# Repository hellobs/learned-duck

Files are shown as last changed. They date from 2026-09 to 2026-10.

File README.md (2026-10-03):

<div align="center">

# Learned Duck

**一台「被训练出来」的桌面蓝牙音箱**
*a desktop speaker that is **learned, not designed***

一条会发光的顶盖 · 一只黑色的眼 · 四条站得住的腿





</div>

<p align="center">
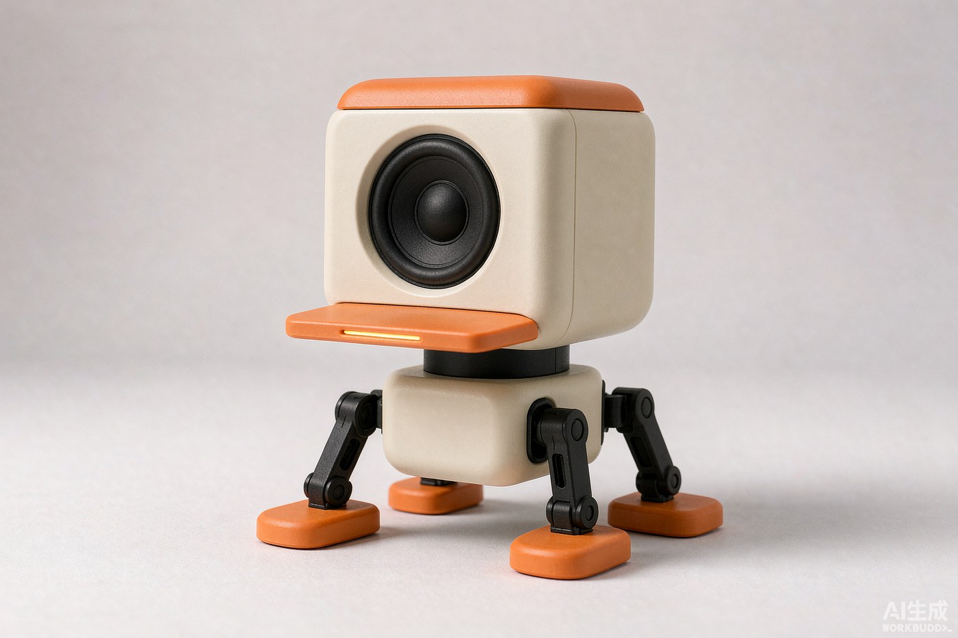
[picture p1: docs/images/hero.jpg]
Learned Duck
  
</p>

<p align="center"><sub>外观定稿 · 单喇叭版 · 暖奶油壳 ＋ 橙色顶盖与喙 ＋ 黑色四足</sub></p>

---

## 这是什么

Learned Duck 是一台可以放在桌面上的蓝牙音箱。它同时也是一个**完整的、可复现的 3D 打印产品设计项目**——从零件测绘、内部堆叠、外观建模，到打印参数、装配顺序、电路与固件，全部公开。

它的形态是一只抽象的小机器鸭：正面一只裸露的 52mm 全频喇叭充当唯一的「眼」，头顶一块橙色顶盖做成的浅托盘里，一条光带随音乐起伏（那是一条训练曲线，不是一张笑脸），四条带可见转轴关节的黑色机械腿把它从桌面上抬起来。

**它不是一个套壳的现成方案。** 所有零件都是从零开始测绘、从零开始排布、从零开始建模的。

---

## 为什么叫 Learned Duck

这个项目的形象取自 [**MicroDuck**](https://github.com/pollen-robotics/microduck)——Hugging Face 与 Pollen Robotics 合作的一只 25cm 四足机器鸭。

它最有意思的地方不在于外形，而在于：**它的动作不是被设计出来的，是被训练出来的。** 7 个步态策略全部由 MuJoCo 物理仿真 + PPO 强化学习习得，软件栈以 Apache-2.0 开源。

> *"It doesn't follow a script — every duck learns its own gait."*

这个项目把同一句话翻译成了产品语言：

> **形态是设计的，行为是被训练出来的。**
> *The shell is designed. The behavior is learned.*

所以它叫 Learned Duck —— 一只「学出来的」鸭。

### 致敬落点

| # | 落点 | 在实物上的体现 |
|---|---|---|
| 1 | **单眼即镜头** | MicroDuck 是一颗大圆镜头承担全部表情。本项目转译为**一只居中裸露的 52mm 喇叭**，黑色振膜就是眼珠，不做网罩遮蔽 |
| 2 | **喙的语言** | 一片扁平的哑光色件，根部与壳面齐平、向外渐增 2mm。它由「形」与「色」致敬，不靠加特效 |
| 3 | **彩色顶盖** | 头顶一块橙色顶盖，带一条干净的分型线与壳体分开——直接取自它的头部做法 |
| 4 | **一主一强一中** | 大面积中性壳体 + 小面积高饱和强调色 + 黑色结构件，比例约 6 : 3 : 1 |
| 5 | **四组配色** | 奶油 / 石墨 / 薰衣草 / 天蓝，色号照抄，不自行发明 |
| 6 | **骨架不遮不掩** | 颈、腿、髋支架、振膜全部外露，分型线不做无缝打磨 |
| 7 | **行为感** | 最见功夫的一处：**开机的第一段光纹由随机种子生成，每台机器都不一样** |

第 7 条来自它的一句设定——*每只鸭子第一次醒来都会获得自己的声音*。这里换成了光：**每一台 Learned Duck 第一次通电，都会生成一段只属于它的启动光纹，此后每次开机都重放同一段。**

### 出处标记

底壳激光刻有一行字：

```
trained, not designed
```

旁边留有一个 24 × 24 的平面区，用于激光补刻本仓库的二维码。

---

## 硬件清单 (BOM)

<details open>
<summary><b>点击展开 / 收起</b></summary>

| 类别 | 零件 | 规格 | 数量 |
|---|---|---|---|
| 主控 | ESP32-C3-Zero | 微雪 ESP32-C3FH4 | 1 |
| 音频 | 蓝牙功放板 | 立体声，12V 输入（自带蓝牙接收） | 1 |
| 音频 | 全频喇叭 | 2 寸，Ø52 方框法兰，4Ω 10W | 1 |
| 灯光 | WS2812B 灯板 | 5 × 5 = 25 颗，5050 封装 | 2（拼成 10 × 5） |
| 电源 | DC-DC 降压模块 | 迷你，固定 5V（峰值 3A / 持续 1.6A） | 1 |
| 电源 | DC022 电源插座 | DC5.5-2.1，带螺纹，开孔 Ø12 | 1 |
| 电源 | 12V 适配器 | **≥ 3A（建议 4A）** | 1 |
| 操作 | 拨动开关 | SS12F15V，2 档 3 脚 | 1 |
| 操作 | 金属按钮 | Ø10 自锁式 | 1 |
| 结构 | 热熔铜螺母 | M3×5×4.5 / M2×3×3 | 若干 |
| 结构 | 沉头螺丝 | M3×10（合壳、髋、腿）／ M2×10（前脸与外罩） | 若干 |
| 结构 | 丝杆 | M4 × 长（颈内脊柱） | 2 |
| 结构 | 冷轧钢板 | 60 × 40 × 3，约 56 g（配重＋功放散热） | 1 + 螺丝配重 |
| 辅料 | 闭孔泡棉胶条 | 宽 8，厚 2（喇叭法兰气封） | 1 卷 |
| 辅料 | 3M VHB 双面胶 | 4910 一类（粘灯板、粘橙灯框） | 若干 |
| 辅料 | 硅胶防滑脚垫 | Ø10 自粘 | 4 |
| 辅料 | 中性硅胶密封胶 | 封过线孔（声学腔唯一开口） | 1 支 |
| 辅料 | DIN 串联电阻 | 330 Ω（焊在灯板焊盘外 5–10 mm） | 1 |
| 辅料 | 导线 | 20AWG 硅胶线红/黑 各 1 m（12V 主线）；24AWG 镀锡跳线（其余） | 若干 |

</details>

> **注意**：原采购清单中没有 12V 电源适配器，需要单独准备。功放 12V 侧峰值约 2.0A、降压模块输入约 0.3A，合计接近 2.3A，**2A 的会掉压重启**，请备 **≥3A**。

> **螺丝长度是先算出来的，不是凑出来的。** 每个紧固点都要满足
> `杆长 ≥ 沉台深 + 各层壁厚 + 咬合（≥4 牙）`，
> 上限则是 `沉台 + 壁厚 + 螺母长 + 0.5~1.0` 间隙——杆尖顶死会撑裂塑料。
> 详见 [`docs/15_紧固件知识手册.md`](docs/15_紧固件知识手册.md)。

---

## 尺寸与结构

外壳为**四段式**结构：头 / 颈 / 身 / 四足。头身分离既是为了造型比例，也让喇叭腔和电路腔彻底解耦——这是声学与装配同时受益的一处设计。

<!-- ═══════════════════════════════════════════════════════════════
     图位 2 · 三视图（正 / 侧 / 俯）
     建议文件：docs/images/02-three-views.png
     ═══════════════════════════════════════════════════════════════ -->

> *[ 图位待放：正视图 / 侧视图 / 俯视图 ]*

| 段 | 尺寸 (mm) | 说明 |
|---|---|---|
| 头 | 96 W × 102 H × 62 D | 单只 52mm 喇叭居中外露（黑色振膜即眼珠）；橙顶盖做成灯托盘；前脸下部为橙色外框 + 一条浅入光窗 |
| 颈 | 高 26 | 外露黑色结构柱，内部穿 2 × M4 螺纹杆作金属脊柱；灯线、喇叭线由此下行 |
| 身 | 76 W × 52 H × 64 D | 电路腔：功放板 / ESP32-C3 / 降压模块 / DC 座 / 拨动开关 / 按钮；底部预留配重槽 |
| 四足 | 腿高 36，截面 20 | 髋支架从机身两侧兜住；两段式带定位齿盘关节；脚掌 40 × 32 |
| **总计** | **总高 ≈ 216** | 脚距 左右 128 / 前后 112 |

> **重要**：以上为**设计基准值**，正随零件实测数据迭代。已完成实测替换的版本记录在 [`docs/`](docs/) 中。

### 三个关键声学与结构决策

1. **声学后腔直接挖进前壳。** 不做独立内胆——前壳抽壳成碗，碗内净空就是后腔，后壳盖上的接缝内侧封一圈泡棉/热熔胶。头壳只有唯一一个开口（Ø10 过线孔，打胶密封），所以**唯一的密封风险面只有接缝一圈**，比拼装内胆少一整层误差。
2. **光在头顶，不在脸上。** 2 块灯板拼成 80 × 40，摆进橙色顶盖做成的浅托盘（外廓 92 × 52，墙高 10）。顶盖自带腔体，不需要另开光箱；**固件只点中间那一行 10 颗**，50 颗全亮点阵会读成散热片，一行光才是"设计语言"。灯与喇叭各走一侧线束，DIN 不与模拟音频并排。
3. **颈是悬臂梁，不是装饰柱。** 头上部约 255 g 全部压在颈上，而 FDM 打印件的层间剪切强度远低于层内。颈内穿两根 M4 螺纹杆承力，打印件只做外壳，且**必须横躺打印**。颈内径需 ≥ 20 mm，否则 2 根 M4 加 5 芯线束（喇叭 2 + 灯 3）挤不开。

---

## 电子架构

```mermaid
graph LR
    DC["DC022 插座<br/>12V 输入"] --> SW["拨动开关<br/>总 12V"]
    SW --> AMP["蓝牙功放板<br/>12V"]
    SW --> BUCK["DC-DC 降压模块<br/>12V → 5V"]
    BUCK --> ESP["ESP32-C3-Zero"]
    BUCK --> LED["WS2812B ×2<br/>50 颗（只点 1 行 = 10 颗）"]
    ESP -->|GPIO4 单总线 + 330Ω| LED
    AMP -->|喇叭线| SPK["52mm 全频喇叭"]
    BT(("手机蓝牙")) -.-> AMP
    BTN["Ø10 按钮"] --> ESP
```

| 部分 | 说明 |
|---|---|
| 音频链路 | 手机 → 蓝牙 → **功放板自己收**（ESP32 不参与音频）。功放独立取 12V，不经降压模块 |
| 为什么要这样 | ESP32-C3 在 Arduino 下跑 A2DP 会有缓冲抖动爆音，且会让手机同时看到两个蓝牙设备。本项目 ESP32 只管灯与按键 |
| 灯光链路 | 降压模块 5V 单独给灯板一路（不与 ESP32 共用细线，防数字噪声串进音频）；ESP32 用 **GPIO4** 出单总线 |
| 交互 | Ø10 按钮循环切换灯光模式；**拨动开关串在总 12V 最前端**，切断全机（不是只关灯） |
| 天线净空 | ESP32 天线端 10mm 范围内不得有金属、不得紧贴壳壁 |

### ⚠️ 电流限制（必读）

**降压模块的持续输出只有 1.6A**（铭牌峰值 3A 不代表能长期扛）。当前灯光只点亮中间一行：

| 亮度 | 10 颗电流 | 降压总负载 | 余量 |
|---|---|---|---|
| 120/255 | 0.28 A | 0.38 A | 4.2× |
| **180/255（当前上限）** | 0.42 A | **0.52 A** | **3.1×** |
| 满亮 255 | 0.60 A | 0.70 A | 2.3× |

> 这两条是硬约束，改之前先算：**① 一颗 WS2812B 全亮约 60 mA；② 若哪天让 50 颗全亮点亮，亮度上限必须收回 ≤ 120/255（约 1.2 A）。**
> 灯板电源单独走一路（24AWG 以内细线带不动数字噪声 + 电流），不与 ESP32 共用。

冷却：20W 功放封在约 0.2 L 的塑料腔里是**唯一可靠的散热路径**——钢板兼配重与散热片，功放贴钢板、钢板贴壳壁。

---

## 3D 打印与后处理

| 项目 | 参数 |
|---|---|
| 材料 | **PETG**（韧性优于 PLA，耐温约 70℃） |
| 层高 | 外壁 0.16–0.18 mm，内部 0.24 mm |
| 壁 / 填充 | 壁 3 圈；顶底 6 层；填充 20–25%（**腿、颈、髋支架 45%**） |
| 打印方向 | **腿必须侧卧**、**颈必须横躺**——让层纹垂直于受力方向 |
| 外观面 | 朝上、避开支撑；头壳建议后壳朝下、正面朝上 |
| 配合公差 | 配合面留 0.3 mm |
| 热熔螺母柱 | 柱外径 M3 ≥ Ø7.0 / M2 ≥ Ø5.5，柱高 ≥ 螺母长 + 1，柱身加 3–4 条纵向加强肋 |

**后处理（这一步比任何造型改动都更影响成品档次）**

1. 趁热压入热熔铜螺母（250–260℃）
2. 打磨 400 → 800 → 1500 目
3. 补土填平层纹明显的区域
4. 底漆 → 晾 12h↑ → 哑光面漆 → 晾 24h↑

---

## 装配顺序

完整步骤见 [`docs/17_电路系统设计与接线.md`](docs/17_电路系统设计与接线.md)。核心顺序由三条规则锁定：

> **① 能单独做完并测过的，绝不合起来做。**
> **② 整机在装配过程中必须始终能平躺。**
> **③ 前壳与后壳一合上，手就伸不进头里了** —— 所有线必须在合后盖之前插好放到位。

```
01  台面测试一：功放 + 12V 电源 + 两只喇叭接起来，通电出声（音频最难，先闭环）
02  台面测试二：ESP32 + 降压 + 两块灯板，先单颗亮、再两块串联
03  身部装配：钢板 + 导热垫 + 功放板组件 → DC 座 / 开关 / 按钮 → 合身上盖
04  穿颈线：喇叭线与灯线分两侧穿过颈（颈内径 ≥ 20 mm），接上身
05  头顶：灯板摆进顶盖托盘（同心配合定位）→ 从盘底往上拧 M3×10
06  头内：腔内装电路 → 前脸装喇叭（4 颗 M2×10 从正面拧）→ 压泡棉环 → 扣橙外罩
07  腔内拧：4 颗 M2×10 从后口伸进去锁外罩 → 过线孔打胶封（唯一开口，不能漏气）
08  合后盖 → 四腿调平、贴防滑垫、烧录固件、收线
```

**四个最容易翻车的地方**（都用规则化解在顺序里了）：合壳时夹住线 → 声学腔漏气；竖着打的腿 → 沿层断裂；先装腿后装电路 → 螺丝刀伸不进去；灯泡没在台面测过就进壳 → 要拆整个后盖。

---

## 灯光系统

### 当前实现（v0.1）

三种灯光模式，由按钮循环切换：**待机呼吸** / **音乐律动** / **流光扫描**。

### 预留的可选基础

这些接口已经**在设计上留好位置，但当前版本不实现**——目的是让日后扩展只需新增，不必返工：

| 预留项 | 现在怎么做 | 日后怎么加 |
|---|---|---|
| **模式表架构** | 固件中已建立 `{名称, 函数指针}` 模式表，表里只填 3 项 | 加模式＝写一个函数 + 表里加一行 |
| **个体化启动光纹** | NVS 中已预留 `seed` 字段，当前写死固定值 | 把那一行改成随机数生成，启动光纹即变成每台唯一 |
| **腿部姿态** | 关节已做成 12 档定位齿盘（30°/档），**可手动摆放** | 刻姿态对齐线 + 调预压，即可摆出「站 / 坐 / 趴」 |
| **舵机驱动** | 轴孔 Ø3.2 已按此基准设计 | 改用舵机时，轴孔即安装基准 |
| **二维码** | 底壳内侧预留 24 × 24 平面区 | 激光补刻，无需重新建模 |

---

## 开发里程碑与提交节奏

这个仓库**不设定时推送**——每完成一个里程碑就提交、推送一次，不留尾巴。
里程碑边界（也是提交边界）：

| 里程碑 | 范围 | 状态 |
|---|---|---|
| M1 · 测绘与基准 | 零件测绘表、尺寸基准表、采购补件清单 | ✅ |
| M2 · 造型定稿 | 单喇叭居中＋橙顶盖＋短喙＋四足；概念图与三视图 | ✅ |
| M3 · 结构与堆叠 | 五腔分述、机构详图、13 件打印清单 | ✅ |
| M4 · 外观建模 | 前壳 P1／后壳 P2／外罩 P14／顶盖 P3／紧固件标准件 | ✅ |
| M5 · 灯光与电路定稿 | 顶盖灯箱、灯板安装、螺丝配对体系、电路系统与接线 | ✅ 本提交 |
| M6 · 打印件出图 | 全套打印参数、切片、后处理与公差复核 | 待开始 |
| M7 · 装配与调试 | 打印后处理、电路焊接、总装、调平、成品记录 | 待开始 |
| M8 · 出图与归档 | 三视图／剖视图／爆炸图／件号表 | 待开始 |
| M9 · **v1.0** | 强化学习步态（舵机版，MuJoCo + 仿真训练） | 路线上 |

提交信息格式：`前缀: 一句话`（`cad:` 零件模型 ／ `docs:` 文档 ／ `chore:` 杂项），
按主题拆成小提交，不把无关改动揉在一起。

---

## 路线图

- [x] 零件测绘与尺寸基准
- [x] 造型方案定稿（单喇叭居中 + 橙顶盖 + 短喙 + 四足）
- [x] 内部堆叠与机构详图
- [ ] 按实测值更新全部尺寸基准
- [ ] SolidWorks 建模（外壳 12 件）
- [ ] 打印试件验证（喇叭沉台 / 合壳搭接唇 / 齿盘）
- [ ] 全套打印与后处理
- [ ] 电路焊接与调试
- [ ] 总装、调平、成品记录
- [ ] 出图：三视图 / 剖视图 / 爆炸图 / 件号表
- [ ] **v1.0** — 强化学习步态（舵机版，MuJoCo + 仿真训练）

---

## 已知限制

诚实记录，避免误导：

- **单声道。** 单只喇叭居中做「眼」，放弃了立体声声像。第二只喇叭可藏入身内向下发声，但会挤占电路腔容积，当前版本未采用。
- **关节是静态的。** 齿盘可在有限档位内手动摆放，但**不能自主运动**。真实可动需要舵机，属 v1.0 范围。
- **满亮超载。** 见上文电流限制一节。
- **尺寸仍在迭代。** 部分标注为设计基准值，待零件实测数据替换。
- **无倒相孔。** 采用密闭箱设计，低频下潜有限——这是 2 寸单元在小体积下的物理限制，不是设计缺陷。

---

## 仓库结构

```
.
├── README.md                     项目说明（你现在读的这份）
├── LICENSE                       硬件设计 · CC BY-NC-SA 4.0
├── LICENSE-CODE                  固件代码 · MIT
│
├── docs/                         设计文档
│   ├── 01-零部件测绘表.md         测量方法与清单
│   ├── 02-零件尺寸基准表.md       尺寸数据与出处 —— 建模唯一数据源
│   ├── 03-内部结构分析.html       五腔分述 · 受力路径 · 装配顺序
│   ├── 04-喙尺寸图.html          单一零件的完整工程定义
│   ├── 05-内部堆叠与机构详图.html  堆叠 · 机构详图 · 打印件清单
│   ├── 09_采购补件清单.md          缺件与补件（含 12V/3A 适配器）
│   ├── 10_外盖P14定义.md           外罩背面热熔螺母与对接口
│   ├── 11_灯光（LED）方案评估.md    三轴空间账 · 亮度与电流上限
│   ├── 12_灯板安装.md               固定方案 · 330Ω · GPIO4 · 走线
│   ├── 13_橙灯框P15与浅入灯位.md    前脸灯框与浅入量
│   ├── 14_螺丝与热熔螺母配对体系.md 每个紧固点的三层孔与杆长
│   ├── 15_紧固件知识手册.md         选型、头型、防松、SW 操作铁律
│   ├── 16_顶盖灯箱方案（LED上置）.md LED 移到头顶托盘
│   ├── 17_电路系统设计与接线.md     架构 A · 电源树 · 14 条接线 · 建模留位
│   └── images/
│       └── hero.jpg             外观定稿渲染
│
├── cad/                         CAD 模型（尚未上传）
│   └── README.md                导出约定与打印方向
└── firmware/                    固件（尚未提交）
    └── README.md                接口设计说明
```

> **刻意没有放进来的东西。**
> 外观探索的 21 版过程渲染、个人实施计划与作业单、课程材料，以及内部工作记录——它们对「复现这台音箱」没有价值，所以不占仓库体积。
>
> 取舍只有三条：**能复现的进，过程稿不进，别人的材料不进。**

---

## 许可

完整条款见 [`LICENSE`](LICENSE)（硬件）与 [`LICENSE-CODE`](LICENSE-CODE)（固件）。

本项目采取**分开授权**（硬件与代码属性不同）：

| 部分 | 建议许可 |
|---|---|
| 硬件设计（CAD、图纸、文档） | CC BY-NC-SA 4.0 |
| 固件代码 | MIT |

> 选择 NC（非商业）是因为这是一个课程设计作品；若你打算商业使用，请先联系作者。

---

## 致谢

- **[MicroDuck](https://github.com/pollen-robotics/microduck)** — Hugging Face × Pollen Robotics。本项目的形态语言与行为概念全部源于它。若你喜欢这只鸭，请去给原项目一个 star。
- **MuJoCo / PPO** — 让「行为可以被学出来」成为可能的那套工具。
- 华南理工大学设计学院 · 计算机辅助工业设计

---

<div align="center">

*The shell is designed. The behavior is learned.*

**trained, not designed**

</div>

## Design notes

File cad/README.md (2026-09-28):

# cad/ · CAD 模型

此目录存放 SolidWorks 导出的可交换格式模型，供他人直接打印或继续编辑。

## 当前状态：尚未上传

建模正在进行中。**尺寸基准依赖零件实测数据**，见 [`../docs/01-零部件测绘表.md`](../docs/01-零部件测绘表.md)。

## 规划结构

```
cad/
├── step/         可编辑实体（按件号）
├── stl/          打印用网格（按件号）
└── assembly/     整机装配体
```

打印件共 12–13 件，编号 P01–P12，清单见
[`../docs/05-内部堆叠与机构详图.html`](../docs/05-内部堆叠与机构详图.html)。

## 导出约定

| 项 | 约定 |
|---|---|
| 单位 | mm |
| 坐标系 | Z 轴朝上，原点在机身**底面中心** |
| STEP | AP214 |
| STL | 二进制，弦高公差 0.02 mm |
| 命名 | `LD-P01-head-front.step` |

## 打印方向（重要）

导出前请确认模型的**默认朝向即打印朝向**：

- **腿** —— 侧卧（让层纹垂直于受力方向）
- **颈** —— 横躺
- **头壳** —— 后壳朝下、正面朝上

竖着打的腿和颈会在装配时沿层断裂。

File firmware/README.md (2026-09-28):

# firmware/ · 固件

ESP32-C3-Zero（ESP32-C3FH4）的 Arduino 固件。

## 当前状态：尚未提交

固件在总装阶段编写。当前已确定的只有**接口设计**——目的很明确：**日后要扩展，只需新增，不必返工。**

## 计划结构

```
firmware/learned_duck/
├── learned_duck.ino    主程序
├── modes.h             灯光模式表 {名称, 函数指针}
├── audio.h             音频输入与律动
└── config.h            亮度上限、引脚定义
```

## 已确定的设计约束

| 项 | 值 | 原因 |
|---|---|---|
| 全局亮度上限 | **≤ 120 / 255** | 50 颗 WS2812B 全白满亮约 3.0 A，而降压模块额定只有 3 A |
| 灯阵供电 | 单独走一路 | 不与 ESP32 共用 24AWG 跳线 |
| 天线净空 | 天线端 10 mm 内无金属、不贴壳壁 | 否则蓝牙与 WiFi 直接衰减 |
| 开发环境 | Arduino IDE + ESP32-C3 开发板库 | 课程要求 |

## 预留接口（当前不实现）

刻意留好的三个「接缝」，成本极低，但让 v1.0 可以纯增量开发：

| 预留项 | 现在怎么做 | 日后怎么加 |
|---|---|---|
| **模式表架构** | 建 `{名称, 函数指针}` 表，先只填 3 项 | 加模式 = 写一个函数 + 表里加一行。主程序、按钮逻辑、限流全部不动 |
| **NVS `seed`** | 预留字段，当前写死固定值 | 改成随机生成 → 启动光纹即变成每台唯一 |
| **腿部姿态** | 关节按 **12 档定位齿盘**设计，可手动摆放 | 刻姿态对齐线即可；改用舵机时轴孔 Ø3.2 就是安装基准 |

## 灯光模式

当前实现三种，由 Ø10 按钮循环切换：**待机呼吸** / **音乐律动** / **流光扫描**。

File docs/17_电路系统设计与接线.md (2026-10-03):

# 电路系统：拓扑 · 电流 · 接线 · 装配

> 创建：2026-10-02 23:45
> 触发：用户「头壳建模差不多了，准备考虑电路部分」
> 前置：`16_顶盖灯箱方案` 已把灯搬到头顶 → 头的电路从「一条脸上的光带」变成「头顶→颈→身 的三段走线」，
> 本文按**头顶方案**（灯在顶盖托盘）写；若改回前脸 P15，§3.2 的走线路径可缩短约一半，其余不变。

---

## 0. 一句话状态

**结构件建完了，电路一行没动。** 好消息是电路不该等结构 —— 它必须**先在台面上跑通**，再进壳。
本文把「电路这个东西在这台机器里长什么样」一次讲透：拓扑 → 电流 → 每根线 → 颈里的空间 → 装配顺序 → 坑。

---

## 1. 拓扑：先想清楚一件事 —— ESP32 管音频吗？

这是整个电路**唯一需要先拍板**的架构问题，而且它现在在文档里有歧义。

| | 蓝牙功放板 | ESP32-C3 |
|---|---|---|
| 会不会自己收蓝牙 | **会**（清单写的"蓝牙功放板"） | 也会（但你不打算用） |
| 拉到手上的角色 | **音频链路的实际承担者** | 只管灯和按键 |

**清单里那块是「蓝牙功放板，10W/15W/20W 立体声，12V 输入」—— 它自带蓝牙接收器。**
也就是说：手机 → 功放板（板自己连蓝牙）→ 功放 → 喇叭，这条链路**根本不经过 ESP32**。
ESP32-C3 的价值只在于 **WS2812 灯 + 按键**。

### 1.1 两条路，差别很大

| | 方案 A：**功放自制蓝牙**（推荐，最省事） | 方案 B：ESP32 当音频源 |
|---|---|---|
| 链路 | 手机 ⇄ 功放板 → 喇叭 | 手机 ⇄ ESP32 →（A2DP/I2S）→ 功放 → 喇叭 |
| 代码量 | 灯：一个 NeoPixel 循环 | 灯 + 蓝牙 A2DP + I2S + 缓冲管理（几天量级） |
| 风险 | 低 | **高**：ESP32-C3 的 A2DP 在 Arduino 下不稳，缓冲抖动会爆音 |
| 副作用 | ⚠️ 手机会看到**两个蓝牙设备** | 只有一个 |
| 讲评 | 课程是建模课，别把硬件课的量加进来 | 见 `MEMORY.md`「课程定位修正」 |

**推荐 A。** 你这门课是建模课，电路是"让它亮、让它响"的及格线，不是主战场。

### 1.2 ⚠️ 方案 A 必付的代价：两个蓝牙

手机搜索蓝牙会同时出现：
- 功放板广播的（名字常是 `XY-xxxx` / `BT-……`，看板子贴纸）
- ESP32-C3 的（烧了固件后你自己在代码里 `ESP.restart()` 前的默认名，或 `WiFiSoftAP` 之类）

**后果**：每次开机，用户要在这两个里挑对的那个连。老师/同学拿起来试，极可能连到 ESP32 上，发现"连上了没声音"，直接判失败。

**三条处理，按性价比排：**

1. **不烧 ESP32 的蓝牙**（默认就没烧）→ 它开例程之前就是个裸板，不会出现在蓝牙列表。**最省事，几乎零成本。**（默认 ESP32-C3 不烧任何程序时确实不广播，这也是推荐 A 的又一条理由）
2. 烧固件时把 ESP32 名字起成 `LD-LAMP`（明确不是音箱），并在 README 写一句。
3. 别去改功放板名字（要看板子有没有 AT 指令口）。

> **先确认一件事再往下做：你手上那块蓝牙功放板有没有 AUX（3.5mm）输入口？**
> 有 → 方案 A 稳；只有 BT 一种输入 → 也一样能走方案 A（本来就不需要它转接给 ESP），
> 但你要知道"信号从哪进" —— 若它只有 BT，那 ESP32 与功放之间**没有任何信号线**，只有 GND 关系（§4.3）。

---

## 2. 电源树与电流预算（重算）

### 2.1 树形

```
12V 适配器（自备 / 待购）
  └─→ DC022 电源座（开孔 Ø12，装在身部下沿，靠下 = 力臂最短）
        └─→ 拨动开关 SS12F15V（★ 装在 12V 总线最前端，切断总电源）
              ├─【支路 1 · 直通 12V】→ 蓝牙功放板 → 1× 喇叭（4Ω 10W，**单声道**）
              └─【支路 2 · 经降压】→ DC-DC 降压模块（12V → 5V，持续 1.6A）
                                      ├─→ ESP32-C3（5V，~0.1A）
                                      └─→ WS2812 灯板（5V，见下表）
金属按钮（Ø10，面板）→ ESP32 GPIO → 灯模式 / 开机自检
```

**开关的位置是关键**：拨动开关串在**进入全机的 12V 总线最前端**，不是串在灯支路。
关机 = 全机断电（功放也停），不是"只关灯"。这也符合"拨动开关是电源总开关"的常见直觉。

### 2.2 电流（按头顶方案「只点中间一行 10 颗」算，这是新的账）

| 支路 | 典型 | 峰值 | 说明 |
|---|---|---|---|
| **功放 + 喇叭（12V 侧）** | 0.3–0.8 A | **≈ 2.0 A** | 20W 输出 / 12V / 效率 ~85% → 24W 输入 ≈ 2A |
| 降压输入（12V 侧） | 0.15 A | 0.3 A | 输出 ~0.5W ÷ 效率 0.9 ÷ 12V |
| ESP32-C3 常态 | 0.1 A | 0.2 A | Wi-Fi 瞬时更高 |
| 灯 10 颗（头顶方案） | 0.28 A | 0.6 A | 单颗 WS2812B 满白 60mA；亮度 120/255 ≈ 47% |

**合计 12V 侧 ≈ 2.3 A（峰值）→ 适配器 12V/3A 起步（2A 太紧，别赌）。**

### 2.3 一个好消息：亮度上限那条铁律，头顶方案下解除了

`02`/`12` 定「亮度 ≤120/255」，是因为原来要带 50 颗甚至 75 颗。
**头顶只点 1 行 = 10 颗 → 0.28A @120/255。**

| 亮度 | 10 颗电流 | 降压总负载（含 ESP） | 对 1.6A 余量 |
|---|---|---|---|
| 120/255 | 0.28 A | 0.38 A | **4.2 倍余量** |
| 180/255 | 0.42 A | 0.52 A | 3.1 倍 |
| 255（满） | 0.60 A | 0.70 A | 2.3 倍 |

**结论：头顶单行方案下，你可以放心把亮度上限放宽到 180/255**（曲线更好看、更"发光"），
1.6A 的持续限仍有 3 倍余量。
> 除非你哪天又让 50 颗全亮 —— 那必须回到 120/255。

### 2.4 两个不能碰的电源规矩

1. **功放吃 12V 直供，不经过降压。** 降压只喂数字侧（ESP + 灯）。反过来（灯从 12V 直取再降）会有纹波串进音频。
2. **灯板 5V 从降压模块「单独引一路」**（用 2 根线直接连降压的两个输出邮票孔），**不要和 ESP32 共用一条 24AWG 跳线** —— 长距离共用会把数字开关噪声带进 ESP 的供电。

---

## 3. 走线路径（头顶方案的真正代价）

### 3.1 三条线，两个方向

| 线 | 起点 → 终点 | 经过 |
|---|---|---|
| **① 喇叭线**（2 芯） | 功放（身） → 喇叭（头正脸） | 身 → 颈 → 头内 → 前脸背面 |
| **② 灯线**（3 芯：5V/GND/DIN） | 顶盖灯盘（头顶） → ESP32（身） | 顶盘壁槽 → 头内 → 颈 → 身 |
| **③ 电源/控制**（可选） | DC 座 + 开关 + 按钮（身） | 全在身，不走头 |

**关键时间窗：头壳（P1↔P2）一旦合上，① 和 ② 就必须已经接好、并塞到位 —— 之后手伸不进去了。**
所以「穿线」这一步必须在**合 P2 之前**完成（跟之前定的装配顺序一致）。

### 3.2 ⚠️ 颈 P7 里的空间账（这是本次新算出来的，之前没人算）

灯跑到头顶之后，**颈里同时要过 ① 喇叭线（2 芯）和 ② 灯线（3 芯）= 5 芯线**，
外加结构上的 **2 根 M4 螺纹杆**。

```
颈内径 D。2 根 M4（Ø4）贴内壁走：
  中间净宽 = D − 8        （两根杆各占一侧 4mm）
判据：净宽 ≥ 12  →  D ≥ 20
```

| 颈内径 | 中间净宽 | 结论 |
|---|---|---|
| ≥ 22 | ≥ 14 | ✓ 宽裕 |
| **20** | **12** | ✓ 刚好够（这就是「≥12mm 净宽」这条老规矩的来源） |
| < 20 | < 12 | ❌ 要改：单根 M4 居中（占 4）+ 一侧走线，或颈内径放大 |

**进 SW 建 P7 之前先量：颈的内径是多少。** 若算出来 < 20，只有两条路：
- M4 从 2 根减到 1 根（脊柱够不够强度另说，颈是压柱不是拉柱，1 根居中其实可行）；
- 颈内径从原设计放大 2mm（颈是外露视觉件，放大 2mm 会改视觉比例 —— 这是造型账，得你拍）。

> 顺带：这 5 芯里 **①喇叭线是模拟音频、②灯线是高速数字**，
> **不能贴着并排走同一侧**（DIN 的方波会在喇叭线上感生底噪）。
> 走法：**灯线走颈的一侧、喇叭线走另一侧**（正好和两根 M4 各占一边对齐），
> 到头内/身内再分别拐向自己的目标。

### 3.3 过线孔（三处，每处都要硅胶封）

1. **顶盖托盘侧壁 Ø10 过线槽**（灯线出盘）—— 若盘壁还没开，现在开还来得及（P3 还没打）。
2. **头底 → 颈 的 Ø12 孔**（① ② 都从这里下到颈）—— 别撞 DC 座那个孔（DC 座在身部下沿）。
3. **颈 → 身**（在同一区域，用线卡固定在颈内壁，别让它晃）。

> 声学腔唯一的开口仍是 P1 上那个 **Ø10 过线孔**（喇叭线从功放进前脸背面用的），
> 必须硅胶封死 —— 这是 `05` 的老规矩，别把它和上面三处混。

---

## 4. 接线表（照着焊）

### 4.1 12V 侧

| # | 从 | 到 | 规格 | 备注 |
|---|---|---|---|---|
| 1 | DC022 中心针（+） | 拨动开关 脚 1 | 20AWG 硅胶，短 | ⚠️ 见 §4.4 线径 |
| 2 | 拨动开关 脚 2 | 功放板 12V+ | 20AWG，走身底 | 直通 |
| 3 | 拨动开关 脚 2 | 降压模块 IN+ | 20AWG，短 | 与 2 同点分叉 |
| 4 | DC022 外壳（−） | 功放板 12V− / 降压 IN− / 开关 脚3 | 20AWG | 三处**同一个地** |
| 5 | 功放板 OUT L | 喇叭（成品里唯一的那一只） | 24AWG 可，≥20AWG 更好 | 走颈 |
| 6 | 功放板 OUT R | **不接（悬空）** | — | ⚠️ **只接一路。两路并到同一只喇叭 = 4Ω∥4Ω = 2Ω，功放会过流保护甚至烧** |
| 7 | 拨动开关 脚 3 | （悬空 / 或不接） | — | 拨动只当单刀单掷用 |

> **DC022 是「中心正、外壳负」**（常见）；极少是中心负。**插之前拿万用表量一下**，
> 接反了功放会烧（有保护的好一些，没有的直接废）。

### 4.2 5V / 数字侧

| # | 从 | 到 | 规格 | 备注 |
|---|---|---|---|---|
| 8 | 降压 5V+（邮票孔） | 灯板 VCC | 24AWG 软硅胶，**单独一路** | 见 §2.4 |
| 9 | 降压 5V+ | ESP32 5V | 24AWG | 同上分叉点 |
| 10 | 降压 GND | 灯板 GND | 24AWG | |
| 11 | 降压 GND | ESP32 GND | 24AWG | **与 8/9 同一个地** |
| 12 | ESP32 **GPIO4** | 灯板 DIN | **软硅胶 22AWG + 串 330Ω** | 焊在 DIN 焊盘外 5~10mm |
| 13 | ESP32 GPIO（按钮） | 金属按钮 一脚 | 软线 | |
| 14 | 按钮 另一脚 | ESP32 GND | 软线 | 按钮另一端接 GND = 按下拉低 |

**GPIO 选哪个：用 GPIO4。** 别用 0/2/3/9/10（上电 strapping 脚）、1/3（UART0）。

### 4.3 关于"共地"到底共哪一处

| 网络 | 接法 |
|---|---|
| 12V 地（电源负极） | DC022 外壳 → 功放 −、降压 IN−、开关脚3，全是一点 |
| 5V 地（数字地） | 降压 OUT− → ESP32 GND、灯板 GND，全是一点 |
| **两地的连接** | **降压模块的 IN− 与 OUT− 本身在模块内部就是连通的**（DC-DC 是共地拓扑）→ 所以两个地**自动是一点**，不用你额外连 ✅ |

⚠️ 但你**必须确认降压模块是「非隔离」DC-DC**（你这块就是，双邮票孔 mini 降压都是非隔离）。
如果是隔离型（很少见），IN− 和 OUT− 不连，那时 5V 地的回路要靠别处走，会出问题。

### 4.4 ⚠️ 线径：24AWG 用在 12V 主线上太细

清单里只有 **24AWG 镀锡跳线（1007 双头）**，载流大约 2A 上限（ chassis wiring 级），
而 12V 峰值要 **2.0A**、且路径里有 DC 座 → 开关 → 功放的接头。24AWG 会**发热 + 压降**。

**采购一行：20AWG 硅胶线（红/黑各 1 米）+ 热缩管。** 只用在 #1~#4 这 4 根（12V 总线）。
其余（5/8~14）24AWG 完全够。

---

## 5. 建模上还要留什么（给 SW 的清单）

电路进了身腔，身 P8/P9 要留：

| 件 | 留什么 | 数 |
|---|---|---|
| 功放板（50.2 长 / 33×30 / 高 14.5） | 坐在钢板上（钢板 60×40×3，兼散热板）；底部 3 个 M3 凸台或直接用导热硅胶垫贴 | 散热 |
| ESP32-C3（23.5×18） | **贴后壁立装，天线端朝外，10mm 内不得有金属与壳壁** | 硬约束 |
| 降压模块（22.3×17×2） | 贴壁，两颗 M2×5 自攻或热熔螺母都行（它不受力） | |
| DC022（Ø12） | 开孔 + **孔内侧加线夹槽**（防插拔力直接拉焊点） | |
| 拨动开关（SS12F15V） | 侧板开方孔 + 螺母；装在身侧 | |
| 金属按钮（Ø10） | 面板开 Ø10 | |
| 配重钢板 60×40×3 | 底部浅槽（兼散热，功放贴它） | |

**线卡/走线槽**：身内壁要有一圈浅槽（≥4mm 深）放 12V 总线，不然线会堆在功放板上盖不住上盖。

---

## 6. 装配顺序（电路部分）

```
① 台面测试 1（今晚就能做，不依赖任何壳件）
   功放板 + 12V 电源 + **1 只喇叭**接线 → 通电听声（蓝牙连上、有声音 = 音频链路通）
   ⚠️ 单声道：功放只接 OUT L，OUT R 悬空。别两路并到一只喇叭（变 2Ω，过流）
② 台面测试 2（灯）
   降压 12→5 + ESP32 + 两块灯板（先分开测单颗 → 再串联）→ 烧亮度 180/255 看 10 颗亮 = 灯通
③ 身部装配：钢板 → 功放 → 降压 → ESP32 → DC 座 → 开关 → 按钮 → 理线
④ 合身上盖（此时电路全在身里）
⑤ 穿颈线：① 喇叭线、② 灯线 各从颈的一侧放下去（灯线一侧 / 喇叭线一侧，别并排）
⑥ 头内装灯板（先）→ 扣顶盖托盘（框压灯）→ 前脸装喇叭（4 颗 M3 从正面拧）
   → 橙外罩压上 → 腔内拧 4 颗 → 过线孔硅胶封
⑦ 合 P2 后盖（合上就再也伸不进手了）
⑧ 全机通电：蓝牙连功放（不是连 ESP）→ 声音 → 灯随音乐 → 按钮切模式
```

> **① ② 绝不能跳。** 装进壳再发现灯不亮/没声音，要拆整只头。

---

## 7. 七个坑（按会让你返工的程度排）

1. **⚠️ 颈内径 < 20 → 5 芯线 + 2 根 M4 塞不下**（§3.2）。建 P7 前先量，这是硬约束。
2. **⚠️ 蓝牙有两个设备**（§1.2）。默认不烧 ESP 蓝牙最省事。
3. **⚠️ 灯线和喇叭线在颈里要分两侧走**（DIN 方波感生底噪）。
4. **DC022 极性**：中心正还是中心负，接之前量。
5. **24AWG 上 12V 主线**（§4.4）：买 20AWG。
6. **ESP32 天线 10mm 净空**：贴死壳壁 = 蓝牙直接废，这是最容易在装配最后才发现的问题。
7. **功放散热**：20W 封在 0.20L 塑料腔里，钢板 + 导热硅胶垫是唯一可靠出路；别指望自然对流够。

---

## 8. 待定 / 待购

| # | 事项 | 状态 |
|---|---|---|
| 1 | 12V 适配器（≥3A） | ❌ **不在采购清单里**，自备或补购（最急） |
| 2 | 20AWG 硅胶线 红/黑 各 1m + 热缩管 | ❌ 补购 |
| 3 | 330Ω 电阻（1/4W） | ❌ 补购（几毛钱，但没它灯会误触发） |
| 4 | 导热硅胶垫（功放 → 钢板） | ❌ 补购 |
| 5 | 硅胶封过线孔（3 处 + Ø10） | ❌ 补购（或热熔胶应急） |
| 6 | 拨动开关装在身侧哪个面、按钮装哪 | ⏳ 待定（造型账） |
| 7 | 颈 P7 内径 | ⏳ 待建，先量 |
| 8 | 功放板有无 AUX 输入 | ⏳ 待看实物 |
| 9 | 亮度上限 180/255（头顶单行） | ⏳ 待拍（我建议放开到 180） |

---

## 9. 下一步（就三件事）

1. **今晚做台面测试 1**：功放 + 12V 电源 + **1 只喇叭**，通电有声音 = 最难的一段（音频）先闭环。
2. **明晚做台面测试 2**：ESP32 + 降压 + 灯板，先单颗亮、再两块串联。
3. **顺手量两个数**：颈 P7 内径（判 §3.2 塞不塞得下）、功放板有没有 AUX 口（定 §1.1 架构）。

这两个台面测试**不依赖任何打印件**，是现在唯一能真推进的事。
逐步操作手册见 `18_台面接线手把手.html`（含每步判据、停手点与故障排查表）。

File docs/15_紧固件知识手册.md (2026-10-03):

# 15 · 紧固件知识手册

> 起因：2026-10-02 晚，连续几轮讨论（热熔螺母配什么螺丝、凸台装不下 M3 沉头、孔该开多大）
> 暴露出一件事——**项目里所有"孔"和"螺丝"的错，根子是同一套知识没建立。**
> 这份手册把紧固件从零梳理一遍，最后落到本项目的速查表。
> 项目应用（哪处用哪颗、为什么改 M2）见 `14_螺丝与热熔螺母配对体系.md`，本文不重复。

---

## 0. 先建立一条主线：四个问题，按顺序问

做任何一处紧固，问完这 4 个就有答案了，剩下的都是查表：

```
① 这个面看得见吗？        → 决定头型（沉头 / 还是内六角别拧上来）
② 壁够厚吗？              → 决定沉台能不能开、螺母能不能埋
③ 螺纹从哪来？            → 直接成型 / 热熔螺母 / 自攻 / 线套
④ 螺丝够长吗？            → L ≥ 沉台 + 各层壁厚 + 咬合
```

**绝大多数失败，是第 ② 条和第 ④ 条没算**——不是料不够，是不知道要多少。

---

## 1. 家族地图：先分清这 5 样东西

| 类 | 中文 | 英文 | 本质 | 本项目有没有 |
|---|---|---|---|---|
| **机丝** | 机器螺钉 | Machine Screw | 拧进**已有的螺纹孔**（母材或螺母），不自己攻牙 | ✅ M2 / M3 |
| **自攻钉** | 自攻螺钉 | Self-tapping Screw | 自己**挤/切**出螺纹，拧进预制光孔 | ❌ 没买，但值得知道 |
| **螺栓** | 六角螺栓 | Bolt | 粗杆 + 六角头，通常**配螺母**夹紧两件 | ❌ 只有颈接口那 2×M4 是准这个用法 |
| **热熔螺母** | 热熔铜螺母 | Heat-set Insert | 压进塑料里的**内螺纹基座** | ✅ M2×3×3 / M3×5×4.5 |
| **热熔螺柱** | 热熔螺柱 / 凸台 | Heat-set Standoff | 一体式「定位柱 + 内螺纹」，压进去 | ❌ 没买 |

### 1.1 最容易混的一对：机丝 vs 自攻

| | 机丝（Machine screw） | 自攻钉（Self-tapping） |
|---|---|---|
| 拧进什么 | **现成的螺纹孔** | 一个光孔，边拧边攻 |
| 螺纹截面 | 三角牙（等边） | 尖牙 / 三角牙带刃口 |
| 拧进去要不要导引 | 要（孔得对） | 不要，它自己开路 |
| 拧出后还能再拧吗 | ✅ 可以反复 | ⚠️ 孔会被自己攻大，几次就松 |
| 用在哪 | **所有可拆的、要反复拆的地方** | 一次性封死、不打算拆的地方 |

**判据一句话：要能拆、能反复拧 → 机丝 + 螺母。 一次性的、薄料封口 → 自攻钉。**

塑料件上自攻钉还能干一件热熔螺母干不了的事：**料太薄（<1.5mm），热熔螺母的孔比料还厚**——这时候自攻钉从正面钻进去，靠挤压力咬住，是唯一解。代价是拧两三次孔就松了。

---

## 2. 型号怎么读

### 2.1 螺丝：`M3 × 10 · 沉头 · 十字 · 粗牙`

| 段 | 读什么 | 影响什么 |
|---|---|---|
| **M3** | 螺纹公称直径（杆径） | 决定**杆孔**多大、配哪个螺母 |
| **10** | **杆长（不含头高）** | 决定够不够长。**买的时候标的这个数就是杆长** |
| 沉头 | 头型 | 决定**沉台**多大、表面凸不凸 |
| 十字 | 槽型 | 十字（电批好拧）/ 一字（老件）/ 内六角（扭矩大、头部小） |
| 粗牙 | 螺距 | 粗牙（标准，M3=0.5）抗振、好拧；细牙密封好、可调预紧 |

> ⚠️ **"M3×10"里的 10 不含头。** 一条 M3×10 沉头，总长 = 10 + 1.65 ≈ 11.65。
> 算长度账的时候用 10（杆），别用 11.65，也别用 8.15 当总长。

### 2.2 热熔螺母：`M3 × 5 × 4.5`

顺序和螺丝**不一样**，先 M3 后 length 再外径：

| 段 | 值 | 含义 |
|---|---|---|
| **M3** | 内螺纹 | → 只能配 M3 螺丝 |
| **5** | 长度（有效螺纹） | → **螺丝杆最多只能吃进去 5mm** |
| **4.5** | 本体大径 / 滚花外径 | → 决定**安装孔打多大** |

**它不决定螺丝头型。** 螺丝头型是被连接件上那个**沉台**定的（见 §3）。

### 2.3 安装孔（这一步才归螺母管）

**孔深公式（比死记数字可靠）：**

```
孔深 = 螺母长度 L_nut + 0.5 ~ 1.0
孔底必须留 ≥ 0.5 实料
```

| 螺母 | 长度 | 孔径 | **孔深** |
|---|---|---|---|
| **M2×3×3** | 3 | Ø3.0 | **3.5** |
| **M3×5×4.5** | 5 | Ø4.2~4.4（推荐 4.3） | **5.5** |

> **本项目 P1 凸台怎么对上这个公式：** 凸台高出脸面 5.5，顶端先开沉台 1.2，
> 沉台底再往下打盲孔 4.3 —— **1.2 + 4.3 = 5.5，两段之和正好等于凸台高**（凸台是从脸面长出来的实心台，没有多余料）。
> 盲孔净深 4.3 里埋长 3 的 **M2×3×3**（公式要求 3.5），富余 1.3 ✓。

**过盈量：塑料件用 0.03~0.08 mm / mm 直径**（M3 取 0.2~0.4 总过盈）。
- 过盈太小 → 压进去会转、会松；
- 打满 Ø4.5 → 过盈为零，铜螺母套进去一动就滑圈。

---

## 3. 头型全景（★核心：头型由沉台决定）

### 3.1 主流头型对照

| 头型 | 标准 | M2 头径/头高 | M3 头径/头高 | 表面状态 | 用在哪 |
|---|---|---|---|---|---|
| **开槽沉头** | GB/T 68 | 4.0 / **1.2** | 5.5 / **1.65** | ✅ 与面齐平 | 外表面（正脸） |
| **半沉头** | GB/T 69 | ≈4.0 / ≈1.2 | ≈5.5 / ≈1.65 + 圆顶 0.2~0.3 | ✅ 微凸一点 | 外表面（**本项目手上有货**） |
| 盘头（十字） | GB/T 65 | 4.0 / 1.5 | 5.5 / **1.8** | ❌ 头顶是拱的 | 腔内、被别的件盖住的 |
| 圆头 | GB/T 67 | 4.0 / 1.6 | 5.5 / 2.0 | ❌ 凸 | 同上 |
| **内六角圆柱头** | GB/T 70.1 | — | 5.5 / **3.0** | ❌ **凸 3.0** | **腔内承重**（髋、腿关节） |
| 六角头 | GB —— | — | — | ❌ 凸 | 配螺母的夹紧连接 |

### 3.2 三条反直觉的点（这三条吃过多亏）

**① 沉头的头径，远比你以为的大。**
90° 锥面决定了头径 = 1.8~2.1 × 杆径：

| 杆 | M2 | M3 | M4 | M5 |
|---|---|---|---|---|
| 沉头头径 | **4.0** | **5.5** | **8.4** | 9.3 |

M4 沉头头径 **8.4mm**——比杆径大一倍多。这不是标错，是 90° 锥角的几何后果。

**② 所以：薄板上开沉台，会打穿。** ← 这是第 ② 个问题（壁够厚吗）的来源

判据：

```
沉台深度 ≤ 板厚 − 0.5（底要留实料）
沉台半径 + 最小边距 ≤ 可用半宽
```

- 前脸 2.5 厚，开 M2 沉台 1.2 → 剩 1.3 ✓
- 前脸 2.5 厚，开 M3 沉台 1.65 → 剩 0.85，勉强；**再薄一档就废**
- 顶开 Ø5.5 沉台，而凸台只有 Ø5.5 → **整个顶面被挖穿，壁厚归零** → 这就是 `14` §5 那个"杯子凸台"的成因

**③ 沉台宁浅 0.1~0.2，不可深 0.5。**
- 挖浅了：螺丝头顶在孔口沉不下去 → **被连接件被顶起 1.2mm**（本项目 `10` §12 就是这么栽的：法兰被顶起 → 泡棉压不实 → 漏气）
- 挖深了：正面凹一个坑 → 只有外观代价

**所以正确的因果链是：**

```
螺丝头型号 → 需要多大的沉台(Ø/深) → 沉台开在哪个面 → 开得下吗 → 正面能藏住吗
```

螺母只在这一链的最末：给你个能拧的螺纹。

---

## 4. 长度与咬合（第 ④ 个问题）

```
螺丝杆长 L ≥ 沉台深 k + 螺丝穿过的所有壁厚 Σt + 咬合长度 n
```

- **n（咬合长度）**：螺距 × 4 牙保险。M3 螺距 0.5 → n ≥ 2.0；想要牢就 3.0
- **L 是杆长，不含头**
- 上限：见 §4.2 —— **杆尖后面是空的完全正常**；真正的上限是「别顶穿对面壳 / 别顶死螺母孔底」。

### 4.1 本项目三处算账

| 用途 | 沉台 k | 壁厚 Σt | 咬合 n | 最少 L | 结论 |
|---|---|---|---|---|---|
| **合壳 P1↔P2** | 1.65（在 P2） | P1 2.5 + P2 2 = 4.5 | 2.0 | **8.15** | M3×10 ✓ 富余 1.85 |
| **喇叭法兰** | 1.2（M2） | 脸 2.5 + 凸台（自孔） | 3.0 | **5.4** | **M2×10 富余 2.6** ✓ |
| **橙外罩 P14** | — | 脸 2.5 | 3.0 | **6.7** | **M2×10** ✓（M2×8 富余 1.3，太险） |

> **教训沉淀：三个位置得出同一个答案 M2×10 —— 不是巧合，是这三处都是"薄壁正面藏头"，薄壁本来就喂得饱 M2。**

### 4.2 ★ 杆尖后面（沿螺丝方向）还有很多空间，合适吗？

**一句话：合适，而且是常态。只要空间在「杆尖的那一头 / 杆尖之下」，就没有任何问题。**
塑料壳里几乎不存在「螺丝拧到底还顶着实料」的正常设计——真顶上了，通常是出事了。

先分清你说的"空间"在哪一段（三种完全不同）：

| 空间位置 | 判据 | 结论 |
|---|---|---|
| **① 杆尖之后（末端下面）是空腔** | 杆尖离任何硬面 ≥ 0.5~1.0 mm | ✅ **完全合适**，这就是本节要说的 |
| **② 杆的中段周围是空腔**（螺丝穿过一个大腔） | 杆是刚体，中段没支撑不影响受力 | ✅ 无所谓，**更不影响** |
| **③ 杆尖顶到硬底**（对面壳壁 / 螺母孔底 / 另一个零件） | 越拧越紧、拧不到头 | ❌ **顶死**：塑料会被撑裂、螺纹滑牙、热熔螺母被顶歪（这就是 §2.3 要求孔底留 0.5~1.0 实料的原因） |

**L 的真正上限（不是"别超过螺母长度"，这个说法是错的）：**

```
L_max ≈ 沉台深 k + 螺丝穿过的所有壁厚 Σt + 热熔螺母长度 n_螺母 + 间隙 0.5~1.0
```

超过 L_max 才是"太长"；在 L_max 以内，**杆尖后面剩多少空间都行**。

#### 两个反直觉的点

**(a) 承力几乎全在最前面几牙。** 螺母螺纹的载荷分布：第 1 牙吃 ~30~40%，前 3~4 牙吃掉 ~70~80%，再往里的牙基本不受力。
→ 所以「杆尖后面还有一大截空腔」不但无害，反而**说明没有顶死风险**；
→ 反过来，螺丝杆在螺母里**只咬了 1~2 牙**（L 太短）才是要命的——那种一拧就滑、还容易把热熔螺母带转。

**(b) 咬合长度 ≠ 螺丝杆长。** `M3×10` 的 **10 是杆长**；咬合长度只有杆穿过被连接件之后、真正和螺母螺纹重叠的那一段（≥4 牙 = M3 的 2.0mm）。
买螺丝时你支出的"长度"里，绝大部分是**穿壁厚 + 悬空浪费掉的部分**，只有末尾 2~3mm 在干活。

#### ⚠️ 唯一的特例：自攻钉不能悬空

**机丝（配螺母）杆尖悬空 = 好事；自攻钉杆尖悬空 = 装不上。**

自攻钉没有螺母，它靠杆身自己把塑料挤出螺纹（切削/滚压），所以**杆尖必须先进进料里**才能一路攻过去。
判据反了：自攻钉要求 `L ≥ k + Σt + 攻入深度(≥2~3 牙)`，且杆尖**必须落在实心料上**，落进空腔 = 攻不到底、螺丝松、孔被撑大。

> 所以"能不能留空间"这个问题，**机丝看的是"别顶死"，自攻钉看的是"必须顶到料"** —— 正好相反。

#### 4.2.1 本项目三处复核（都是"杆尖悬空"，都合适）

| 用途 | 螺丝 | 沉台+穿壁 | 杆尖进螺母 | 螺母长 | 杆尖距孔底 | 结论 |
|---|---|---|---|---|---|---|
| 喇叭法兰 | M2×10 | 1.2+2.5 = 3.7 | 6.3 | 3.0 | **~3.3 悬在腔里** | ✅ 不顶死 |
| 橙外罩 P14（腔内拧） | M2×10 | 1.2（腔侧沉台） + 穿脸 2.5 + 穿盖 4 | 咬合 3.0 ≈ 螺母长 3.0 | 3.0 | 杆尖正好到螺母底，**塑料孔底还留 0.5~1.0 实料** | ✅ 不顶死塑料 |
| 合壳 P1↔P2 | M3×10 | 1.65+4.5 = 6.15 | 3.85 | 5.0 | **~1.15** | ✅ 勉强不顶死 |

> 合壳那颗最紧：杆尖离热熔螺母孔底只剩 1.15mm。**别再往上加长**（M3×12 在这里就危险了）——
> 这也是为什么 §4.1 里合壳算出来是 M3×10 而不是更长的规格。

#### 4.2.2 装配后一眼自检

拧到底之后，从后口（或任何能看见杆尖的角度）看一眼：
- 杆尖**没顶到任何东西**、螺丝头能完全沉进沉台 → 合格；
- 螺丝头沉不下去 / 拧到一半就"到底了" → **L 超了**，换短一号，不是换大一号。

---

## 5. 塑料件里的螺纹：5 种方案怎么选（★本项目的战场）

3D 打印塑料件上要一个螺纹孔，有 5 条路：

| 方案 | 做法 | 最小壁厚 | 可拆次数 | 成本 | 推荐度 |
|---|---|---|---|---|---|
| **① 直接成型** | 打印时就把螺纹打出来 | ≥ 2× 螺纹大径 | 3~5 次后滑牙 | 0 | ⭐⭐ 薄件/非受力 |
| **② 热熔螺母** | 压入内螺纹嵌件 | ≥ 外径 × 0.7 单边（M3 需 ≥1.6） | 多次 | ¥0.05/颗 | ⭐⭐⭐⭐ **本项目主力** |
| **③ 自攻钉** | 从正面钻进光孔自己攻 | 很薄也行（≥0.8） | 2~3 次孔就松 | 有 | ⭐⭐ 一次性封口 |
| **④ 自攻螺母** | 带尖牙的嵌件，拧进光孔（不用加热） | 同② | 多次 | 略贵 | ⭐⭐⭐ 不想带热熔枪时 |
| **⑤ 线套（Helicoil）** | 不锈钢线卷的螺纹套，拧进预丝孔 | 同② | 多次（可修复） | 贵 | ⭐ 修复/高受力 |

### 5.1 选型判据（按顺序判）

```
壁厚 T:
  T ≥ 2.0mm 且 不拆/少拆        → ① 直接成型（零成本）
  T ≥ 1.6mm 且 要拆/受力        → ② 热熔螺母 ← 本项目几乎所有点
  T < 1.6mm                     → ③ 自攻钉 / ④ 自攻螺母 / 干脆用胶+销
  T 很薄 + 完全不想加工         → 用 VHB 胶体 + 圆销定位（见 `12` §2 方案 C）
```

### 5.2 直接成型螺纹的真实参数（PETG）

- 孔打印时**比标称大 0.1~0.2**（PETG 收缩 + 挤出量波动）
- 最小螺纹壁厚（牙顶到零件外沿）**≥ 0.75 × 螺距 × 2** → M3 需 ~1.5mm 实料
- 强度大概是热熔螺母方案的 **1/3**，拧 3~5 次牙就圆了
- **热熔螺母是花 5 分钱换"永远能拆"**，塑料件上几乎永远值得

---

## 6. 压入件工艺（热熔螺母/螺柱）

| 环节 | 做法 | 坑 |
|---|---|---|
| 工具 | 电烙铁 / 专用热熔枪（配对应尺寸压头） | **别用打火机/喷枪** —— 铜导热快，塑料会熔过头发焦 |
| 温度 | 电烙铁头**贴住螺母端面** 2~3 秒，别一直烤 | 烤久了螺纹孔壁塌、孔径变小，螺丝拧不进 |
| 润滑 | 螺母端面薄薄一层硅油/黄油 | 干压容易卡死在半路 |
| 到位 | 压到**端面与孔口齐平**即可，别再往下捅 | 捅过头 = 背面凸出 = 干涉相邻件 |
| 冷却 | **静置不动到完全冷却**（≥30s） | 塑料软的时候一碰就歪，歪了没法救 |
| 检验 | 冷透后手扭不转、螺丝能沉到底 | 见 §7 |

**压歪了怎么办：** 只有一条路——往里挪 1mm 把孔填平重打。**别硬掰、别补胶再压。**

---

## 7. 防松（什么时候才需要）

塑料件 + 桌面物件，95% 的情况**不会振松**。只有这 4 种情况要防：

| 情况 | 对策 |
|---|---|
| 会振动 / 会被敲（腿关节、髋） | 尼龙锁紧螺母（Nylock，带尼龙环）/ 螺纹胶 |
| 要频繁拆装 | 别用胶（拆一次就废），用尼龙螺母 |
| 孤单颗、受力大 | 螺纹锁固胶 Loctite 243（中强度，可拆）+ 手工扭矩 |
| 完全不想动 | Loctite 2701（低强度，永久）或热熔胶点封 |

**该知道的三个坑：**
1. **弹垫（弹簧垫圈）在塑料上完全无效** —— 它是为金属刚度设计的，塑料会被压平，等于没垫。
2. **平垫有用**：增加承压面、防止沉头把塑料表面挤出毛边。塑料件上值得加。
3. **尼龙螺母不能用在 >80°C**，PETG 件上没问题。

---

## 8. 失效图鉴：8 种坏法 + 一眼对策

| 现象 | 原因 | 对策 |
|---|---|---|
| **螺丝头浮在表面、沉不下去** | 沉台挖浅了 / 头型选错（M3 头塞 M2 沉台） | 挖深沉台 0.2~0.3，**或换对头型** |
| **被连接件被顶起一截（不严）** | 同上，螺丝头顶在沉台底/孔口 | 沉台开到能让头顶进去；这是本项目泡棉漏气事故的根源 |
| **塑料件开裂 / 凸台崩了** | 沉台直径 ≥ 凸台直径（壁厚归零） | 换小一号螺丝 / 加粗凸台 / 沉台开到对面的面上 |
| **拧两三次就滑牙转圈** | 直接成型螺纹太薄 / 孔打太大 | 埋热熔螺母 |
| **热熔螺母会转（不随螺丝转）** | 过盈不够 / 孔打大了 | 孔收 0.1mm 重打 |
| **拧不进去、越拧越卡** | 孔径小了 / 螺母歪 / 烤过头孔壁塌了 | 孔扩 0.2；**换位置重打**，别撬 |
| **螺丝杆拧到底就顶死、拧不动** | 太长，杆尖顶到螺母底 | 换短一档（本项目 M2×8 vs M2×10 就是这条线） |
| **孔口出现裂纹（放射状）** | 孔距边太近（< 2× 壁厚） | 孔位外移；热熔螺母尤其会放射裂 |

> **判据记住两条：**
> ① **沉台底到背面留 ≥ 0.5 实料**；
> ② **孔心到边 ≥ 沉台半径 + 1.5**（热熔螺母尤其，它压进去会往外撑裂）。

---

## 9. SolidWorks 里怎么把这些孔做出来

### 9.1 一个固定点 = 三层同心孔（别混成一层）

| 层 | 给谁 | M2 | M3 |
|---|---|---|---|
| **③ 沉台** | 螺丝头 | Ø4.0 × 深 1.2 | **Ø5.5 × 深 1.65** |
| **② 杆孔（直孔）** | 螺丝杆 | Ø3.0 | **Ø3.2~3.5**（M3 杆齿顶 ≈2.76） |
| **① 螺母安装孔** | 热熔螺母 | Ø3.0 × 深 3.5 | **Ø4.3 × 深 5.5** |

**必须开在正确那一面：**
- 螺丝头在**外表面**（腔内拧进来）→ 沉台开在**外表面**
- 螺丝头在**腔内**（从外表面拧进去）→ 沉台开在**腔侧**

### 9.2 异型孔向导（Hole Wizard）

| 向导要什么 | 选什么 |
|---|---|
| 机丝 + 要藏头 | **沉头孔 Countersink**（GB/T 68 对应） |
| 机丝 + 手上有半沉头 | **半沉头（GB/T 69）**，自定义 |
| 只想要光孔、不要螺纹线 | **套合 = 松弛**，别选「螺纹孔 Tap」 |
| 给螺母的安装孔 | **直孔 Straight**（不是螺纹孔！） |

**四条操作铁律（本项目踩过的）：**
1. **向导把沉台开在「放置面」那一侧** → 想让沉台在腔内，就必须**从腔侧选放置面**。从正面放 = 沉台开到正面，被外盖压住，装配才发现。
2. **改了规格（M3→M2），自定义框会重置** —— 每次都要回头把孔直径手打回 3.00 之类的值。
3. **孔终止条件按用途选**：给螺丝杆的 → **完全贯穿**；给螺母的 → **给定深度**（贯穿了螺母压进去就是个环，白打）。
4. **装配体里没有异型孔向导** —— 要么进零件里做（配合会带外部参考），要么手动两步切除 + 断外部参考。

---

## 10. 本项目速查表

### 10.1 全项目紧固件总表

| 固定点 | 螺母 | 螺丝 | 头型 | 拧向 |
|---|---|---|---|---|
| 喇叭法兰 ×4 | M2×3×3 | **M2×10** | 沉头/半沉头 | **从正面拧**（头被橙外罩吃掉） |
| 橙外罩 P14 ×4 | M2×3×3 | **M2×10** | 沉头/半沉头 | **从腔内往里拧** |
| 橙灯框 P15（退路） | M2×3×3 | M2×10 | 沉头 | 优先 VHB + 圆销（见 `13` §3） |
| 合壳 P1↔P2 ×4 | M3×5×4.5 | **M3×10** ✓现成 | 沉头/半沉头 | 从 P2 侧（背面露头正常 ✅） |
| 髋/腿关节 ×8 | M3×5×4.5 | M3×10 / M3×12 | 内六角也行（看不见） | 腔内 |
| 颈接口 P7 ×2 | **M4 热熔螺母**（未买） | M4×?? | 沉头 | 全头唯一主受力 |
| 灯板 | — | **胶体 + 2 圆销** | — | 不拧（`12` §2 方案 C） |

### 10.2 三层孔速查

| 位置 | 沉台 | 杆孔 | 螺母孔 |
|---|---|---|---|
| P1 喇叭凸台 | Ø4.0×深1.2（在凸台顶） | Ø3.0 | Ø3.0×深4.3（总深 5.5 ← 含沉台） |
| P1 前脸（接橙外罩） | Ø4.0×深1.2（**腔侧**） | Ø3.0 贯穿 | — |
| P14 橙外罩（贴脸面） | — | — | **4×Ø3.2×深3.0**（盲） |
| P2 后盖 | Ø5.6/5.0 沉头（已打） | Ø3.3 通 | — |

### 10.3 采购写法（写全 4 项，缺一项就发错）

```
M2 × 10   沉头 GB/T 68   十字槽   粗牙
```

| 规格 | 数量 | 用途 |
|---|---|---|
| **M2×10 沉头/半沉头** | **≥10**（8 用 + 2 损耗） | 法兰 4 + 外罩 4 + P15 退路 2 |
| M3×10 沉头/半沉头 | 已有 ✓ | 合壳 / 髋 / 腿 |
| M3×12 | 4 | 髋轴锁紧 |
| M4 沉头 + M4 热熔螺母 | 各 2~4 | 颈接口 P7 |

> ⚠️ 手上的 **M3×5（200粒）和 M2×5（500粒）都不够长**（法兰需 8.5、合壳需 8.15），
> **别往前壳上凑**，留着填配重槽是它们最好的归宿。

---

## 11. 术语速查（中 / 英 / 本项目的口语）

| 中文 | English | 备注 |
|---|---|---|
| 机丝 / 机器螺钉 | Machine screw | M2/M3 小螺丝 |
| 自攻螺钉 | Self-tapping screw | 会自己攻牙 |
| 沉头螺钉 | Countersunk screw | 90° 锥头，可沉入 |
| 半沉头螺钉 | Semi-countersunk / oval head | 半球顶 |
| 盘头 / 圆头螺钉 | Pan head / Round head | 凸出来 |
| 内六角圆柱头 | Socket cap screw (ISO 4762) | 凸 3mm，腔内承重 |
| 热熔螺母 / 铜螺母 | Heat-set insert | 本项目 M3×5×4.5 |
| 热熔螺柱 / 凸台 | Heat-set standoff | 柱 + 螺纹一体 |
| 滚花 | Knurl | 螺母外圈那道网纹 |
| 沉台 / 沉孔 | Counterbore（直）/ Countersink（锥） | ⚠️ 两个英文词别用反 |
| 过盈配合 | Interference fit | 螺母压进孔靠它 |
| 咬合长度 | Engagement length | 螺丝杆吃进螺母的长度 |
| 尼龙锁紧螺母 | Nylock nut | 带尼龙防松环 |
| 螺纹锁固胶 | Threadlocker | Loctite 243 / 2701 |
| 线套 / 钢丝螺套 | Wire thread insert (Helicoil) | 修复螺纹用 |
| 间隙孔 / 退刀孔 | Clearance hole / Drill hole | 光孔（不攻牙） |
| 底孔 | Tap drill | 攻丝前的钻孔 |

> ⚠️ **Countersink（锥沉台，90°）≠ Counterbore（柱沉台，直筒）**，
> SW 异型孔向导里两个按钮是分开的，选错孔型打出来螺丝头坐不住。

---

## 12. 压螺母前后各 5 分钟自检

| 时机 | 动作 | 合格标准 |
|---|---|---|
| 压前 | 卡尺量螺母**外径** | M3×5×4.5 → 4.5 ± 0.2 |
| 压前 | 试拧一颗螺丝进螺母 | 自由旋入 2~3 圈不打滑（确认螺距一致） |
| 压前 | 量孔深 | = 螺母长 + 0.5（M3 → 5.5，底留 0.5 实料） |
| 压后 | 看端面 | 与孔口齐平、背面不凸 |
| 压后 | 试拧到底 | 螺丝能**完全沉进沉台**、头面与面齐平或略低 |
| 压后 | 手扭 | 不转（过盈够） |

**任何一条不过 → 填平往里挪 1mm 重打，别凑合压。热熔螺母歪一个，那一处就永远歪。**

---

## 13. 一句话沉淀

> **看得见的面 → 沉头 + 沉台 + 热熔螺母（正面藏头）**
> **看不见的面 → 内六角柱头，别折腾沉台**
> **薄壁（<2.5）→ 用 M2，别硬塞 M3**
> **长度永远先算再买，别拿手上的凑**

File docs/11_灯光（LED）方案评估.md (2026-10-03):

# 11 · 灯光（LED）方案评估：笑脸装不装得下

> 起因：2026-10-02 晚，用户在正脸橙罩下方用红笔圈了两个矩形（= 拟放 2 块 WS2812B 灯板），
> 问「把灯板做成笑脸表情合理吗」。
> 本文结论：**技术上笑脸做得出，但在这个头部尺寸里装不下。造型上也不建议。**

---

## 1. 结论先行

| 问 | 答 |
|---|---|
| 能把灯板做成笑脸吗 | **能**（2 块并排 = 10 列 × 5 行，50 颗；**只要用中间 3 行就够读出脸**） |
| 灯板 39×39 放得下吗 | **放下**（v3 订正：Z 轴深 ~50，灯摆哪儿都行，X/Y/Z 三轴都不卡） |
| 这个头部装得下吗 | **装得下**（v3 复核：之前"差 5 倍"是判错了） |
| 造型上建议吗 | **仍是"不建议"，但理由换了** —— 不再是尺寸，是三件事：**① 要 32 的光口就得砍喙；② 30 颗孤立光点像贴了块屏；③ 从「一只眼 + 一条喙」掉回「一张脸」** |
| 推荐替代 | **横向光带 = 一条"训练曲线"**，零改结构、零改造型、主题更自洽 |

> **本文的演进过程（重要，别看丢）**
> - v1（20:35）判"装不下，光口差 5~10 倍"。**判错了** —— 错在把"灯阵需要 30mm"当成了硬阻塞。
> - v2（20:50）订正为"装得下"，但**判据仍错**（拿"能不能塞进"当"能不能读出来"）。
> - v3（2026-10-02 20:45，**本文当前版本**，用户指出"那里只有 32，头部有 50"后重算）：
>   **灯板装得下（Z 轴 50，随便摆）；笑脸也读得出（只要 3 行，中心跨度 15.6 ≪ 32）。**
>   尺寸这一关，完全通过。剩下的全是造型取舍（喙要不要、点阵要不要），见 §2.6 / §2.7。

---

## 2. 硬尺寸：光口根本不是"脸"的尺寸

### 2.0 所有相关尺寸（已核对 `03` / `04`）

| 项 | 值 | 出处 |
|---|---|---|
| 灯板单片 | 39 × 39 × 2.8，5×5 = 25 颗 | 实测笔记 |
| LED 中心距 | 39 / 4 ≈ **7.8 mm** | 推得（非实测，建模前须量） |
| 2 块并排 | **78 宽 × 39 高**，50 颗，10 列 × 5 行 | 已定 |
| 光腔内腔 | **120 × 42 × 12** | `03` |
| 喙面光缝 | **96 长 × 6 高**（内凹 2，贴前缘下沿） | `03`；`04` 另写 3 **两处不一致，见 §9** |
| 橙外罩 68×68 | 盖心 = 眼心 (0,+16) → **Y 占 −18 ~ +50** | `10_外盖P14定义` |
| 正脸范围 | **Y +51 ~ −51**（头 102 高） | 已定 |

### 2.1 灯这边有多少像素

| 项 | 值 | 来源 |
|---|---|---|
| 灯板单片 | 39 × 39 × 2.8，5×5 = 25 颗 | 实测笔记 |
| 可用块数 | **2 块**（头内宽 91，2 块 78 可行；3 块 117 放不下） | 已定 |
| 拼成 | **78 宽 × 39 高**，共 50 颗 | |
| 像素排布 | **10 列 × 5 行** | |
| LED 中心距 | ≈ **8~9 mm**（39 宽排 5 点） | 39 / 4 估 |

→ 要让人读出「两眼 + 一条嘴」，至少要用 **4 行像素**，对应高度 ≈ 4 × 8 ≈ **30 mm**。
再保守一点，整块点亮区就是 **39 mm 高**。

### 2.2 口那边开了多大

| 项 | 值 | 来源 |
|---|---|---|
| 喙面可见光缝 | **长 96（喙宽 × 0.8~1.0）× 高 3~6** | `03-内部结构分析.html`、`04-喙尺寸图.html` |
| 光缝做法 | 内凹 2、贴前缘下沿、距下沿 1 | `04` |
| 喙面板 | 100 × 29 × 7，前伸 10、下倾 6° | 已定 |

→ **口高只有 6 mm。**

### 2.3 订正：39×39 本身不是瓶颈，我之前判错了

v1 说"差 5~10 倍"，错在两处，现在纠正：

**错误一：光口可以比灯板小。**
灯在腔里、光从缝出（手机背光原理）。所以"光口 33 vs 灯板 39 差 6mm"根本不是冲突，
这是光箱的标准做法 —— 光口永远取小于灯板的尺寸，靠上下沿遮光边把多余的光切掉。

**错误二：5 行灯的中心跨度是 31.2mm，不是 39mm。**
5 颗灯的中心从第 1 行到第 5 行只跨 4 个间距：4 × 7.8 = **31.2 mm**。
灯板 PCB 实体是 39 高，但**会发光的只有那 31.2mm**。

### 2.4 重算垂直预算：33mm 光口，塞得下 5 行灯

正脸 Y 从 +51 到 −51（102mm），从上往下排：

| 段 | Y 范围 | 高 | 占什么 |
|---|---|---|---|
| 头顶 | +51 ~ +50 | 1 | 橙顶盖分型线余量，**锁死** |
| 橙外罩 | +50 ~ −18 | 68 | 必须包住方兰 52.6，**锁死** |
| **下部净空** | **−18 ~ −51** | **33** | ⬅ 光与喙只能分这一块 |
| 其中：喙（P4） | 29 | | 若要保喙，光只剩 **4mm** |

**结论：保喙 → 光口 4mm（一条线）；砍喙 → 光口 33mm。**

33mm 光口放 5 行灯：灯中心跨度 31.2mm 居中 → 上下各留 **0.9mm 挡光边**。
**几何上成立。** 再加遮光边做到各 2mm，光口净出光 31mm，灯中心正好铺满。

所以：**技术上，把光缝从 96×6 改成 78×33 的下沉光窗，笑脸是做得出的。**

### 2.5 订正（v3，2026-10-02 20:45）：算错的是「需要几行」，不是「放不放得下」

用户指出：「那里只有 32，但是头部有 50」。核对后，**两个维度，互不冲突**：

| 轴 | 值 | 能不能卡人 |
|---|---|---|
| X（宽） | 内腔 **91**（96 − 2×2.5） | 灯板 78 ✓ 不卡 |
| Y（高） | 橙外罩底 −18 ~ 内腔底 −48.5 = **30.5**（用户实测 32） | ⬅ **唯一卡人的轴** |
| Z（深） | 头深 62 − 壁 5 = **57**，实测约 **50**（余 7 被横杆/三角板占） | 灯板 2.8 厚 ✓ 完全不卡 |

**结论一（采纳用户意见）：灯板放得下，任何轴都不卡。** 50 是深度，它给的是
「灯摆在哪儿都行」的自由度 —— 灯板可以贴后壁、可以往里退，位置随便。

**结论二（我自己第二次算错）：v2 说「33mm 塞得下 5 行灯」理由讲错了。**
真正判据不是"能不能塞进"，是**正前视线可见性**：
正前方平行看进去，只看得见 ±(光口高/2) 范围内的灯。
- 5 行灯中心跨度 **31.2mm** → 要全看见，光口必须 ≥ **31.2**。30.5~32 勉强够（余量 0.5~2）。
- 但笑脸根本不需要 5 行 —— **2 行（眼+嘴）就能读出脸，3 行是舒适值**。
  3 行中心跨度 = 2 × 7.8 = **15.6mm** → 光口 32 上下各留 **8.2mm 遮光边**，宽裕得很。

**所以几何上：笑脸完全做得出。** 做法 = 灯板贴光腔后壁，
**只用中间 3 行出光（固件把最外两行点灭 + 上下腔壁遮 3.5mm）**。
v1 说"差 5 倍"是彻底错的，v2 说"能装下"结论对但判据错，v3 的判据在上面。

### 2.6 仍然成立的真代价（不是尺寸，是造型）

光口要 32 = 橙外罩底(−18) 一路吃到内腔底(−48.5)：

| 代价 | 数 |
|---|---|
| **喙（P4）** | 喙 29 高 + 光口 32 = 61 > 33 → **喙必须取消或整个外移到脸下沿之外** |
| 正脸发光占比 | 下部 **~64%** 变发光面，奶油面只剩左右两条竖边（各 9mm） |
| 近看 | 3 行 × 10 列 = 30 颗孤立光点（不扩散）→ 点阵屏感；扩散 → 3 行糊成光带，**脸又没了** |

**扩散悖论不在"能不能做"，在"做完读出来是什么"**：
不扩散是 30 个点（像贴了块小屏），扩散是 3 行糊成一条光带（脸没了）。
3 行这个中间态，两头都不讨好 —— 但它是**造型取舍**，不再是尺寸死结。

### 2.7 真死结：扩散悖论（这是我不建议的真正原因）

33mm 光口 / 5 行灯，只能二选一：

| | 结果 | 脸？ |
|---|---|---|
| **灯不加扩散**，光口里直接看 10×5 的 LED | 每颗 Ø5、间距 7.8 → **缺口 2.8mm** | ❌ 看着是"50 个孤立光点排成的网格" |
| **加亚克力/乳白扩散板**（`03` 原方案里有这一条：2–3mm 扩散板） | 5 行糊成一片连续光斑 | ❌ 脸没了，就是一条粗光带 |

**这是个死结，不是取舍：**
- 要"读出一张脸" → 每颗灯边界必须可辨 → 但 10×5 低分辨率下，嘴在第 3~4 行中间 6 颗 → **只能是直线，画不成弧**；
- 要"好看、像雕塑" → 必须扩散 → 扩散后五行合并，**脸没了，回到光带**。

**33mm 这个中间态最糟：不扩散 = 点阵屏，扩散 = 光斑，两头不占。**
（对比：6mm 光缝的反而是干净解 —— 它诚实地只出一条线。）

而你已经定死的判据（2026-09-28）：**不要卡通比例、不要彩虹 RGB、要雕塑体量、唯一一处发光。**
一个 78×33 的发光方块贴在脸下半，读起来是"一块小屏幕"，
比那条 96×6 的光缝低一个版本 —— 光缝是"工业物的一处光"，方窗是"玩具上装了屏"。

第六条还要提醒：砍掉喙 = 砍掉六条设计语言里的「喙的语言」（形 + 色两处落点）。

### 2.6 还有一条完成度红线（v1 保留，仍然成立）

上一届的完成度红线里有一条：**「喇叭与造型功能统一，而非贴上去」**。

如果直接把两块 39×39 的 PCB 贴在正脸下方那片奶油面上：
- 正脸下部会多出两个**带焊盘、带排针、带板边的高 IT 黑方块** —— 这是"贴上去"的教科书案例；
- 而且下面还有个 39 mm 高的方块要塞进只有 8 mm 的净空，物理上就错。

**灯只能藏在光腔里，从光缝出来。这条从一开始就定死了，别破。**

---

## 3. 就算硬做，笑脸也会是"表情包脸"

10 列 × 5 行、LED 直径 5mm 的 LED 点阵，物理下限就是表情包分辨率：

- 嘴在这块网格上只能是一条**直线**（5 行里第 3~4 行中间 6 颗），画不成弧；
- 两眼在第 2 行 col 3 / col 8，距 8 格 ≈ 64mm，间距够，但圆点直径 5 相对行距 8 → **糊**；
- 结论：出来的是「− ‿ − 直线嘴」这类 8bit 表情，**不是雕塑**。

而你已经定死了的审美判据（2026-09-28 用户反馈"概念图太丑"后确立）：
**不要多色撞色、不要彩虹 RGB、不要卡通比例；要单色哑光、雕塑体量、唯一一处发光。**

一个笑脸 = 直接命中"卡通"这一条。而且它会和**喇叭这只眼**打架：
现在正脸是「一只眼（喇叭）+ 一条喙」，读起来是工业物；加上笑脸就成了「眼睛 + 嘴巴 = 一张脸」，
**直接掉回"做成小鸭一点都不出彩"那一堆里。**

---

## 4. 推荐方案：光带 = 一条「训练曲线」

不动任何一件已定稿的东西（光腔 84×42×18、光缝、喙、外罩全部不变），
把"表情"从**造型**这件事上挪到**固件**上：

### 4.1 形态

- 灯板 2 块并排横放进光腔（78 < 84 ✓，39 < 42 ✓），**灯面朝前**，与后腔用隔墙断开（这条已定，不变）；
- 光缝 96 × 3~6 是唯一出口 → 出来的是**一条横向均匀光带**，单色（奶白 / 暖白，坚决不要 RGB 彩虹）；
- 固件让它做 **10 段柱高随音乐起伏**（每颗 LED 独立调亮）→ 远看是一条**波形/电平条**。

### 4.2 为什么这个更好

| 维度 | 笑脸 | 训练曲线（推荐） |
|---|---|---|
| 主题自洽 | 与「LEARNED · 学出来的」无关 | **直接就是 loss curve / epoch 进度**，和底刻 `trained, not designed` 呼应 |
| 别人抄不走 | 表情人人会做 | 曲线 + 单色光带，全院独一份 |
| 补完成度空位 | 能补 | **能补，而且补得更狠**（去年最大空位 = 没人把 LED 做成造型主角，我们做的是"光"是主角，不是"像素格"） |
| 改结构成本 | 动外罩 + 光口 + 砍喙 | **0**（全部已定稿） |
| 与「唯一一处发光」 | 破坏（第二张脸） | 保持（还是那条光缝） |
| 与"一只眼" | 抢戏 | 不抢（一眼在上、光带在下，构图稳定） |

### 4.3 固件上的两个细节

1. **拼缝跳一列。** 2 块板拼成 10 列，中间那道拼缝上有 connector 焊盘，
   第 5/6 列之间物理上断了一格。固件要按 **9 个逻辑光点**映射 50 颗物理灯
   （把缝两侧的灯并成一个），否则曲线正中间会永久缺一格 —— 一眼看得出是 bug。
2. **亮度上限 120/255 保留。** 降压模块持续只有 1.6A（不是 3A），
   50 颗 WS2812B 满亮 3.0A 会超。120/255 ≈ 1.4A + ESP32 0.1A ≈ 1.5A，安全。**别开满。**

---

## 5. 如果你还是想留一点"表情"

不要画脸，只留**状态**，两档就够，成本几乎为零：

- **待机**：光带整条以 8s 周期缓慢呼吸（全暗 ↔ 微亮），像在"等训练开始"；
- **播放**：曲线跑起来；
- 不做第三种。

再加一条可选的、同样零成本的：**开机那一秒，光带从左到右扫过一次**（= 一次 epoch 加载），
这就是"个体化启动光纹"里唯一还能保留的动效，和固件随机 seed（每台唯一）接得上。

---

## 6. 顺手收两件悬案

1. **第三块灯板的去向。** 正脸用不上第 3 块（78 已经用满，117 根本放不进头）。
   建议：**不做底光 / 不做侧光**，直接**不买 / 不焊**，省 ¥2.5 + 省一片装配。
   若电能有富余（降压 1.6A 远大于实际 ~1.5A），留着做**底部一圈地灯**（照桌面）也可以，
   但它不参与正脸造型，别为了它改头部。
2. **正脸正下方那片奶油面（你红笔圈的地方）。** 它现在是**空白**，
   本来就是留给喙（P4）的。灯不能占它 —— 占了就变成"脸上贴两块板"。
   P4 喙面板建起来之后，那片区域的归属就闭环了。

---

## 8. 光缝高度现在可以重定 —— 而且成本是 0

**P4 喙面板还没建。** 所以"光缝高 6mm"这个数现在改，成本是 0；等 P4 建完再改，就是废一张打印。
（`03` 写 96×6，`04` 写高 3 深 2 —— **两处不一致，趁现在统一掉，建议取 12。**）

| 档 | 光缝高 | 出来什么 | 代价 |
|---|---|---|---|
| A | **6**（原 `03` 定值） | 一条细线 | 0 |
| **B** | **12**（**推荐**） | 一条**有厚度的**光带，能容纳 1~2 行灯；配合扩散板后像"一条发光的横棱" | 0（P4 还没建） |
| C | **32**（出脸） | 一张 10×3 点阵"脸"（中间 3 行） | 砍喙，见 §9 |
| D | **16**（妥协） | 2 行点（两眼 + 嘴塞进同一行间距），点更挤 | 喙压到脸下沿外，仍可行 |

**v3 新增判据（正前视线可见性）：光口高 H，只看得见 ±H/2 内的灯。**
- H = 12 → 只能看见 ±6mm（不到 2 行）→ 一条光带 ✓
- H = 32 → 看得见 ±16mm（5 行全在，但只用 3 行）→ 读得出脸 ✓
- **H 是"读不读得出脸"的唯一开关**，跟头里有多少空间无关 ——
  空间的 50 给的是"灯摆哪儿"的自由度，不是"脸能开多大"。

**推荐 B。** 理由：6mm 太扁，看着像一条划痕；12mm 是"物和它的光"那类厚度感的上限，
再往上就变成"一块屏"了（§2.5 的扩散悖论从 12mm 开始咬人）。
P4 建模时：**光缝 96 长 × 12 高 × 2 深，居中**，喙面 100×29 → 上下各留 **8.5mm 实体**，结构撑得住。

## 9. 如果你还是要表情：完整改动清单（v1 未采用）

按 §2.7 的 **32mm 光口 + 3 行灯**，逐项列清楚，方便你拍板后直接照做：

| 件 | 从 | 改到 | 备注 |
|---|---|---|---|
| 光口 | 96 × 6 缝 | **78 宽 × 32 高**（Y −18 ~ −50），正脸下部下沉 2~3mm | 上沿正好接橙外罩底边；与灯板 78 同宽，两端不漏黑 |
| 橙外罩 P14 | 68 × 68 × 4 | **不变** ✓ | 不用改尺寸 |
| 光腔 | 84×42×18 口袋 | 开口朝前改成 **78×32**，与后腔隔墙保留（防漏气不变）；**深度 12 就够，不用加深** | 正前可见性只与光口高有关，与腔深无关 |
| 灯板 | — | 78×39 **贴内腔底摆死**（板底 −48.5、板顶 −9.5、**板心 Y = −29**）—— 板 39 > 口 32，必然上边藏在橙罩后面，无害 | 摆位由"板高 39 > 净空 30.5"倒推，不能居中 |
| 固件 | — | **只点第 2 / 3 行**（中心 **−36.8 / −29**，= 一行两眼 + 一行嘴），其余 3 行熄灭（省电约 60%） | 这两行跨度 7.8，中心 −32.9 ≈ 光口中线 −34 → **2 行正好居中，上下各留 12mm 遮光边** |
| 列 | — | 10 列 → **9 逻辑列**（拼缝跳 1 列） | 避免曲线正中间永久缺一格 |
| 扩散板 | `03` 原方案有 | **不做**（做了就 §2.5 悖论） | |
| 喙 P4 | 100×29×7，前伸 10、下倾 6° | **取消面板**，退成光窗下沿一条 **8mm 橙色压条** | 保住"橙"这个色的落点 + 一条横向压线 |
| 固件 | 曲线 | 10×5 点阵映射，**9 个逻辑列**（拼缝跳 1 列） | |

**代价（照实说）：**
- 喙的形态语言没了（前伸、下倾、等厚这几个特征整体消失）→ 六条设计语言少一条；
- 正脸下部 **32%** 面积变成发光面，奶油面只剩左右两条竖边（各约 9mm 宽）；
- 近看是 10×5 的点阵网格（灯 Ø5、间距 7.8、缺口 2.8），**这是最容易被认成"贴了个屏"的地方**。

## 10. 一句话

**灯可以做主角，但主角是"光"，不是"一张脸"。**
光缝只有 3~6mm 高，它天生只能是一条线 ——
那就让这条线**随音乐起伏成一条训练曲线**，比一个 8bit 笑脸高一个版本，
而且一件已定稿的东西都不用改。

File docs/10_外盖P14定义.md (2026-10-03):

# P14 外盖（遮罩）定义 v2 · 2026-10-02

## 0. 依据：实物参考

四张实物照（同学的双喇叭音箱模块）读出的三条：

1. **外罩是独立薄板件**，压在壳体正面最外层，把喇叭的方法兰、四角安装螺丝头全部盖住，只露出圆孔里的振膜。
2. **固定方式 = 外罩自带热熔螺母（四角金色）+ 壳体开通孔 + 螺丝从壳体另一侧（腔内/背面）穿出来往里拧**。正面看不到一颗螺丝头，只看到螺母的金色环。这正是我们已经定的"从后往前"，实物证明可行且是最简做法。
3. **罩的孔口带一道内翻边/浅沉台**（图 4 里喇叭是"坐进"蓝色孔的台阶里，不是贴平的）。这道边让振膜看起来是嵌进去的。

> 我们原来设计的"外盖背面伸 3 根 Ø5 柱 + 前脸开 3 个 Ø6.5 大孔 + 柱端埋螺母"**作废**。
> 柱是悬空特征，打印娇气；Ø6.5 大孔破坏后腔密闭；柱端盲孔里热熔小螺母极易歪斜。
> 改成与实物同构的"薄板压螺母 + 脸部小通孔"。

## 1. 一个之前的判断错误（订正）

外盖贴在脸的**外表面**（Z > 0 一侧），它的 X/Y 范围只受 **脸外轮廓 96 × 102 约束**，
**不受"内腔 Y ±48.5"约束**（外盖不在腔内）。

→ 由此，昨天说的"顶部放不下第 4 个螺丝点"作废（旧判据用错了约束面）。
→ 外盖可以放大到 68 × 68：Y ∈ [−18, +50]，顶边 50 < 头高半边 51，正好到头轮廓顶留 1mm。

## 2. 定稿参数（P14 外盖）

| 项 | 值 | 说明 |
|---|---|---|
| 外形 | **68 (X) × 68 (Y) × 4 (Z)** | 方形、四角 **R5** |
| 定位 | 盖心 = 眼心 **(0, +16)**；绝对范围 X ∈ [−34, +34]、Y ∈ [−18, +50] | 顶边 50，距头轮廓顶 51 留 1mm；左右各留 14mm 露奶油脸 |
| 内孔 | **Ø48 通**（沿厚度 4 全通） | 与前脸 Ø48 过声孔同心齐平，看不到台阶 |
| 正面 | **Ø52 浅沉台，深 1.2** | 环形凸缘宽 2mm（(52−48)/2），振膜坐进台阶 ← 照抄实物 |
| 材质 | PETG，橙 **#F26B21**（与 P3 顶盖 / P4 喙 / P13 脚掌同色同批漆） | 正面读出来 = **橙眼圈 + 黑瞳**（黑振膜坐进 Ø52 浅沉台）。黑色退回结构件（颈 / 腿 / 关节），配色回到定稿的**一主（奶油）一强（橙）一中（黑）** |
| 螺母 | **4 × M2×3×3 热熔铜螺母** | **不做凸台**，直接压平孔。孔 **Ø3.2 × 深 3.0**，开口在**贴脸面**（腔侧），方向朝正面（+Z），给定深度终止，正面留 **1.0** 实料不冲穿。螺母长 3.0 → 压到底正好与贴脸面齐平，被夹在 P1 脸面与外盖之间，**正面完全看不见**（比实物的正面金点更干净）。**孔深 2.6 / 留 1.4 是错的**，见 §8 |
| 螺孔位（相对盖心） | ** (±28, 0) / (0, ±28)** | 到盖边 6mm、到 Ø48 孔壁 4mm，料都够 |
| 螺孔位（绝对） | **(±28, +16) / (0, +44) / (0, −12)** | |
| 前脸对应 | P1 开 **4 × Ø3.0 通孔** | M2 沉头螺丝穿过；锁完打硅胶封孔 |
| 螺丝 | **M2×10 沉头 ×4** | 沉头 1.2 + 穿脸 2.5 + 咬合螺母 3 ≈ 6.7 → M2×8 只富余 0.7，用 M2×10 稳妥 |

### 已作废（不要照着建）
- ~~外盖 64×64×3~~
- ~~外盖背面 3 根 Ø5 柱、向腔内伸 10.5~~
- ~~前脸 3 个 Ø6.5 大通孔 + 泡棉圈密封~~
- ~~柱端 Ø3.0×3 盲孔 + Ø10 法兰面~~

## 3. 冲突校核（已算过，建之前复核一眼）

| 检查项 | 结果 |
|---|---|
| 4 个螺孔 vs 喇叭法兰 4 个 Ø3.0×深5.5 盲孔（在 (±21,±37) / (±21,−5)） | 最近距离 ≥ 22 mm ✓ |
| 4 个螺孔 vs Ø48 过声孔（半径 24） | 孔心距 28 > 24，全落在脸实体上 ✓ |
| 外盖顶边 Y=50 vs 头轮廓顶 51 | 留 1mm ✓ |
| 外盖 X±34 vs 脸宽 ±48 | 左右各留 14mm ✓ |
| 法兰 4 颗 M2 螺丝头 → 被外盖盖住 | ✓ 正面看不到（这也是外盖存在的意义） |
| 外罩下沿 Y=−18 vs 喙面板顶边（改橙后成为**配色冲突**，不是干涉） | **待核**：喙顶须 ≤ −26，否则要降到 58×58 |

## 4. 装配顺序（顺序不能乱）

1. P1 前脸 4 个 Ø3.0×深5.5 盲孔埋 M2 热熔螺母 → 装喇叭，4 颗 M2×8 **从外**拧进法兰凸台（螺丝头被外盖吃掉）
2. 贴 2mm 闭孔泡棉环（Ø48 周围，气封）
3. 腔内侧：装功放板 / ESP32 / 降压模块 / 穿线（过线孔 Ø10 落在 P1 实体上）
4. **外盖热熔螺母（打印后单独工序，装配前做完）**
5. 外盖扣上（背面贴脸，四角螺栓位对准前脸 Ø3.0 孔）
6. **从后口伸进腔内**，拧 4 颗 M2×10 沉头 → 正面零螺丝
7. 4 个孔位点硅胶/热熔胶封（后腔只求密闭）
8. 合后壳 P2（M3×10）—— 注意必须在第 6 步之后，合完手伸不进腔

## 5. 采购

- M2 热熔铜螺母 M2×3×3：**已有 50 个，够用**（前脸法兰 4 + 外盖 4）
- **补买 M2×10 沉头 4~6 颗**（原计划的 M2×8 行程只富余 0.7mm，改 M2×10）
- 硅胶/热熔胶（封 4 个小孔）

## 6. 外观判断（外罩改橙之后）

### 6.1 定下来的三件事

- **不做双色**（外圈奶油 / 内环黑）。双色打印或多一道分色工序不值得，边界对不齐反而脏。
  整块橙，靠 **Ø52 浅沉台** 那道 1.2mm 台阶自己分层次——台阶外是橙平面，台阶里是黑振膜，再往里是 Ø48 通道。三级只读得出来。
- **"外圈不喷黑、留奶油"这个备选取消**。整片一块橙，最省事。
- **头顶那条橙会连到眼下，这是几何必然，不是画糊了。**
  外罩顶边 Y=+50、头轮廓顶 Y=+51，中间只剩 1mm；而顶盖就在头顶。
  所以正面上部从 Y≈+50 一路到眼下，是一整块橙（顶盖 + 外罩 视觉上成一块色分区）。
  这是 68×68 的必然结果（盖心锁死在眼心 (0,+16)、必须对称包住方法兰），**不是缺陷** —— MicroDuck 的 orange 也是这样分区的。

### 6.2 唯一要防的：外罩下沿 vs 喙顶

外罩下沿 **Y = −18**。喙面板（P4）在正脸下部，高 29。
→ **判据：喙顶边必须 ≤ −26**，即两者之间要留 **≥8mm 奶油带**。
→ 低于 8mm 就是一条奶油细缝，看着像没对齐的接缝，不像配色。

两条路（核完喙的实际 Y 再选）：

| 路 | 做法 | 代价 |
|---|---|---|
| A（首选） | 保持 68×68。前提是喙顶 ≤ −26 | 需要喙往脸底贴：喙 29 高 → 喙底 = −55？放不下（脸底 −51）。**所以 A 大概率不成立** |
| B | 外罩收到 **58×58**（半边 29，螺孔收到 ±23）→ 下沿 **−13**、顶边 **+45**。给喙让 5mm、给顶盖让 6mm | 方兰 52.6 每边只剩 2.7mm 遮丑余量，四角 R5 圆角内缩 1.46mm —— 刚够，不能再小 |

**还没定**：P4 喙面板顶边的绝对 Y。目前文档里只写了"头正面下部"，没有硬数值。
进 SolidWorks 建 P4 之前必须定它，否则外罩 68 还是 58 悬着。

### 6.3 打印/喷漆的一句提醒

外罩是正脸上最大的一块面色，**必须喷**（完成度红线：看不出层纹）。
建议 **橙 PETG 打印 → 打磨 400→800→1500 → 底漆（#F26B21 同号）→ 哑光面漆（#F26B21 同号）**。
底漆面漆用同号橙，宁可比 #F26B21 略深——露底下是深色才难看，露出略深的橙面反而是"同色"。
不要用奶油色打底再喷橙：奶油透出来会发脏。

## 8. 订正：外盖不要凸台，孔深改 3.0（2026-10-02 晚）

**不用先做 D5 圆柱再挖 D3.2。** 外盖只有 4mm 厚，凸台是往腔里长的悬空特征，打印娇气、
还要在前脸上再开 4 个 Ø5.5 大通孔（漏气风险 + 多一套孔），不值。
热熔螺母本身就 3.0 长，直接压 3.0 深的平孔就够了 —— 压到底正好与贴脸面齐平。

**D5 凸台 + Ø3.0 盲孔那套是 P1 前脸的做法**（喇叭法兰 4 角：4×Ø5.5 凸台、Ø3.0×深 5.5 盲孔埋 M2），
两个零件不要混。

| 旧（错） | 新（对） |
|---|---|
| 孔 Ø3.2 × 深 2.6，正面留 1.4 | 孔 Ø3.2 × 深 **3.0**，正面留 **1.0** |
| 开口在"背面"、需要切"反侧" | 开口在**贴脸面（腔侧）**、方向**朝正面 +Z（默认方向）** |
| 螺母长 3.0 塞不进 2.6 的孔 → 会凸出 0.4 戳进 P1 脸面（干涉） | 3.0 孔吃 3.0 螺母，压到底齐平，零干涉 |

SW 做法：**转到贴脸那面（腔侧）→ 新建草图 → 4 个 Ø3.2 全圆（相对盖心 ±28）→ 切除-拉伸 →
给定深度 3.0 → 方向用默认（远离该面，朝正面走），不要点"反侧"**。
自检：等轴测看孔口在贴脸面；侧视量孔底距正面剩 1.0mm 实料。

## 9. 四角孔不行，孔位必须是「四边中点」十字（几何论证）

外盖建的时候最容易把螺母孔放到板的四角（照实物参考的四角金点）。四角放不下，三条理由：

1. **R5 圆角把角切了。** 68×68 板（以板心为原点，边 ±34，R5 圆角圆心在 ±29）：
   孔心要离 R5 圆心 ≤ 5 − 1.6 = **3.4** 才不被切到边界，所以孔心最外只能到 (±27.4, ±27.4)。
   → 角部只剩 2.2mm 到边，4mm 薄板的角上压一根 3mm 长的热熔螺母，一角悬空必崩边。
2. **角位和喇叭法兰那 4 颗 M2×8 螺丝孔只隔 7.07mm**（法兰孔在绝对 (±21,+37)/(±21,−5)），
   两个 Ø3.0/3.2 孔之间只剩约 4mm 薄壁；而且 P1 上那个位置要打 M2×10 通孔，会和法兰盲孔在同一 X/Y 上打架。
3. **十字才和 Ø48 同心对称**：四边中点 [(0,±28)/(±28,0)] 到 Ø48 孔壁 2.4mm、到盖边 6mm，料最匀，
   视觉上是"四边四颗 + 中间一只眼"，比四角更像一个面罩。

> 顺带：截图里板子看着"又扁又宽"是透视 R5 视角造成的，**不要按屏幕比量尺寸**，
> 用 SW 测量确认：板 68×68×4、圆角 R5、中心 Ø48 通、Ø52 沉台深 1.2。

## 10. P1 前脸上与外盖对接的 4 个孔（做法）

### 10.1 先锁坐标：两边共用眼心原点

P1 与 P14 **都以眼心为原点**（两步渲染的 triad 都落在 Ø48 孔心，这点已经对了），
所以 P1 上这 4 个孔的 X/Y 与 P14 的 4 个螺母孔**数值完全相同**：

| 相对眼心 | 绝对（绝对系 = 眼心为原点时同值） |
|---|---|
| (+28, 0) / (−28, 0) / (0, +28) / (0, −28) | 同上 |

原文档第 2 节的「绝对 (±28,+16)/(0,+44)/(0,−12)」是**以盖心=眼心、但外盖原点写在盖心**时的值；
 P1 若与眼心同原点，直接写 (±28, 0)/(0, ±28) 即可。**两边必须同一个数，谁改谁一起改。**

（截图里标的 36 / 23 是四角矩形布点；P1 与 P14 若都按它走也成立，
但角部 + R5 圆角崩边那条风险仍在。定死一个数再动刀。）

### 10.2 孔型与做法（**可以用异型孔向导，但必须腔侧放置**）

最终需要的孔型（沿 Z 从头到脸）：

| 位置 | 特征 | 参数 |
|---|---|---|
| 正面（外表面，Z>0） | 光孔口 | **Ø3.0 开口**，外面被 P14 压住 |
| 脸厚 2.5 | 直孔段 | **Ø3.0，完全贯穿** |
| 腔侧（腔内侧壁，Z<0） | 90° 沉头 | **Ø4.0 × 深 1.2**，给 M2 沉头螺丝头 Ø4.0×1.2 坐位（否则螺丝头凸进腔 1.2mm 可能顶到功放板/线） |

→ 也就是说：**沉头必须在腔侧、直孔必须贯穿**。这两条定死，做法随便选。

#### 方案 A（推荐）：异型孔向导，**从腔侧放一次做完**

因为终止条件选「完全贯穿」时，SW 刚好生成"**放置面侧一段 90° 沉头 + 直孔穿透**"——正好就是我们要的形状。

1. **先把模型转到腔侧朝向你**（Ctrl+6 后视 / 或手动转，让碗的内底壁对着观察者）。
2. `插入 → 特征 → 孔 → 向导`（或工具栏 Hole Wizard）。
3. **孔类型 = 机丝 (Machine Screw) → 沉头孔 (Countersink)**，标准 ISO（或 GB）。
4. **孔大小 = M2**。此时 SW 给的默认直孔直径是 **2.0**（M2 间隙孔）→ **手动改成 3.0**；
   沉头直径默认 4.1 → 保持（≈Ø4.0，M2 沉头头径）。
5. **终止条件 = 完全贯穿 (Through All)** —— 只作用于直孔段；沉头深度按 M2 标准取 1.2。
   ⚠️ 不要选"给定深度"，2.5 厚的脸 + 1.2 沉头 = 直孔段只剩 1.3，但我们要的是直孔穿透 2.5。
6. **Step 2 位置**：在腔侧面上点 4 个点 → 用智能尺寸约束到相对眼心
   **(±28, 0) / (0, ±28)**（68 方案；58 方案改 ±23）。
7. `下一步 → 完成`。预览里检查：**沉头在腔侧、正面只留 Ø3.0 小口**（点"旋转方向/Reverse"可翻转）。

#### 方案 B（腔侧找不到放置面时）：手动两步切除

1. 腔侧草图 → 4 个 Ø3.0 全圆 → **切除-拉伸 → 完全贯穿**。
2. 同草图 → 4 个 Ø4.0 全圆（或改 Ø3.0 为 Ø4.0）→ **切除-拉伸 → 给定深度 1.2 → 方向朝正面**。

#### 仍然成立的三个坑

- **绝对不能从正面（外表面）放。** 向导会把沉头开在放置面那一侧 → 沉头进正面，
  而螺丝头在腔侧根本没有坐位（头顶在 P1 腔面上）；正面那个沉坑还被外盖压住，装配才发现。
- **孔类型不要选"机丝 → 螺纹孔 (Tap)"**，那会生成 M2 螺纹线（给螺柱用的），我们要的是光孔。
- **腔侧放置面** = 抽壳后碗的**内底壁**，不是外轮廓面；选面别选错（选到正面就翻车了）。

### 10.2c 向导实拍参数订正（2026-10-02 晚，用户截图）

SW 孔向导实拍：标准 **GB**、类型 **开槽半沉头螺钉 GB/T 69-**、大小 **M3**、套合 **松弛**、
自定义 **3.00 / 4.100 / 90 度**、终止条件 **完全贯穿**。

| 项 | 截图值 | 应为 | 理由 |
|---|---|---|---|
| 大小 | **M3** ❌ | **M2** ✓ | M3 半沉头头径 ≈5.0（沉头 5.5），坐不进 Ø4.0 的沉台（顶在孔口上不去）；而且手上没有 M3 螺丝。M3×10 是**合壳（P1↔P2）**用的，别拿它顶这里 |
| 类型 | GB/T 69 半沉头 | **保持**（手上只有半沉头） | 68（沉头）与 69（半沉头）对 M2 的头径/头高**完全一样**（都是 4.0 / 1.2），以手上有啥为准 |
| 套合 | 松弛 (Clearance) | **保持** ✓ | 我们要光孔，不要螺纹线 |
| 自定义 ① 孔直径 | 3.00 | **保持 3.00**（但改 M2 后 SW 会重置成 2.0，改完要再手打回 3.0） | 杆 Ø1.6~2.0，孔 3.0 有余量；外盖螺母孔 Ø3.2 |
| 自定义 ② 沉头直径 | 4.100 | **保持**（M2 沉头头径 4.0~4.1） | 与腔侧沉台 Ø4.0 配套 |
| 自定义 ③ 角度 | 90 度 | **保持** ✓ | |
| 终止条件 | 完全贯穿 | **保持** ✓ | 只作用于直孔段，沉头按 M2 标准取 1.2 |

> 半沉头比沉头会多凸出约 0.2~0.3mm（半球顶），凸进腔内那点量无所谓，**不要为此改沉台深度**。
> 位置页要点满 **4 个点**（向导一个点生成一个孔），尺寸 (±28,0)/(0,±28) 相对眼心。

### 10.2b 装配后处理

螺丝杆 Ø2.0 插在 Ø3.0 孔里单边 1.0 缝 → 拧完打硅胶/热熔胶封（与 Ø10 过线孔同一处理）。
沉头 1.2 + 穿脸 2.5 + 咬合螺母 3.0 = 6.7 → **M2×10 沉头富余 3.3mm** ✓（M2×8 只富余 1.3，仍用 M2×10）。

### 10.3 别把这 4 个孔开到凸台上

P1 大孔周围那 4 个小圆孔（Ø3.0×深 5.5）= **喇叭法兰凸台**（M2×8 从外拧进 P1），
和对接外盖的这 4 个是两拨人、不是同一批孔，别混。

### 10.4 螺丝长度复核

沉头 1.2（坐腔内沉台）+ 穿脸 2.5 + 咬合螺母 3.0 = **6.7** → **M2×10 沉头富余 3.3mm** ✓
（M2×8 只富余 1.3，勉强；仍按 M2×10 走。）

## 11. 下一步

1. 建 P14 外盖（68×68×4、R5、Ø48 通、Ø52 沉台深 1.2、**贴脸面 4×Ø3.2 深 3.0 盲孔**）
2. P1 前脸补 4 × Ø3.0 通孔（在 (±28,+16)/(0,+44)/(0,−12)）
3. 之后的 P1 主线：过线孔 Ø10 → 颈接口 2×M4（颈 P7 还没建，颈接口要等 P7）
4. **建 P1 之前先量喇叭实物法兰四角的孔距**（见 §12.6）

## 12. 喇叭（方法兰）怎么固定到 P1 前脸 —— 正面 4 颗 M2（2026-10-02 晚补）

### 12.1 结论：外面不加任何零件

固定喇叭只有一样东西：**4 颗 M2 机丝从正面拧进 P1 前脸凸台里的热熔螺母**。
外面多出来的唯一零件是 **P14 外盖，但它不是固定件** —— 它不参与受力，只负责把方兰和
这 4 颗螺丝头遮住（这也是当初要外盖的原因）。

顺序上：先拧螺丝压法兰 → 泡棉 → 腔内装电路 → 最后扣外盖（此时 4 颗螺丝头才被吃掉）。

### 12.2 今天才发现的坑：螺丝头会把喇叭法兰顶起 1.2mm

方法兰是**贴着凸台顶端平面**压下去的（面贴式，不是沉进坑里）。而 M2 沉头/半沉头的
头径 4.0、**头高 1.2**。

如果螺丝头直接坐在凸台顶端平面上：

→ 螺丝头凸出凸台顶端 **1.2mm** → **法兰被顶起 1.2mm，压不到底**。

后果不是好看不好看，是功能性的：
1. 法兰与脸面之间的 **2mm 闭孔泡棉环压不实** → 气封失败 → 漏气、低频丢、可能啸叫
   （这正是当初把"壳即腔"方案排除的原因，别在这里自己漏回去）；
2. 法兰四角翘起，外盖（同样贴在脸外表面）也跟着不平，橙外盖边缘会翘缝。

**解法：凸台顶端开一道 Ø4.0 × 深 1.2 的 90° 沉台**，把螺丝头沉进去，
沉台底平面 = 新的贴合面 → 螺丝头与凸台顶端齐平 = 法兰能压死。

> 判据（记牢）：**法兰贴合面必须是凸台顶端那个平面本身，不是凸台顶端上面 1.2mm 的空气。**
> 所以只要用沉头/半沉头，凸台顶端就一定得有沉台。用盘头/圆头则更糟（凸 1.5~2mm），别选。

### 12.3 参数（P1 前脸 4 个凸台，坐标相对眼心、与绝对同值）

| 项 | 值 | 说明 |
|---|---|---|
| 孔位（相对眼心） | **(+21,+21) / (−21,+21) / (+21,−21) / (−21,−21)** | 见 §12.6 待量；对角 42×42 |
| 凸台 | **Ø5.5 × 高出脸面 5.5** | 从脸外表面往外长 |
| 顶端沉台 | **Ø4.0 × 深 1.2**（90°） | 沉头坐位，与凸台顶端齐平 → 法兰贴合面 |
| 沉台底盲孔 | **Ø3.0 × 深 4.3** | 吃热熔螺母 |
| 孔底之内 | 孔底距脸外表面 5.5 − 4.3 = **1.2**，再进脸厚 2.5 → **背后留 3.7 实料** ✓ 绝不会穿 |
| 热熔螺母 | **M2×3×3**，压进 Ø3.0×4.3（吃满 3.0，留 1.3 空） | 已有 50 个，够 |
| 螺丝 | **M2×10 沉头（或半沉头）×4** | 见 §12.4 长度复核 |

### 12.4 螺丝长度复核 + 采购（这条会卡住你）

1.2（沉台）+ 4.3（盲孔）+ 3.0（咬合螺母）= **8.5**

| 螺丝 | 判定 |
|---|---|
| M2×5（手上现有） | ❌ **差 3.5mm，绝对拧不进去**，还会把螺母顶歪 |
| M2×8 | 富余 0.5，太险 |
| **M2×10** | 富余 **1.5** ✓ → 定 M2×10 |

**采购合并算一次**：法兰 4 颗 + 外盖 4 颗 = **M2×10 至少 8 颗（买 10 颗留余）**。
头型 68（沉头）/ 69（半沉头）均可（对 M2 头径头高一样），**以手上有货为准**。

### 12.5 与外盖的关系（别拧反了）

- 法兰这 4 颗 M2×10 是**从正面拧（螺丝头在喇叭正面）**，然后被 P14 外盖吃掉；
- 外盖那 4 颗 M2×10 是**从腔内往里拧（螺丝头在腔内）**，吃完从后口伸进去。
- 两拨人、两个方向、各 4 颗，**一共 8 颗 M2×10**，别只买 4 颗。

### 12.6 待量：法兰四角的孔距

上表孔位 (±21, ±21) 是按 **52.6 方框法兰、四角孔距中心约 21** 估的（不是实测）。
**建 P1 之前必须用卡尺量喇叭实物法兰四角的孔距和孔径。**

- 对不上怎么办：**前脸 4 个凸台整体跟着挪，外盖十字孔 (±28,0)/(0,±28) 不用动** ——
  十字孔距法兰孔最近 22mm（(±28,0) 到 (+21,+21) = √(7²+21²) = 22.1），有 4mm 余量可吸收少量偏移。
- 若偏移大到 22mm 余量被吃光，再把外盖十字孔整体外扩 2~3mm（扩到 ±30/±31，料还够）。

### 12.7 与 §10.3 的关系

§10.3 说的"别把对接外盖的 4 个孔开到凸台上"仍然成立 —— 现在这一节更明确：
**那 4 个 Ø3.0×深5.5 凸台孔本来就是给喇叭法兰用的**（沉台 1.2 是本次新增的，
之前只写了盲孔深 5.5，缺了沉台这一刀）。**按 §12.3 的 1.2+4.3 重做孔型。**

---

## 13. 装配体「测试2」进展审阅（2026-10-02 晚，五视图核对）

### 13.1 现状盘点

装配树（5 张截图）：`测试2` → `前壳<1>(P1)` / `卿咧<1>(喇叭)` / `后盖<1>(P2)` /
`遮罩<1>(P14)` / `螺丝M3x8<1~4>` / `螺丝M3x10<6~10>` / `配合`。

→ **P1 + P2 + P14 + 喇叭四件套已全部进装配体并完成配合**，共 9 颗螺丝（M3×8 ×4、M3×10 ×5）。
→ 渲染验证：遮罩压在 P1 外表面上、方兰被盖住、只从中央孔露出振膜（图 1 橙版 ✓）；
背/腔侧视图能看到腔内的 4 颗 M3×10 头、脸上一圈孔、以及下方一个"圆柱 + 三爪"凸台。

**头壳（P1/P2/P14/喇叭）完成度 ≈ 85%，全身（P3 顶盖 / P4 喙 / P7 颈 / P8·P9 身 / P10~P13 腿）
一件未动，泡棉环、配重、过线孔也还没闭环。**

### 13.2 已经做对的（不要推翻）

1. **遮罩的路线落地了** —— 薄板压螺母 + 脸开小孔 + 腔内螺丝，正是实物参考那条最短路径。
2. **正面看不到法兰的 4 颗螺丝头**（图 1 橙色版），外盖完成它存在的意义。
3. **P1 / P2 / P14 三个零件原点统一在眼心（Ø48 孔心）** —— 这是后面所有孔位能对齐的基础，
两处 triad 都落在孔心，这点做得对，别再动原点。

### 13.3 必须拉平的三个数

**(A) 螺丝体系整体跑成了 M3，一条 M2 都没有。**
与 §10.2c / §12 定的 M2 冲突（M3 半沉头头径 ≈5.0，坐不进 Ø4.0 沉台；且手上的 M3×10 原定是合壳那批）。

**(B) 长度账（本次核心，算术重做）：**

| 体系 | 贴合链 | 需要长度 | 结论 |
|---|---|---|---|
| 沿用 M2 尺寸 | 沉台 1.2 + 盲孔 4.3 + 咬合 3.0 | **8.5** | M3×8 **差 0.5，拧不到底**；要 M3×10 |
| 孔按 M3 重开（长 5 螺母） | 凸台高 5.5 = 沉台 1.5 + 盲孔 4.0 | 盲孔 4.0 < 螺母长 5 → **螺母凸出沉台底 1.0，堵死螺丝头** | 凸台加高到 **7.0**，或换 **M3×3×4.5 短螺母** |
| 外盖（厚 4） | 盖厚 4 − 螺母长 | M3 长 5 螺母 → **必然戳穿正面**（本应留 1.0） | 外盖那 4 颗**只能是 M2**（M2×3×3 长 3，留 1.0 ✓） |

**(C) 订正：§9「四角绝对不行」论证写反了。**
68 板边 ±34、R5 圆心 ±29。角孔不被圆角切到的正确条件 = **孔心距 R5 圆心 ≥ 5 + r(孔半径)**。
- M3 孔 Ø4.5 → r=2.25 → 需 ≥ 7.25 → 沿对角方向 **±23 安全，> ±26 就会吃进圆角**（孔口缺角、螺母压歪）。
- 十字位 (±28,0)/(0,±28) 距 R5 圆心 ≈28，**完全安全**，距边 6mm，四边对称更匀。

→ 结论：**你图上四角 ±23 的方案是成立的**（比 ±26 安全），十字也成立，两条都是可行解，
按已经建好的四角版走即可，**不要再改十字**（改了等于白打一遍）。§9 那句"离边只剩 2.2mm"是算错了方向。

### 13.4 重订：两拨孔天生就是两套体系（不是妥协，是几何逼的）

| 用途 | 零件 | 贴合面 | 热熔螺母（手上/现采） | 螺丝 | 数量 |
|---|---|---|---|---|---|
| 喇叭法兰 | P1 前脸 4 个凸台（高 5.5） | 凸台顶沉台底 | **M3×5×4.5**（外径 4.5、长 5）或改短螺母 M3×3×4.5 | **M3×12 半沉头** | 4 |
| 外盖对接 | P14（厚 4） | 外盖贴脸面 | **M2×3×3**（长 3，已有 50 个） | **M2×10 半沉头** | 4 |
| 合壳 P1↔P2 | P2 沉头孔（已打） | — | M3×5×4.5 | M3×10（手上现成） | 4（**装配树里还缺**） |

**补货清单（合并一次下单）**：M3 短螺母 M3×3×4.5 ×4~6；M3×12 半沉头 ×4~6；M2×10 半沉头 ×4~6。
手上那 4 颗 M3×8：若孔已按 M3 开好、且拧得到底就留着（富余 3.5 够），拧不进就退掉。

### 13.5 那 4 颗正面黑十字（图 2）必须今天定性

图 2 正面四角能看到 4 颗黑色十字头 = 有一拨螺丝的头露在正脸。两种可能，**结论完全相反**：

1. **它是锁外盖的**（从正面穿过遮罩角打进 P1）→ 这等于回到"从前打螺丝"，
正面留 4 颗可见头，与外盖存在的意义冲突 → 改腔内拧（按 §13.4 外盖体系：M2×10）。
2. **它是锁喇叭法兰的**（M3×8 从正面拧、头压在喇叭面上）→ 这是正常的（法兰必须从正面拧），
但它**必须被外盖盖住**；图 2 里它露在遮罩外面 → 遮罩尺寸/孔位跟它错开了 →
要么遮罩放大到把角包住，要么这 4 颗往内挪到遮罩投影内。

**判据（10 分钟能定）**：在装配树点开那 4 颗 M3×8 → 看"钉入面/配合面"落在 **P1 凸台顶** 还是 **P14 遮罩**。
落在凸台顶 = 情况 2；落在遮罩 = 情况 1。

### 13.6 下一步优先级

1. **定性那 4 颗正面螺丝的归属**（今天唯一必须先答的一问）。
2. **定 P4 喙面板顶边的绝对 Y** —— 还空着，它卡着外盖 68 vs 58、孔位 ±28 vs ±23。
3. 补**合壳 M3×10 ×4**（P2 沉头孔已经打好了，只差螺丝进装配 + 后口拧紧次序）。
4. 确认图 4 下方那个"**圆柱 + 三爪**"是不是 Ø10 过线孔；不是就补一个。
5. 之后才开身体：P7 颈（同时定 P1 颈接口 2×M4）→ P8/P9 身 → P10~P13 腿。

> **判断**：现在别急着往下建身体。头壳这套螺丝分工 + 4 颗正面螺丝头的归属，
这两件事不钉死就送打印机，4 张头壳打出来多半装不上、或者装上了正脸露 4 颗螺丝头。

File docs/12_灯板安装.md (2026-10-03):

# 12 · 灯板（WS2812B 5×5）怎么装：机械固定 + 接线

> 起因：2026-10-02 晚，用户拍到灯板实物背面（四角沉孔 + 两侧 GND/IN/VCC/GND 焊盘），
> 问「我不知道如何安装灯板」。
> 本文把这件事拆成两半：**机械（装在哪、怎么固定）** 和 **电气（线怎么焊、接哪、两块怎么串）**。

---

## 0. 从这张照片读到了什么

照片拍的是**板的背面**（看不到灯珠的那一面）：

| 观察 | 结论 | 对设计的意义 |
|---|---|---|
| 表面无灯珠、只有丝印和焊盘 | 拍的是背面 | **LED 面在另一面** → 装配时 LED 面朝前（朝光缝 / 正脸），手里这面朝后 |
| 四角各一个圆孔，孔口有一圈镀铜/斜边 | 这是**沉孔**，厂家给 M3 沉头螺丝预留的安装孔 | 固定这件事基本已经有答案了：4 颗 M3 沉头 |
| 两侧各有 4 个焊盘，一侧标 IN、一侧标 OUT | **双 connector**，专为多板串联设计 | 两块拼的时候不用额外飞线转接 |
| 焊盘丝印顺序（照片倒置，正过来读）：GND / IN / VCC / GND | 4 针定义 = **GND、DIN(标 IN)、5V、GND** | 接线只用其中 3 根（GND、VCC、DIN） |
| 板 39 × 39，四角有孔 | 已知 | 见 §1 |

> **别靠丝印猜极性。** 每家板子的丝印顺序不一样（有 VCC/GND/DIN/DOUT，也有 GND/VCC/IN/OUT）。
> 以板上丝印为准；如果实在读不清，用万用表通断档量：**两个 GND 焊盘是相互连通的**（同一网络），
> 其余几颗（IN / VCC / OUT）各自独立。量出来谁跟谁通，接线表就以实测为准。

---

## 1. 先量两个数（决定固定方案，别跳过）

| 量 | 参考值 | 为什么必须量 |
|---|---|---|
| **① 安装孔孔径** | 目测 Ø3.2~3.5（沉孔口更大） | 决定用什么螺丝。我们热熔螺母 M3×5×4.5 要求**光孔 ≤ 3.0**；PCB 孔比螺母大是必然（PCB 上孔必然 ≥ 螺丝杆 + 余量），所以螺丝杆 Ø2.0~2.5 过孔没问题，**卡在的是过盈配合那一段在壳上不在 PCB 上** |
| **② 四孔孔距（对角）** | 目测约 27~30 mm | 决定 4 个固定凸台在光腔后壁上的位置；也决定会不会撞到最外圈灯珠 |

**判据（量完自己算）：**
孔心到板心的距离 `a = 孔距 / 2`（正方形对角布孔时，X、Y 各 = a/√2）。
- 若 `a − 1.6（半孔）> 最外圈灯珠中心距`（≈16.5）→ 孔在灯阵外，可以打螺丝；
- 若孔压在最外圈灯珠上 → **改用方案 B（胶体）**，别硬打孔。

**这两个数没量之前，光腔后壁的凸台位置不要进 SolidWorks。**

---

## 2. 机械固定：三个方案，按推荐度排

### 方案 A（推荐）· 4 × M3 沉头螺丝 + 光腔后壁凸台

结构（从前往后看）：

```
[正脸 / 光缝开口]
   ↓ 光从这里出来
[灯板 39×39×2.8，LED 面朝前]
   ↓
[光腔 18 深，四角有 4 根朝前伸的凸台穿过灯板孔]
   ↓
[光腔后壁 = 隔墙，凸台根部热熔 M3 螺母]
```

- 凸台：Ø6 × 高出后壁面 **5**，四角位置 = 灯板四孔位（待 §1 实测后入模）
- 凸台顶端开**沉台 Ø4.6 × 深 1.5**（给 M3 沉头头 Ø5.5 坐位，避免把 PCB 顶起来）
- 沉台底盲孔 Ø3.0 × 深 3.5 → 埋 **M3×5×4.5**（长 5，吃满 3.5 余 1.5）
- 螺丝：**M3×12 沉头 ×4**（1.5 沉台 + 3.5 盲孔 + 5 咬合 = 10 → M3×12 富余 2；M3×10 富余 0 太险）

> 为什么必须是沉头：**盘头/圆头会凸出 2~2.5mm，直接把 PCB 顶离后壁 2mm 以上**，
> 灯和光缝对不上，而且贴不到底。沉头才能和沉台齐平。

### 方案 B · 3M 高强度双面胶 / 泡棉胶（零加工）

- 灯板背面整面贴 3M VHB（4910 之类，或 VHB 4910 5mm 宽 tape），压进光腔后壁；
- **优点**：不用打孔、不用凸台、不会顶歪、拆的时候用酒精/温风可撕；
- **缺点**：不能反复拆；螺丝定位能靠它之外的定位（见下）。

### 方案 C · 定位 + 胶体（我实际更推荐这个）

1. 光腔后壁做 **2 个定位柱（Ø3 圆销，朝前伸 5）**，插进灯板其中两个对角孔 —— 这一步决定位置；
2. 剩下两个孔不穿螺丝，整板背面 3M 胶压死。

**理由**：螺丝方案（A）的 4 处过盈配合在 1.8mm 的薄 PCB 上很容易拧歪、把孔边拉毛；
定位销 + 胶体既准又不会崩孔。而且灯板不需要承受任何力，它是被"摆"在腔里的，不是被"锁"在腔里的。

> **我的建议：先按 C 做（定位柱 + 胶），备 4 颗 M3×12 沉头以防后续要拆。**
> 这样 §1 那两个数即使量错，也只是定位柱位置错了，板子照样装得进去。

---

## 3. 一个必须先想清楚的方向问题（容易翻车）

灯板 **LED 面朝前**（朝光缝）。手里这面（照片那面）朝后，**贴光腔后壁**。

推论：
- 从正面拧螺丝（螺丝头压在灯板正面）→ **螺丝头必然落在光缝里**，正脸一条 96 长的光带上有 4 个黑点 → 破"正面一颗螺丝头不能有"这条线；
- 所以**只能从灯板背面（腔内那侧）往里拧**，或者干脆用胶体（方案 B/C）。

**这条判据现在就成立，别等光腔建完才想起来。**

---

## 4. 电气：三根线 + 两块串联

### 4.1 单板接线（台面阶段先焊这个）

| 线 | 焊盘（按板上丝印） | 从哪来 |
|---|---|---|
| **5V** | 标 VCC | 降压模块 **5V 输出**（22.3×17 那块，输入 7–26V，输出 5V） |
| **GND** | 标 GND | 降压模块 GND —— **必须与 ESP32、功放板共地** |
| **DIN** | 标 IN（有的板标 DAT） | ESP32-C3 的 GPIO |

- 只用 **IN 侧 3 根线** 就够了；OUT 侧是留给下一块的。
- 线材：**DIN 用软线**（硅胶线 22AWG 软线或杜邦线），24AWG 镀锡硬线在腔内会顶到 PCB 和壳 —— 这是之前记过的坑。
- **DIN 串一颗 330Ω 电阻**（DR 端，焊在 DIN 焊盘外 5~10mm 处）。这是 WS2812 的标准做法，能抑制反射、防首颗灯误触发。

### 4.2 ESP32-C3 引脚

- 建议 **GPIO4**（Arduino 下 `LED_PIN 4`）。
- 避开：GPIO0/2/3/9/10（上电 strapping）、GPIO1/3（UART0）。
- **灯板不要和喇叭共用一路电源**（功放 12V、数字 5V 分开），否则底噪会串进音频。

### 4.3 两块串联

- 第一块 **OUT → 第二块 IN**，用一小段 4 芯线（或 3 芯：5V/GND/DATA 都并过去）；
- **两块必须同朝向**（都 LED 面朝前 / 都照片这面朝后）。串反了第二块不亮或乱闪；
- 并排横放时：左板的 OUT（右手边）→ 右板的 IN（左手边），自然连通；
- ** firmware 要按 9 个逻辑光点映射 50 颗物理灯**（拼缝那 1 列物理上断开，不映射的话曲线正中间永久缺一格）。

### 4.4 电流（别开满）

| | 值 |
|---|---|
| 降压模块持续 | **1.6 A**（峰值 3A，别当 3A 用） |
| 50 颗 WS2812 满亮 | 3.0 A ❌ |
| **120/255 亮度上限** | ≈1.4 A + ESP32 0.1A ≈ **1.5 A** ✓ |

**亮度上限 120/255 这条，从估算变成硬依据，固件照做。**

### 4.5 一个 3 行代码的库

ESP32-C3 用 Arduino IDE：**Adafruit NeoPixel**（走 RMT，稳）或 **FastLED**。
烧录前先在台面上点一颗灯验证，别等装进壳再调。

---

## 5. 装配顺序（照这个走，别跳）

1. **台面点亮测试**（最重要，也最容易被跳过）——
   三根飞线焊好、接 5V、ESP32 烧一个最简单的 `setPixelColor(0, 255,0,0)` +
   `show()`，看第一颗灯亮。**亮了再往下走**，不然装进壳发现不亮要拆头壳。
2. 两块**串联点亮测试** —— 确认 OUT→IN 方向对、9 逻辑列映射前先能全亮。
3. 光腔后壁做 **2 个定位柱**（Ø3 × 伸 5）+ 4 个热熔螺母（方案 A 才需要；方案 C 只做定位柱）。
4. 灯板背面贴 3M / 或套定位柱 + 沉头螺栓预拧。
5. 穿线、理线（24AWG 硬线要留走线槽），光缝内侧**先不要封**。
6. 通电再验一次出光是否均匀、有无个别亮点（亮点 = 那颗虚焊，趁现在换）。
7. 合 P2 后盖 → 装腿。

> 顺序里的 1、2 步在 `03` 的 12 步装配里也有，位置在"台面上焊完并调试全部电路"之后、
> "做光箱"之前。**先亮灯，再进壳。**

---

## 6. 三个会咬你的坑

1. **朝向。** LED 面朝前；照片那面朝后。两块装反朝向 → 数据方向反了，第二块乱闪。
2. **拼缝那 1 列。** 2 块 = 10 列物理，但物理中间断一格 → 固件按 **9 个逻辑光点**映射。
3. **亮度。** 120/255 封顶，别为了"让曲线更明显"把亮度拉满 —— 降压持续 1.6A，满亮会过载。

---

## 7. 与光缝的接口（建议顺手定，成本仍是 0）

`03` 写光缝 96 长 × 6 高，`04` 写 3 —— **两处打架，`11` 已建议统一取 12（B 档）**。

这里再加一条跟灯板直接相关的：

- **灯板 78 宽 < 光缝 96 长** → 光缝两端各 9mm 灯板够不着，两端会漏黑 / 光不均。
- **建议：光缝宽度收到 80（灯板 78 + 每边 1）**，或干脆按 `11` §9 表情方案做成 **78 宽**（与灯板同宽），这样光口正好被灯板填满，四角固定点（在 ±16.5 附近）落在光口**外侧实体**里 —— 顺带把 §3 那个"螺丝头掉进光缝"的问题一起解决了。

**P4 喙面板还没建，现在改还是零成本。**

---

## 8. 待办

| # | 事项 | 卡着什么 |
|---|---|---|
| 1 | 量灯板 4 孔孔径 + 孔距 | 光腔后壁定位柱位置（进 SW） |
| 2 | 台面点亮测试 | 不卡任何结构，今晚就能做 |
| 3 | 定光缝宽度 96 → 80 | P4 建模（喙顶 Y 那个数还没给） |
| 4 | 补 4 颗 M3×12 沉头（买） | 若走方案 A |

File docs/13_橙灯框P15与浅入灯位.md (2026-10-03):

# 13 · 橙灯框 P15：把灯「浅入」到橙色头部上

> 起因：2026-10-02 晚，用户提出「我做鸭子的橙色头部的部分，然后头上面的面往里面浅入一点点，用于放置灯片，好吗」。
> 这是灯光方案的 **v4**，相比 v1~v3 最大的不同：**灯从腔内搬到了脸外表面**。

---

## 0. 先说结论

| 问 | 答 |
|---|---|
| 这个思路行不行 | **行，而且是目前所有方案里最顺的一个** |
| 你比我先想到的那一点 | ✅ **坑不能挖在 P1 前脸上** —— 脸只有 2.5mm 厚，挖 4mm 就打穿、直通声学腔（喇叭漏气，低频全丢）。坑必须挖在**橙件**上 |
| 卡在哪一个数 | **橙外罩 68 宽 < 灯板 78 宽**。一块橙件想同时罩住「眼（Ø48，中心 Y=+16）」和「灯（78 宽）」，必须做到 84 宽 × 101 高 ≈ 整张脸都是橙 → 配色崩 |
| 解法 | **橙件拆成两块**：P14（眼区 68×68，已有不动）+ **P15 橙灯框（灯区 84×30×4，新件）** |
| 「浅入一点点」是多少 | **1.2mm**。板厚 2.8 搁在 4mm 深的窗里 → 灯板正面比橙框外表面**低 1.2mm**，四周被 4mm 高的橙边围住 |
| 还差最后一刀 | 窗不能开到 78×33（那会把整块黑 PCB 亮在脸上）。**窗收到 78×16**，上下各留 4 / 10mm 橙实体挡住灯的上下两端 |
| 代价 | 脸下部 30mm 被橙框占满 → **P4 喙仍然要让位**（见 §6） |

---

## 1. 为什么「坑挖在橙件上」是对的（这条其实是你先想到的）

P1 前脸厚度 **2.5mm**（`11` §2.5 里的脸外表面到内腔底）。

| 想在脸上挖的坑深 | 结果 |
|---|---|
| 3.0mm | 打穿脸 → 声学腔直通大气 → 喇叭漏气、低频丢、可能啸叫 |
| 2.0mm | 勉强剩 0.5mm 实料，太险 |
| **0（不挖脸）** ✅ | 橙框自己 4mm 厚，正面开穿成窗，窗后**就是 P1 的脸面** —— 灯板贴在这片脸面上，**脸一块料都不用挖，通气风险为零** |

而且附带一个好处：**灯板贴脸外表面 = 从前往后装**，不用从后口伸进腔内摸黑拧螺丝（v3 方案里最难受的一步没有了）。

---

## 2. 新零件 P15 · 橙灯框（尺寸表）

原点：**框心**（相对眼心 Y = −34.5，即绝对 Y = −51 ~ −21 的中点）。
Z=0 贴在 P1 脸外表面，朝外 +Z。

| 项 | 值 | 依据 |
|---|---|---|
| 外形 | **84（X） × 30（Y） × 4（Z）** | X：脸 96，两边各留 6；Y：框顶 −21（橙外罩底 −18 下留 3mm 奶油分型线）、框底 −51（脸底） |
| 圆角 | 四边 **R1.5** | 与 P14 的 R5 呼应，别做成尖角 |
| **正面窗（贯穿）** | **78（X） × 16（Y）**，通框全厚 | 78 = 灯板宽（灯板塞满窗，两端不漏黑 ← §12 §7 那个问题顺手解决）；16 = `11` §8 的 **D 档** |
| 窗绝对位置 | **Y −25 ~ −41**（中心 **−33**） | 对准灯板第 2/3 行灯珠中心跨度中点 −32.9 |
| 框上边（窗上沿到框顶） | 4mm | −21 ~ −25 |
| 框下边（窗下沿到框底） | 10mm | −41 ~ −51 |
| 材质 | PETG，橙 **#F26B21** | 与 P14 同批漆 |
| 数量 | 1 | |

### 2.1 灯板摆位

| 项 | 值 |
|---|---|
| 灯板 | 78（X） × 39（Y） × 2.8，2 块并排 |
| 贴哪 | **P1 脸外表面（z=0 平面），LED 面朝 +Z（朝外）** |
| 板心 **Y = −31** | 板 −50.5 ~ −11.5；板底距脸底 −51 留 **0.5mm**（卡死）；板顶 −11.5 藏在橙外罩后面（外罩底 −18）✓ |
| 可见部分 | 只在窗 **−25 ~ −41** 这段露出来（16 高） |
| 被遮部分 | 板 −50.5~−41 和 −25~−11.5 两段被 P15 橙实体挡住 → **PCB 底板、四周焊盘、排针全部看不见** ✓ |
| **浅入量** | 窗深 4 − 板厚 2.8 = **灯板正面比橙框外表面低 1.2mm** ← 这就是「往里面浅入一点点」 |

### 2.2 为什么窗必须是 16 而不是 33

| 窗高 | 结果 |
|---|---|
| **33**（全露） | 78×33 的黑 PCB 整片亮在脸上下部 —— 完成度红线明写「不是『贴上去』」。出来是「一块小屏幕」 |
| **16** ✅ | 只露中间 2 行灯珠（中心 −36.8 / −29，跨度 7.8 ⊂ [−41,−25]）；上下各 4 / 10mm 橙实体挡住 PCB。正面读出来是「**一条发光的横槽**」 |
| 12 | 更保险，但 2 行灯珠（Ø5）在 12 高里只剩 3.5mm 缝，光糊成一条线，点阵感消失 |

**16 是「看得出是灯、又不像贴了块屏」的最大值。** 再往上就踩 §2.5 那个扩散悖论（`11` 文档）。

---

## 3. 固定：不用螺丝，用 3M VHB + 2 颗定位柱

跟灯板一个判据（§12 §2）：**薄件在脸上是不受力的，它被「贴」进去，不是被「锁」进去。**

| 项 | 做法 |
|---|---|
| 主固定 | P15 背面（贴脸那面）整面贴 **3M VHB 4910 / 505**，压在 P1 脸外表面 |
| 定位 | 框上沿 2 颗 **Ø3 圆销**朝腔侧伸出 4，插进 P15 上边实体里的 2 个 Ø3.2 孔 → 定上下位置 |
| 返修 | 热风枪 80℃ 可撕，或撬开（橙框不是受力件） |
| 为什么不用 4 颗 M2 | 框高只有 30、窗 16 → 上边实体仅 4mm 高，**放不下 Ø4.0 沉头 + Ø3.0 孔** |

> 如果 VHB 不放心：退路是 **2 颗 M2×10 从腔内拧**，位置取框左右两端（X ±38、Y −24 与 −47），
> 长度复核：沉头 1.2 + 穿脸 2.5 + 咬合螺母 3.0 = 6.7 → **M2×10 富余 3.3** ✓。但优先走胶体。

---

## 4. SolidWorks 建模步骤（P15）

1. 新建零件 **P15 · 橙灯框**，原点 = 框心（绝对 Y = −34.5），Z=0 为贴脸面
2. **凸台-拉伸**：前视基准面 → 84 × 30（相对原点智能尺寸）→ 拉伸深度 **4**，方向朝 +Z（朝外）
3. 四边 **倒角 R1.5**
4. **切除-拉伸（通）**：同一基准面（或正面）画 78 × 16 矩形，
   - X 相对原点 ±39，
   - Y 距框**上边 4**、距框**下边 10**（这两个数直接标智能尺寸，别标窗心，避免后面算反）
   - **终止条件：完全贯穿**（这口就是要穿透 4mm 的框，露出后面的脸面）
5. 自检 Ctrl+8：**窗是通的（能看到后面的东西）、框四周是实体、板面在窗里低 1.2**
6. 保存，进装配体，Z=0 面与 P1 脸外表面 **重合配合**

### 4.1 进 SW 前先确认两件事

- **P1 脸外表面在 78×39 这块区域（Y −50.5 ~ −11.5）必须是平的。** 腔内的横杆 / 四片三角板 / 加强筋如果顶到脸背面，灯板贴不实。先转腔侧看一眼那块区域。
- **灯板导线怎么出。** 灯板贴在脸**外**面，线要回到 ESP32（在身部），只能：
  灯板背面 → 沿脸面下沿（−50.5 到 −51 那 0.5mm 缝）→ 绕过脸下沿进腔 → 走颈 P7 下到身部。
  **DIN 必须软硅胶线**（24AWG 镀锡线太硬会顶着脸面和橙框）。

---

## 5. 装配顺序（改了一步）

1. ✅ 已完成：台面点亮测试（`12` §5，今晚就能做）
2. P1 脸外表面那块区域清理平整
3. **先在脸面上贴灯板**（胶体）+ 2 颗定位柱定灯位
4. 从灯板底沿引线进腔、理线（此时腔是敞开的，好走线）
5. **再扣 P15 橙灯框** —— 顺序不能反：先灯后框，框压住灯的上下两端
6. 橙外罩 P14 照旧压在上边（Ø48 圈 + Ø52 沉台，护住方兰）
7. 腔内装电路、穿线 → 从后口伸进腔内拧合壳 M3×10（P1↔P2）→ 合 P2

---

## 6. 代价：P4 喙仍然要让位（v3 的结论不变，但让位方式变了）

橙灯框占掉脸下部 **−21 ~ −51** 共 30mm，而：

- P4 喙面板 = 100 宽 × **29 高**，若贴脸下部 → 顶在 −22 左右，正好压在窗（−25~−41）上 → **喙会把灯遮掉**
- 窗是发光的，喙是凸出的实体 —— 两者在正脸重叠，必须砍一个

三个退路（按推荐排序）：

| 退路 | 做法 | 代价 |
|---|---|---|
| **① 合二为一** ⭐ | 取消独立喙 P4，把「喙」做成 P15 橙框**往下伸出的那 10mm 边 + 前伸 3~4mm** —— 橙框自己就是喙的「根」，保持前伸下倾的语汇 | 喙变矮（≤14 高），形态语言削掉一半 |
| ② 喙压到最下沿 | 喙 14 高，Y −37 ~ −51，前伸 10 | 喙几乎只剩一条边 |
| ③ 取消喙 | 正脸 = 橙顶盖 / 橙眼框 / 橙光槽，三段横向分区（MicroDuck 的几何分件语言） | 六条设计语言里「喙的语言」没了 |

**我的建议是 ①**：橙框下沿前伸 3~4mm = 一条有厚度的橙色压条，既保住「橙色」这个色的落点，又不用一个新零件。

---

## 7. 这条路相对 v3 省了什么 / 多了什么

| | v3（灯在腔内 + 光口 32） | **v4（本方案）** |
|---|---|---|
| 净空约束 | 30.5mm（外罩底 → 内腔底） | **无约束**（灯贴脸外表面，脸 96×102 随便放） |
| 挖脸 | 不用挖 | 不用挖（框开穿，脸一块料不动） ✓ 不漏气 |
| 灯板装配 | 从后口伸进腔内、贴内腔底摆死 | **从前往后贴**，看得见摸得着 ✓ |
| 走线 | 腔内穿线 | 脸下沿绕进腔，仍要过颈 → 差不多 |
| 固定 | 定位销 + 胶体（腔内黑） | 胶体（脸外，好操作）✓ |
| 新零件 | 0 | **+1（P15）** |
| 灯板摆位自由度 | 被 30.5 卡死，只能贴底摆死 | 自由（本方案定 Y=−31） |
| 喙 | 必须砍 | 仍要砍，但可以「橙框下沿前伸」救回一点 |

**净结论：省掉的是「腔内黑摸装配」和「净空 30.5 的死约束」，代价是 +1 个零件。这笔账划算。**

---

## 8. 待办

| # | 事项 | 卡谁 |
|---|---|---|
| 1 | **SW 里确认 P1 脸外表面 Y −50.5 ~ −11.5 那块是平的**（横杆/三角板别顶出来） | P15 能贴实 |
| 2 | **量灯板四孔孔径 + 对角孔距**（`12` §1，仍未量） | 定位柱 Ø3 的位置 |
| 3 | 定 P4 喙的三选一（建议 ① 橙框下沿前伸 3~4） | 锁 P15 底边 / 光窗位置 |
| 4 | 量/确认「喇叭高 52 还是 35」那个老悬案 | 头高链 |
| 5 | 采购：无新增（胶体 + 2 颗 Ø3 圆销） | — |

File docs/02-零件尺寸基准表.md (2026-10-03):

# 零件尺寸基准表 · Learned Duck

> **这是建模的唯一数据源。**
> `01-零部件测绘表.md` 是"要量什么"（方法与清单），这张表是"实际用什么数"（数据与出处）。
>
> 每个数字都标了来源——因为"这个数从哪来"决定了"万一错了要付多大代价"。
>
> | 标记 | 含义 | 使用方式 |
> |---|---|---|
> | **[实测]** | 游标卡尺量过 / SolidWorks 模型确认 | 直接用 |
> | **[清单]** | 采购清单 / 商品页标注 | 可作设计依据 |
> | **[官方]** | 厂商规格书 | 可作设计依据 |
> | **[预留]** | 数据缺失，按同类件上限取值 | **必须打试件验证** |
>
> **一条铁律：凡是 [预留]，一律往大留。** 装配体按最大值设计，才不会出现"装不进去"。

---

## 一、逐件数据

### 1. 喇叭（已建模 ✔）

| 项 | 值 | 来源 | 用在哪里 |
|---|---|---|---|
| 法兰外形 | **52 × 52 方形**，四角安装孔 | [实测]＋模型确认 | 决定正面沉台形状 |
| 振膜圆孔 | **Ø45** | [实测] | 正面通孔 |
| 总高（法兰面 → 磁钢底） | **35** | [实测] | 决定头壳内腔高度 |
| 四周侧窗 | 4 处弧形开口，中段方孔 | 模型确认 | 后腔需连通，不能贴实 |

**注意：这是方框法兰喇叭，不是圆形法兰。**（2026-10-01 已由 SolidWorks 模型确认——上视图中为带四角安装孔的方框。）
若正面按圆形沉台做，方框的四个角会悬空，法兰压不实、必然漏气。

> ⚠️ **尺寸链的"52 vs 35"已澄清**：`52` 指**法兰方形边长**（宽／深方向），`35` 指**总高**（进深方向）。
> 二者不冲突——头壳高度链取 **35**，不再取 52。

### 2. WS2812B 灯板 ×3 —— ❌ 已移出本版

> **2026-09-28 用户决定：本版不做灯板。**
> 光腔、扩散板、导光缝三处结构随之作废，头壳内腔高度链解锁（原为迁就灯板 39 而压到 102）。

| 项 | 值 | 来源 | 处置 |
|---|---|---|---|
| 单片 | 39 × 39 × 2.8 | [实测] | 本版不用 |
| 像素 | 5 × 5 = 25 颗，5050 封装 | [清单] | — |

**但保留接口**（这是"建模课不做硬件、但留可选基础"的落点）：
- ESP32-C3 的 **GPIO 预留位、5V／GND 输出焊盘照留**，固件里保留灯光模式表与 NVS seed 接口
- 头壳**只降高度、不减壁**：内腔顶面仍留 2 mm 加强层。将来想加灯，贴一片柔性灯带（约 1.5 mm）比塞 39 mm 的硬灯板容易得多
- 头壳正面顶部的**光缝槽保留**（深 1.5，靠前缘），先当造型分型线用；装灯带时即是出光口
- 底壳的 24 × 24 二维码位与 `trained, not designed` 刻字不受影响

### 3. 蓝牙功放板（已建模 ✔）

| 项 | 值 (mm) | 来源 | 用在哪里 |
|---|---|---|---|
| **最长边** | **50.2** | [实测] 2026-10-01 | 身内腔布局 —— 71 的内腔够用 |
| 板面 | 约 50.2 × 32（由模型比例） | 模型确认 | 板面布局 |
| 总高（含元件与接线端子） | **14.5** | [实测] | 板上方净空 |
| 接线端子 | 竖立 6 孔，位于板的一端 | 模型确认 | 该端需留走线空间 |
| 板厚 | 约 1.6 | 模型确认 | — |

> **「66 max」已闭合**：实测最长边 **50.2**，那个数字不是板长。
> **结论：身壳 76 × 52 × 64 不用改。**

### 4. ESP32-C3-Zero（微雪 Waveshare）

| 项 | 值 | 来源 | 用在哪里 |
|---|---|---|---|
| 板本体 | **23.5 × 18** | [官方] | 安装位 |
| 实测外形 | **17.8 × 25 × 5**（含排针与 USB 口高度） | [实测] | 净空 |
| 引脚间距 | 2.54 | [官方] | 排针 / 焊接 |
| 可用 GPIO | 15 个 | [官方] | 接线 |
| 天线 | **陶瓷贴片（SMD）**，位于板端 | [官方] | **该端 10 mm 内不得有金属** |
| 供电 | 5V（USB-C 原生，无需转换芯片） | [官方] | 与降压模块对接 |

### 5. DC-DC 降压模块（欣薇电子）

| 项 | 值 | 来源 | 用在哪里 |
|---|---|---|---|
| 模块尺寸 | **22.3 × 17 mm** | [官方] | 身内腔布局 |
| **厚度** | **2**（用户实看） | [实测] 2026-09-28 | 与功放板叠放 |
| 重量 | 3 g | [官方] | 配重计算 |
| 输入 | 7–26 V（12V 输入可用） | [官方] | — |
| 输出 | 5V；**峰值 3A / 持续仅 1.6A** | [官方] | **见第二节** |

> 厚度 2 mm 比原 [预留] 5 mm 乐观 —— 身内腔高度更宽松，功放板 ＋ 降压模块叠放约需 **19**，内腔高 47 绰绰有余。

### 6. DC022 电源插座

| 项 | 值 | 来源 | 用在哪里 |
|---|---|---|---|
| **面板开孔** | **Ø12** | [清单] | 身壳开孔 |
| 规格 | DC5.5-2.1，带螺纹 | [清单] | — |
| 可夹持壁厚 | 约 8–10（壁 2.5 需加垫圈） | [预留] | 锁紧方式 |

### 7. Ø10 金属按钮

| 项 | 值 | 来源 | 用在哪里 |
|---|---|---|---|
| **面板开孔** | **Ø10** | [清单] | 身壳开孔 |
| 类型 | 高头、**自锁式**（按下锁住 / 再按弹起）、短款 2 插脚 | [清单] | 灯光模式切换 |
| 头部外径 | 约 Ø12–13 | [预留] | 外观占位 |

### 8. 拨动开关 SS12F15V（G6，2 档 3 脚）

| 项 | 值 (mm) | 来源 | 用在哪里 |
|---|---|---|---|
| 总长（含两侧安装耳） | **15.6** | [清单] | 安装位 |
| 本体高 | **5.8** | [清单] | 净空 |
| 引脚间距 | **3** | [官方规格书] | 焊接 |
| 拨杆露出高 | 约 2.2 | [清单] | 面板开孔 |
| **拨杆行程** | **约 3.2** | [官方规格书] | **决定开孔长度** |
| 额定 | DC 50V 0.5A | [清单] | 仅作信号开关，不切负载 |

**面板开孔（推算）**：长条孔 **6 × 2.5**（行程 3.2 ＋ 拨杆宽 ＋ 余量）。
开孔前先用硬纸板做一次拨杆行程模拟——开短了开关拨不到底。

### 9. 紧固件

| 零件 | 关键尺寸 | 来源 | 备注 |
|---|---|---|---|
| 热熔铜螺母 M3×5×4.5 | **外径 Ø4.5，长 5**，内 M3 | [清单] | 压入孔 Ø4.1 |
| 热熔铜螺母 M2×3×3 | **外径 Ø3.0，长 3**，内 M2 | [清单] | 压入孔 Ø2.7 |
| 沉头螺丝 M3×5 | **头径 4.5** | [清单] | 沉头窝 Ø4.7 × 深 1.2 |
| 沉头螺丝 M2×5 | 头径约 3.5 | [预留] | — |

### 10. 跳线

| 项 | 值 | 来源 |
|---|---|---|
| 规格 | 1007 双头镀锡 **24AWG**（铜芯约 Ø0.51） | [清单] |
| 长度 | 8 / 10 / 15 / 20 cm，共 140 条 | [清单] |
| 注意 | 镀锡线偏硬，**箱内必须留走线槽**，否则会顶住盖板 | — |

---

## 二、三条改变设计的发现

### 发现 1 · 喇叭是方框法兰，不是圆形法兰

- **原设计**：正面 Ø45 通孔 ＋ Ø52.6 **圆形**沉台
- **修正为**：正面 Ø45 通孔 ＋ **52.6 × 52.6 方形沉台（深 5）**，四角配 4 × M2 热熔螺母柱

不改的后果：方框法兰的四个角悬在圆沉台之外，压不实 → 漏气 → 低频全丢，还会啸叫。

### 发现 2 · 降压模块持续电流只有 1.6A，不是 3A

商品页原话：**"输出电流 3A（峰值），长时间工作控制在 1.6A 以内"**。

| 项 | 电流 |
|---|---|
| 50 颗 WS2812B 全白满亮 | **3.0 A** |
| 降压模块可持续输出 | **1.6 A** |
| 亮度 120/255 时（灯阵） | 约 1.4 A |
| ＋ ESP32-C3 | 约 0.1 A |
| **合计** | **约 1.5 A —— 安全** |

**结论：固件里 120/255 的亮度上限是对的，现在有硬依据，不是估的。**
本版不做灯板，这条约束暂时用不上；一旦加灯带，它立刻生效。

### 发现 3 · 不做灯板 → 头壳可以更薄

灯板高 39，原本是头壳高度链里最大的一项。去掉后：

| 方案 | 头壳高度链 | 头高 |
|---|---|---|
| 原（带灯板） | 法兰 5 ＋ 喇叭 35 ＋ 隔板 3 ＋ 灯板 39 ＋ 顶壁 8 ＋ 底壁 12 | **102** |
| **现（无灯板）** | 法兰 5 ＋ 喇叭 35 ＋ 后腔净空 12 ＋ 顶壁 8 ＋ 底壁 10 | **70** |

**头高可从 102 降到 70**，整机总高从 216 降到约 **184**，体积再降约 32%。

> ⚠️ 但这是"物理最小"，不是"看起来最好"。
> **建议先按 84 做**（= 70 ＋ 14 的余量）：一是留出 2 mm 加强层 ＋ 柔性灯带的将来空间，二是**给后腔净容积留余地**——52 mm 全频喇叭的后腔低于 0.35 L 时低频会明显发干，而头壳扁到 70 时后腔只剩约 0.30 L。
> 造型上，头从 102 收到 84 也比收到 70 更接近 MicroDuck 的头部比例（它的头明显不是薄片）。

---

## 三、仍未闭合的数字

清点结果：**只剩 0 个必须量、2 个建议确认。**

| # | 什么 | 状态 | 影响 |
|---|---|---|---|
| 1 | 灯板第二边 | ❌ **作废**（本版不用灯板） | 无 |
| 2 | 降压模块厚度 | ✔ **已定 = 2 mm**（用户实看） | 身内腔高度更宽松 |
| 3 | 功放板「66 max」 | ✔ **已闭合 = 50.2**（实测） | 身壳不用改 |

**可以建模了。** 唯一还值得做的实测是「外壳打印公差」——这个不用量零件，打一个 20 × 20 × 10 的测试块就行（含螺母柱、通孔、沉头窝各一），20 分钟出结果。

---

## 四、外壳硬边界（由上述数据推出）

> **本表已按"不做灯板"修订。** 头壳高度从 102 收到 **84**（折中值，理由见发现 3）。

| 段 | 外形 (mm) | 内腔 (mm) | 由谁决定 |
|---|---|---|---|
| 头 | 96 × **84** × 62 | 91 × 79 × 57 | 单喇叭 52 方居中；Ø45 通孔 ＋ 52.6 方沉台深 5；后腔净空 12＋ |
| 颈 | 高 26 | 穿线通道 | 2 × M4 螺纹杆 ＋ 线束 |
| 身 | 76 × 52 × 64 | 71 × 47 × 59 | 功放板 50.2 × 32 × 14.5 ＋ 降压 22.3 × 17 × 2 ＋ ESP32 ＋ DC 座 ＋ 开关 ＋ 配重钢板 60 × 40 |
| 四足 | 腿高 36，截面 20 | — | 髋支架 4 处 ＋ 12 档定位齿盘 |
| **总计** | 总高 ≈ **198** | | 脚距 左右 128 / 前后 112 |

**两种口径，先记下来，签图时二选一：**

| | 头高 | 总高 | 后腔净容积（估） | 适用 |
|---|---|---|---|---|
| **A · 折中（推荐）** | **84** | **198** | 约 0.38 L | 造型比例稳、将来能加灯带 |
| B · 极限最小 | 70 | 184 | 约 0.30 L | 追求最小体积，接受低频偏瘦 |

---

## 五、3D 打印约束速查（建模直接套）

| 项目 | 规则 |
|---|---|
| 最小壁厚 | 1.6 mm；承力柱 / 螺母柱 2.0 mm |
| 热熔螺母柱外径 | M3 螺母（Ø4.5）→ 柱外径 **≥ Ø7.0**；M2 螺母（Ø3.0）→ **≥ Ø5.5** |
| 螺母压入孔 | 比螺母外径小 0.2–0.4：M3 → **Ø4.1**；M2 → **Ø2.7** |
| 螺丝通孔 | M3 → Ø3.4；M2 → Ø2.4 |
| 沉头窝 | M3 头径 4.5 → 窝 **Ø4.7，深 1.2**，90° |
| 打印公差 | ±0.2–0.3；所有配合面留 **0.3** 装配间隙 |
| 螺纹配合 | 打印件不攻牙，一律用热熔螺母 |
| 喇叭密封 | 法兰下垫 **2 mm 闭孔泡棉环**；先做气密测试再进头壳 |
| 天线净空 | ESP32 陶瓷天线端 **10 mm 内不得有金属、不得贴死壳壁** |
| 走线 | 线槽截面 ≥ 5 mm²；12V 电源线与信号线分开走 |
| 装配可达性 | 建模时先想一遍螺丝刀怎么伸进去——翻车率最高的一项 |

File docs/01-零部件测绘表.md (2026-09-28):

# 智能蓝牙音箱 · 零部件测绘表

> 对应作业要求第 1 条：**通过测量零部件尺寸，确定零部件在内部的堆叠方式**。
> 这张表是后面所有造型、结构、开孔的**唯一数据源**。数字错 1mm，外壳就可能装不进去。
>
> 测量工具：游标卡尺（不用卷尺、不用目测）
> 记录精度：**0.1mm**（开孔类尺寸也顺势记到 0.1mm）
> 填写方式：直接在本文件「实测」列填数字，或在纸上记完回填。

---

## 一、逐件测量项

### A. 蓝牙功放板（立体声蓝牙功放，12V 输入）

| 测量项 | 实测 | 备注 |
|---|---|---|
| 板长 L × 板宽 W | | mm |
| PCB 板厚（不含元件） | | 通常 1.6mm |
| **最高元件高度**（电容 / 接线端子 / 天线） | | 决定板上方净空 |
| 安装孔：孔径 / 孔距（X、Y）/ 距板边 | | 有几孔记几孔 |
| 接线端子：数量 / 单点间距 / 离板边距离 / 接线高度 | | 12V、GND、R+、R−、L+、L− |
| 板背面是否有引脚凸出 | | 决定板下支撑高度 |
| 蓝牙天线位置（板沿哪一侧） | | 该侧外壳**不可贴金属、不可贴死** |

### B. 喇叭（2 寸全频，52mm，4Ω 10W）×2

| 测量项 | 实测 | 备注 |
|---|---|---|
| 法兰（外框）直径 | | 标称 52mm，实测为准 |
| 法兰厚度 | | 决定面板沉孔深度 |
| 总高（法兰面 → 磁钢底面） | | **决定箱体最小深度** |
| 磁钢直径 | | 影响内部排布 |
| 安装孔：孔数 / 孔距 / 孔径 | | 无孔则记录靠压紧/胶粘 |
| 接线焊盘位置 | | 正负极端子是否朝上 |
| 丝印标注 | | 阻抗 / 功率 |

### C. DC022 直流电源插座（DC5.5-2.1）

| 测量项 | 实测 | 备注 |
|---|---|---|
| 螺纹外径 | | 标称开孔 Ø12mm |
| **实际建议面板开孔直径** | | 用卡尺量螺纹外径再 +0.2~0.3 |
| 可夹持面板厚度范围 | | 太厚拧不上螺母 |
| 总长（含引脚） | | 决定内腔深度 |
| 引脚间距 / 引脚直径 | | 焊接用 |
| 中心针规格 | | 5.5-2.1mm |

### D. 金属按钮（10mm，自锁式）

| 测量项 | 实测 | 备注 |
|---|---|---|
| 头部外径 | | |
| **开孔直径** | | 标称 Ø10mm |
| 可夹持面板厚度范围 | | |
| 头部高出面板高度 | | 影响造型外观 |
| 总长 / 引脚间距 / 线径 | | 短款 2 插脚 |
| 功能确认 | | 标称「自锁」= 按下锁住，再按弹出 |

### E. 拨动开关 SS12F15V（2 档 3 脚，卧式直插）

| 测量项 | 实测 | 备注 |
|---|---|---|
| 本体长 × 宽 × 高 | | |
| 拨杆长度 / 直径 | | 决定面板开孔样式 |
| **面板开孔建议尺寸** | | 条形孔还是方孔，实测拨杆行程 |
| 引脚间距 / 引脚长度 | | 3 脚间距是否 2.54 |
| 档位确认 | | 标称 2 档 |

### F. DC-DC 降压模块（3A 固定 5V）

| 测量项 | 实测 | 备注 |
|---|---|---|
| 板尺寸 | | 标称 22.3 × 17mm |
| 总高 | | 含电感最高点 |
| 输入 / 输出焊盘位置与间距 | | 布线走向用 |
| 是否可调（或有电位器） | | 标称固定 5V |

### G. ESP32-C3-Zero 开发板（微雪 ESP32-C3FH4）

| 测量项 | 实测 | 备注 |
|---|---|---|
| 板尺寸 | | |
| 排针间距 | | 标准 2.54mm |
| 总高（含 USB-C 接口） | | USB 口要么露出来、要么留出烧录窗口 |
| 天线位置（板端哪一侧） | | **该区域 10mm 内不可有金属/紧贴壳壁** |
| 引脚可用性 | | 记录实际接线脚位（5V、GND、数据脚） |

### H. WS2812B 5×5 彩灯板 ×3

| 测量项 | 实测 | 备注 |
|---|---|---|
| 单块板尺寸（长 × 宽 × 厚） | | |
| 灯珠间距（中心距） | | 决定灯阵像素感 |
| 灯珠外径 | | 5050 封装 |
| DIN / DOUT 焊盘位置 | | 串联顺序用 |
| 供电电压 | | 5V |
| **用几块 / 怎么拼** | | 3 块可以拼 5×15 或 10×10 减一块，**这个决定要现在定** |

### I. 跳线（1007 双头镀锡 24AWG）

| 测量项 | 实测 | 备注 |
|---|---|---|
| 线径 / 铜芯直径 | | 24AWG ≈ Ø0.51mm 铜芯 |
| 可用长度规格 | | 8 / 10 / 15 / 20cm |
| 线身是否偏硬 | | 镀锡线偏硬，**箱内必须留走线槽**，否则会顶住盖板 |

### J. 紧固件（已知，核对即可）

| 零件 | 规格 | 用途 |
|---|---|---|
| 热熔铜螺母 | M3 × 5 × 4.5（外径约 Ø4.5，长 5） | 上下壳连接柱 |
| 热熔铜螺母 | M2 × 3 × 3（外径约 Ø3，长 3） | 小板件固定 |
| 沉头螺丝 | M3 × 5（头径约 Ø5.6~6，90° 沉头） | 外壳主连接 |
| 沉头螺丝 | M2 × 5 | 小件固定 |

---

## 二、3D 打印设计约束速查（建模时直接套用）

| 项目 | 规则 |
|---|---|
| 最小壁厚 | 1.6mm；承力柱/螺母柱 2.0mm |
| 热熔螺母柱外径 | M3 螺母 → 柱外径 ≥ **Ø7.0mm**；M2 螺母 → 柱外径 ≥ **Ø5.5mm**（两侧壁厚各 ≥1.2mm） |
| 螺母压入孔 | 比螺母外径小 0.2~0.4mm（M3 → Ø4.1；M2 → Ø2.7），**以实测螺母外径为准** |
| 螺丝通孔 | M3 → Ø3.4mm；M2 → Ø2.4mm |
| 沉头窝 | M3 头径 Ø5.6~6，锥角 90°，深度按实测头高 |
| 打印公差 | ±0.2~0.3mm；所有配合面留 **0.3mm 装配间隙** |
| 螺纹配合 | 3D 打印件不直接攻牙，一律用热熔螺母 |
| 喇叭后腔 | 2 寸全频建议净深 ≥ 15mm；喇叭与壳体接触面加**泡棉/密封胶**，避免漏气 |
| 天线净空 | ESP32 天线端与蓝牙天线侧，10mm 范围内不要金属、不要紧贴壳壁（否则信号衰减） |
| 走线 | 线槽截面 ≥ 5mm；电源线（12V）与信号线分开走，减少干扰 |
| 装配可达性 | 建模时先想一遍**螺丝刀怎么伸进去**——这是新手翻车率最高的一项 |

---

## 三、拍照归档要求

每件零件拍 **1 张俯视 + 1 张侧视**，能同时看到卡尺读数的更好。命名：

```
零件名_俯视.jpg / 零件名_侧视.jpg
```

放同一文件夹，后面做装配示意图和爆炸图时能直接引用，也方便我帮你核尺寸。

---

## 四、量完之后

把填好的表发我，我接着做两件事：

1. 核算并给出**箱体最小内腔尺寸**（长 × 宽 × 高）与各件的堆叠排布方案（2D 侧视 + 顶视）
2. 标出所有**必须预留的开孔与净空区**，作为造型设计的硬边界

> 记住顺序：**先量后画**。现在多花两小时测量，能省掉后面重打一整个外壳的时间。

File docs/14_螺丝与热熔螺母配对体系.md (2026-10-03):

# 14 · 螺丝与热熔螺母的配对体系

> 起因：2026-10-02 晚，用户问「我一直担心：我这个热熔螺母 M3×5×4.5，应该和什么款式的螺丝搭配使用」。
> 这份文档回答两件事：**① M3×5×4.5 配什么螺丝；② 现在whole项目里每一处固定点该用 M2 还是 M3、什么头型。**

---

## 0. 一句话结论

| 问 | 答 |
|---|---|
| M3×5×4.5 热熔螺母配什么螺丝 | **M3 沉头 / 半沉头（GB/T 68 / 69），长度 M3×10** |
| 能不能配盘头 / 内六角柱头 | **能配螺纹，但头会凸出表面** → 只用在**腔内、看不见的**位置 |
| 螺母外径 4.5 管什么 | 只管**它自己的安装孔**（Ø4.2~4.4 深 5.5），**不管螺丝头** |
| 螺丝头型由谁决定 | **由被连接件（壳壁）的沉台决定** —— 头型选错 = 螺丝头顶在沉台口上、沉不下去 |
| ⚠️ 抓到的冲突 | **P1 上 Ø5.5 的喇叭凸台喂不饱 M3 沉头**（头径 5.5 = 凸台直径，顶面会被挖穿）→ 那 4 颗应**退回 M2** |

---

## 1. M3×5×4.5 这个型号怎么读

热熔铜螺母（heat-set insert）的命名是 `螺纹 × 长度 × 外径`：

| 段 | 值 | 含义 |
|---|---|---|
| 螺纹 | **M3** | 内螺纹，螺距 **0.5**（标准粗牙）。决定"只能配 M3 螺丝" |
| 长度 | **5** | 有效螺纹长度 5mm → **螺丝杆最多只能吃进去 5mm** |
| 外径 | **4.5** | 本体大径 / 凸缘直径 → 决定**安装孔打多大** |

它**不是螺丝**，是一个"焊进塑料里的内螺纹基座"，用电烙铁/热熔枪压进预制孔里，之后一切通配 M3 螺丝。

### 1.1 安装孔怎么打（这一步才归它管）

| 项 | 值 | 提醒 |
|---|---|---|
| 孔直径 | **Ø4.2 ~ 4.4**（推荐 **4.3**） | 过盈 0.2~0.4 抓得牢。**别打满 Ø4.5** —— 过盈太小压进去会松、会转 |
| 孔深度 | **5.5**（= 5 + 0.5） | **孔底必须留 ≥0.5 实料**。打穿了螺母压进去会掉进腔里，或者底部透光 |
| 压到底的状态 | 螺母端面与孔口**齐平**，背面不能凸出 | 凸出会干涉相邻件 |
| 压入温度 | 电烙铁/热熔，别用火 | 铜导热快，塑料容易熔过头 |

---

## 2. 头型不是螺母决定的 —— 是"沉台"决定的

这条是本份文档最要紧的一句：

> **螺丝款式 ∝ 沉台；螺母只提供螺纹。**
> 三者关系链：**螺丝头型号 → 需要多大的沉台（Ø/深）→ 沉台开在哪个面 → 正面能不能藏住。**
> 螺母的唯一作用是：给你一个能拧的螺纹孔（M3 / M2），并且**它的长度上限 = 螺丝杆最多能拧进去多少**。

### 2.1 M3 各头型对照（GB 常用值）

| 头型 | 标准 | 头径 dk | 头高 k | 需要的沉台 | 表面状态 | 用在哪 |
|---|---|---|---|---|---|---|
| **开槽沉头** | GB/T 68 | **5.5** | **1.65** | Ø5.5 × 深 1.65 | ✅ 与面齐平 | 外表面 / 正脸 |
| **半沉头（十字）** | GB/T 69 | **≈5.5**（5.5~5.6） | **≈1.65**（+圆顶 0.2~0.3） | Ø5.5 × 深 1.65 | ✅ 微凸 0.2~0.3 | 外表面（**你手上有货 = 用它**） |
| 盘头 | GB/T 65 | 5.5 | 1.8 | 沉台也压不住（头顶是拱的） | ❌ 凸 0.3~0.8 | 腔内、被盖住的 |
| 圆头 | GB/T 67 | 5.5 | 1.8 | 同上 | ❌ 凸 | 同上 |
| **内六角圆柱头** | GB/T 70.1 | 5.5 | **3.0** | Ø5.5 × 深 3.0 | ❌ **凸 3.0** | **腔内承重件**（髋、腿关节） |

> 订正：§10.2c 里写「M3 半沉头头径 ≈5.0」是估偏小了，实际 **≈5.5**。
> 但那个判断（M3 塞不进我们按 M2 定的 Ø4.0 沉台）**结论不变**，因为 5.5 比 4.0 差得更远。

### 2.2 两个反直觉的点

1. **螺母外径 4.5 < 螺丝头径 5.5 是好事。** 螺丝头比螺母大一圈，压在零件表面上，**不会陷进螺母的外圈**，扭矩直接吃在壳壁平面上。如果反过来（头比螺母小），螺丝头会架空、一拧就歪。
2. **沉台深度 = 头高，沉台直径 = 头径。** 沉挖浅了螺丝头顶在孔口（沉不下去），挖深了正面会凹一个坑（外观破相）。**轻挖 0.1~0.2 比挖浅 0.5 好。**

---

## 3. 长度匹配公式（买螺丝前必算）

```
螺丝杆长 L ≥ 沉台深 k + 螺丝穿过的所有壁厚 t + 咬合长度 n
```
- `n` = 咬合长度，M3 螺距 0.5 → **n ≥ 2.0 保险**（4 牙）；追求牢就 3.0
- `L` 是**杆长（不含头高）**，买的时候标的数就是这个
- 螺丝杆能拧进螺母的上限 = **螺母长度 5** → 别让 L 超出太多，否则杆尖顶死螺母底

### 3.1 本项目三处算账

| 用途 | 沉台 k | 穿过的壁 t | 咬合 n | 最少 L | 该买 |
|---|---|---|---|---|---|
| **合壳 P1↔P2** | 1.65（在 P2） | P1 2.5 + P2 2 = **4.5** | 2.0 | **8.15** | **M3×10**（手上现成 ✓，富余 1.85） |
| 髋 / 腿关节 / 颈接口 | 凸台顶沉台 1.65 | 凸台 5.5 + 对件 | 2.5 | 视凸台 | M3×10（现成）/ M3×12（髋，09 清单 D4） |
| ⚠️ 喇叭法兰（P1 凸台） | 见 §5，**M3 不成立** | — | — | — | **退回 M2×10** |

### 3.2 手上那批 M3×5 螺丝（200 粒）用不用

**用不上，别往前壳上凑。**

M3×5 → 5 < 8.15，连合壳都拧不到底；拿来当**配重砝码**（塞配重槽里）是它最好的归宿，正好 `09` 清单说过这批"留作存货与配重"。

---

## 4. 孔的匹配（沉台 / 直孔 / 螺母孔三层别混）

一个固定点其实是**三个同心系列**的孔，尺寸层层不同：

| 层 | 位置 | M2 体系 | M3 体系 |
|---|---|---|---|
| ③ 沉台（给螺丝头） | 开口在**外表面**（需藏头） | Ø4.0 × 深 1.2 | **Ø5.5 × 深 1.65** |
| ③' 沉台（给螺丝头） | 开口在**腔侧**（头在腔内） | Ø4.0 × 深 1.2 | Ø5.5 × 深 1.65 |
| ② 直孔（给螺丝杆） | 贯穿被连接件 | Ø3.0 | **Ø3.2~3.5**（M3 杆齿顶 ≈2.76） |
| ① 螺母安装孔（给热熔螺母） | 埋在料里 | Ø2.8~3.0 × 深 3.5 | **Ø4.3 × 深 5.5** |

> **最常犯的错：拿 M2 的 Ø4.0 沉台去装 M3 沉头（头径 5.5）。** 结果螺丝头顶在孔口上、沉不下去，螺丝头浮在表面上 → 外盖压不平、法兰压不实（就是 `10` §12 那个"凸台顶端要开沉台"同款坑，只是这次是反向的）。

---

## 5. ⚠️ 本次抓到的冲突：Ø5.5 凸台装不下 M3 沉头

`10` §12 定过：P1 前脸 4 个喇叭法兰固定点 = **Ø5.5 凸台、高出脸面 5.5、顶端开沉台**。
后来 §13 审阅时把螺丝换成了 M3（因为装配树里全是 M3×8 / M3×10）。**这里有个几何硬冲突：**

- M3 沉头 / 半沉头头径 = **5.5**
- 凸台直径 = **5.5**
- → 凸台顶端要开一个 **Ø5.5** 的沉台 = **整个顶面被挖穿，只剩一圈壁厚为 0**

凸台就成了一个"杯子"，螺纹孔壁没了，M3 螺母压进去贴在杯底，螺丝头边缘悬空。**打印完必裂、一拧就崩。**

### 5.1 三个解法（按推荐排序）

| 解法 | 做法 | 代价 | 评价 |
|---|---|---|---|
| **① 退回 M2** ⭐ | 凸台 Ø5.5 顶开 **Ø4.0 × 深 1.2** 沉台（M2 头径 4.0，四边各留 0.75 实料 ✓），盲孔 Ø3.0 × 深 4.3，埋 M2×3×3，螺丝 **M2×10** | 要买 M2×10（约 4~6 颗） | **推荐** —— 凸台是照 M2 尺寸定的，本来就喂得饱 M2 |
| ② 凸台加粗到 Ø7 | 沉台 Ø6 / Ø7（M3 头 5.5 留 0.5~1 边），凸台高 6.0（见下文算账），螺丝 M3×12 | 凸台变大，占 Ø48 孔周围的料；要重打 P1 这 4 处 | 可行但要改 P1 |
| ③ 换短螺母 M3×3×4.5 | 凸台 5.5 不动，顶端不沉台直接压螺母，螺丝头落在凸台顶**平面**上 → 凸 1.65 | 法兰被顶起 1.65 → **泡棉气封失败、漏气** | ❌ **否决**（`10` §12 已论证过同一条） |

### 5.2 解法 ② 的算账（供参考）

凸台 5.5 高装不下 M3×5 长螺母（会顶到内腔）：

```
需要 = 沉台 1.65 + 螺母 5.0 + 内腔侧留料 1.5 = 8.15
可用 = 凸台高 + 脸厚 2.5 = 5.5 + 2.5 = 8.0  → 缺 0.15 ❌
→ 凸台高改 6.0：可用 8.5，富余 0.35 ✓（很紧，不推荐）
```
M2 就不缺：
```
需要 = 1.2 + 3.0 + 1.2 = 5.4；可用 5.5 + 2.5 = 8.0 → 富余 2.6 ✓ 宽裕
```
**这就是我推荐 M2 的算术理由 —— 不是口味，是凸台那个 Ø5.5 是照 M2 定的。**

---

## 6. 全项目螺丝体系总表（M2 / M3 分工）

| 固定点 | 被固定件 | 螺母 | 螺丝 | 头型 | 拧向 |
|---|---|---|---|---|---|
| **喇叭法兰** ×4 | P1 凸台 Ø5.5 | **M2×3×3** | **M2×10** | 沉头/半沉头 | **从正面拧**（头在喇叭面 → 被橙外罩吃掉） |
| **橙外罩 P14** ×4 | P14 厚 4 | **M2×3×3** | **M2×10** | 沉头/半沉头 | **从腔内往里拧**（头在腔内） |
| **橙灯框 P15** ×2（退路） | P1 脸 | M2×3×3 | M2×10 | 沉头 | 从腔内拧（优先用 VHB 胶体，见 `13` §3） |
| **合壳 P1↔P2** ×4 | P1 / P2 | **M3×5×4.5** | **M3×10** | 沉头/半沉头 | 从 P2 侧（背面，露头正常 ✅） |
| **髋 P10 / 腿 P11 P12 关节** ×8 | 腿上腿下 | **M3×5×4.5** | M3×10 / M3×12 | 内六角柱头也行（腔内，看不见） | 腔内 |
| **颈接口 P7** ×2 | 颈 ↔ 身 | **M4 热熔螺母**（`09` A5，尚未买） | M4×?? | 沉头 | 全头唯一主受力连接 |
| 灯板 | 光腔后壁 / 脸面 | **胶体 + 定位销**（`12` §2 方案 C） | — | — | 不拧 |

> **两套并存的原因（不是混乱）：**
> - **M2** = 前脸正面的所有点（凸台 Ø5.5 喂得饱 M2、头径小、凸台薄地方放得下）→ **关系是"正面藏头"**
> - **M3** = 腔内 / 背面 / 承重的点（壁厚够、看不见，无所谓沉台）—— 而且 **M3×10 是你手上现成的**
> - 两者**不能互换到对方的位子上**：M3 塞不进 Ø4.0 沉台，M2 的短杆够不到 8.15 的深度。

---

## 7. 买螺丝时怎么写（别只写"M3 螺丝"）

电商/五金店下单要写全这 4 项，缺一项就发错：

```
M3 × 10      公称长度 10（杆长，不含头）
沉头 / 半沉头   GB/T 68（沉头）/ GB/T 69（半沉头）
十字盘头槽     十字
粗牙（标准）   螺距 0.5
```

**数量（按上面总表重算）**

| 规格 | 数量 | 用途 |
|---|---|---|
| **M2×10 沉头/半沉头** | **≥ 10**（8 用 + 2 损耗） | 喇叭法兰 4 + 橙外罩 4 + P15 退路 2 |
| **M3×10 沉头/半沉头** | 已有 ✓（合壳 4 + 髋腿 8，现成 9~12 颗够） | 合壳 / 髋 / 腿 |
| M3×12 | 4（09 清单 D4） | 髋轴锁紧 |
| M4 沉头 + M4×4×6 热熔螺母 | 各 2~4 | 颈接口 P7（**唯一主受力**） |

> 手上那批 **M3×5（200 粒）+ M2×5（500 粒）** 都不够长（法兰需要 8.5 / 合壳需要 8.15），
> **别往前壳上凑，留着填配重槽。**

---

## 8. 压螺母前后各做一个 5 分钟自检

| 时机 | 动作 | 合格标准 |
|---|---|---|
| 压之前 | 卡尺量螺母**外径** | 4.5 ± 0.2（确认是 4.5 不是别的值） |
| 压之前 | 试拧一颗 M3 螺丝进螺母 | 能自由旋入 2~3 圈不打滑（确认螺纹一致） |
| 压之前 | 量孔深 | 5.5（底留 0.5 实料） |
| 压之后 | 看端面 | 与孔口齐平、无凸出 |
| 压之后 | 试拧螺丝到底 | 沉头能**完全沉进沉台**、头面与平面齐平或略低 |
| 压之后 | 反向不松 | 用手扭不转（过盈够） |

**任何一条不过，就重打孔（往里挪 1mm 重打），别凑合压。热熔螺母歪一个，那一处就永远歪。**

---

## 9. 下一步

1. ⬜ **卡尺量手上 M3×5×4.5 螺母的外径和长度**（确认 4.5 / 5，别是 M3×5×4 之类的小一号的规格）
2. ⬜ **订正装配体**：喇叭法兰那 4 个 M3 改为 M2（先把这 4 颗螺丝换了，别等打印）
3. ⬜ 下单 **M2×10 沉头/半沉头 ×10**（可以和 `09` 清单 A3 那批合并下单）
4. ⬜ P14 / P15 的孔数不变，继续按 `10` §10.2 / `13` §4 建
5. 仍空着的数：P4 喙顶 Y（卡 P15 底边）、喇叭高 52 还是 35、灯板四孔孔径与孔距

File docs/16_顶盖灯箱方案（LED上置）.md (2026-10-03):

# 顶盖灯箱方案（LED 上置）——评估与落地

> 创建：2026-10-02 23:35
> 触发：用户装配体 `测试2` 截图 —— 顶盖 `头盖<1>` 已做成**带矮墙的托盘**，两块 `彩灯开发板<1>/<2>`（10 列 × 5 行 = 50 颗 WS2812B）摆在盘底。
> 本文与 `13_橙灯框P15与浅入灯位.md`（前脸灯位 v4）是**两个互斥方案**，不是叠加。拍了哪个就废另一个。

---

## 0. 这一版装配体现在有什么

| 件 | 状态 |
|---|---|
| `前壳<1>` P1 | 已建（Ø48 过声孔、凸台、横杆、三角板） |
| `喇叭<1>` | 已建并缩小，与前壳**同心配合** ✓ |
| `后盖<1>` P2 | 已建，沉头孔已打 |
| `遮罩<1>` P14 | **橙**，盖住方兰、只露振膜 ✓ 正脸无螺丝头 ✓ |
| `头盖<1>` P3 | **橙，但已改成托盘形（有矮墙），盘内摆两块灯板** ← 本次新状态 |
| `彩灯开发板<1>/<2>` | 两块拼成 10 × 5 阵列 |
| `cross recessed countersunk head s…` | **约 30+ 颗**沉头螺丝（数量异常，见 §6） |
| 配合 | 同心 1（前壳,喇叭）/ 平行 1 / 重合 3 / 重合 4、6、7（前壳,后盖） |

**正面那一部分是做对的**：橙遮罩压住方兰，只从 Ø48 孔里露出黑振膜，"一只眼"成立，正面一颗螺丝头都没有。
**变数只在灯的位置。**

---

## 1. 先判一件：头顶放得下吗（尺寸核算）

| 项 | 值 | 判断 |
|---|---|---|
| 头顶可用面 | **96 (X) × 62 (Z)** | 头 96W × 102H × 62D，顶面就是这么大 |
| 两块灯板（含拼缝） | **80 (X) × 40 (Z)** | 39×39 两块并排 |
| 托盘内腔 | 需 ≥ 84 × 44（壁 2） | |
| 托盘外廓 | **92 × 52**（壁 5，墙高 10） | |
| **顶面对托盘的余量** | X 方向 **2mm/边**、Z 方向 **5mm/边** | ⚠️ 贴到边了，**四角 R 必须收，不能做方正大 R** |
| 灯板离盘口 | **约 13**（墙高 10 + 盘底 2.5，灯珠面在盘底之上 3） | 墙够高 → 侧向漏光被挡 ✓ |

**结论：装得下，但只剩 2mm 边距 —— 托盘必须是「顶盖 + 浅盘」的一体件，不能做成悬挑的独立大框。**

> 这条顺带解释了为什么托盘看起来比壳宽：外廓 92 对顶面 96，两边各 2mm，视觉上几乎是齐平的。**这不是误差，是算出来的。**

---

## 2. 造型判断（本节是真建议，不是尺寸）

把灯从"前脸光缝"搬到"头顶托盘"，**扩散悖论不会消失，只是换了个地方**：

| | 前脸（P15 方案） | 头顶（本方案） |
|---|---|---|
| 正/俯视看过去 | 见到一条 **16mm 高的横带** | 见到 **10 列 × 5 行的亮点阵列** |
| 单个读感 | 光带 | **像散热片 / 通风口 / 排插指示灯** |
| 加扩散板 | 5 行糊成光斑，脸没了 | 整个盘口一块柔光 → 变成"发光铭牌" |
| 与那只眼关系 | 一眼在上、光带在下，不抢 | **头顶 + 正脸两个发光体**，头部重心被拆成两半 |

**头顶是仅次于正脸的第二注意力区。** 你在头顶放 50 颗独立的方灯珠，正脸又有一只眼 —— 一件东西上两个"发光体 + 一个"眼"，比只有一个更散。MicroDuck 的头顶是干净的橙色顶盖，它的光语是"眼睛 + 底座"，不是"头顶一片"。

### 但这条方案有一个真优势，别忽视

托盘的**四壁本身就是遮光框**（墙高 10 > 灯珠离盘底 3，侧向光被吃掉大半）。
也就是说：**头顶方案天生自带光箱腔体，前脸方案还得单独挖光腔。** 这是它唯一比 P15 省事的地方。

---

## 3. 如果要做下去，三个必须补的机械点

### 3.1 盘底 2.5 太薄 —— 塞不进 M3×5×4.5 热熔螺母

热熔螺母要 **≥4.5 深**的孔才咬得住；盘底 2.5 压进去会凸到盘底外面、还会把盘底顶穿。

**两条路：**

| | 做法 | 评价 |
|---|---|---|
| **A（推荐）** | 盘底做 **4 个 Ø6 凸台、高 4.5**，台顶埋 `M3×5×4.5`（孔 Ø4.3 × 深 5.5，底留 0.5 实料） | 与全项目 `14` §5 同一套算法，打印稳定 |
| B | 盘底**不加厚到 5**，用 **自攻螺母 / T 型螺母** | 省事，但你没买，且 2.5 薄板上自攻螺母容易滑 |

**别用 VHB 直接贴**：灯板会受轴向振动（喇叭在下面振），胶会慢慢脱。托盘这个位置是**悬在声学腔正上方**的，振动比脸面大。

### 3.2 螺丝从哪面拧 —— 头顶要"从下往上拧"

灯板四角孔是 **M3 沉孔**（实物照见 `12` §0）。螺丝头沉进板的沉孔 → **板顶面齐平、头顶看不到一颗螺丝头** ✓（这条本来就成立）。

但要进到底下的凸台，螺丝只能**从盘底往上穿**（从盘口往下拧的话，头就压在板正面了 —— 等于头顶顶着 4 颗黑十字）。

| 项 | 值 |
|---|---|
| 长度核算 | 螺丝头沉台 1.65（在板内）+ 板厚 2.8 + 咬合凸台里螺母 2.0 = **6.45** |
| 建议 | **M3×10 沉头**（杆长富余 3.5，且 `15` §4.2 有冗余） |
| **别用** | M3×8（杆 7.35，富余 0.9，太险） |

> 顺带：这跟前脸那套 `M2×10` 是**反过来**的 —— 前脸"从腔内往里拧"，头顶"从盘底往外穿"。头壳上现在有 M2 和 M3 两个方向的螺丝，别混。

### 3.3 出线：头顶的灯要走了头顶 → 头内 → 脖子 → 身，三段

这是头顶方案**最大的代价** —— 灯不在脸上了，线就得从头顶绕一大圈：

```
盘壁开 Ø10 过线槽  →  头内（声学腔上方）  →  头底颈接口  →  颈 P7 内  →  身腔
```

三处过线孔**每一处都要硅胶封**（`10` §10.2b 的老规矩）：
1. 托盘侧壁的过线槽；
2. 头底通往颈的 Ø12 孔（DC 座那个孔已经占用下沿，别撞）；
3. 颈 P7 里那 2 根 M4 螺纹杆之间 —— **两根 M4 之间要留 ≥12mm 净宽**给线束，否则出不去。

> ⚠️ 头顶走线**穿过声学腔上方**。喇叭振膜在正面、腔体在 P1 碗里，线束只要不贴着前脸走、`不在振膜正后方摆`,就不会影响声学。但**线卡要固定在盘底或顶壁，不要悬在腔中间晃**。

---

## 4. 固件：头顶方案下，只点一行（这条是本方案的关键补丁）

50 颗全亮 = 头顶 10×5 亮点阵列 = 散热片。

**只点亮中间那一行（10 颗）→ 阵列退化成一条线 → 直接自证为"光带"。**

| 项 | 值 |
|---|---|
| 点亮的 | 第 3 行（10 颗），其余 4 行全灭 |
| 读出来 | 头顶一条**贯穿前后**的光棱，长 80、灯距 8 |
| 电流 | 10 颗 ≈ **0.6 A**（远低于 `03` 定的 1.6A 持续 / 亮度上限 120/255 的约束） |
| 动效 | 仍是训练曲线（10 段柱高随音乐起伏），开机从左→右扫一次 |

**这跟前脸 P15 的"训练曲线"是同一个主语，只是换了位置。** 主题没变 —— 一条 curve，不是一张脸。

---

## 5. 决策表

| | **顶盖灯箱（本方案）** | **前脸橙灯框 P15（`13` 方案）** |
|---|---|---|
| 托盘/橙件 | P3 已做成托盘，有矮墙自带光箱 | P15 新件 84×30×4，窗 78×16 贯穿 |
| 头顶余量 | X 只剩 2mm/边 ⚠️ | 不动头顶 |
| 造型 | 头顶一片灯阵列；与"眼"成两个发光体 | 正脸横槽；一眼一光带，主次清楚 |
| 扩散悖论 | **仍在**（点阵 ↔ 光斑，中间态最糟） | 同样在，但 16mm 只露 2 行灯珠，悖论最轻 |
| 走线 | **头内绕一大圈 + 3 处封孔** | 板贴脸外表面 → 下沿 0.5mm 缝进腔 → 颈（更短） |
| 装配顺序 | 先灯板 → 再扣托盘盖（框压灯两端）→ 再合 P2 | 先贴灯板 → 扣 P15 → 压 P14 → 合 P2 |
| 缺少 | 托盘要加 4 个凸台 + 过线槽 | 要新建 P15；且 P4 喙要给灯让位（橙框占 −21~−51） |
| **代价** | 头顶灯阵 + 走线绕远 + 顶面只剩 2mm 余量 | 砍/归并喙 + 正脸下部被橙占据 |
| **如果已经打印** | **P3 现在还没打，改还来得及** | P14 已建、P15 未建 |

---

## 6. 这张图里两件必须查的事

### 6.1 装配树里有 30+ 颗 "cross recessed countersunk head"

我们全项目规划的螺丝总量是 **12 颗左右**（喇叭法兰 4 + 橙外罩 4 + 合壳 4 + 髋腿若干），**这里一下冒出 30+**。

请点开任意一颗看它的**配合/钉入面**，分辨三类：
1. 落在 **P1 凸台顶** = 锁喇叭法兰（正常，本来就该从正面拧，靠遮罩盖住）；
2. 落在 **P14 遮罩** = 从前打螺丝 → **与前盖的意义直接冲突**，要改成腔内拧；
3. 落在 **P3 顶盖 / 灯板** = 头顶这批，按 §3.2 重算。

> 数量对不上本身不是罪（可能只是把块显示成了多实例），但**每一颗都得有名字**，装配树里 30 个同名 `cross recessed countersunk head` 是以后做 BOM 和采购的灾难。

### 6.2 头顶托盘有没有开过线孔

盘壁上**必须有一个 Ø10 过线槽**（§3.3）。如果现在盘壁是封死的 —— 灯板线只能走盘外、绕到壳外，那就是"外部看得见线"，直接踩完成度红线。

---

## 7. 我的建议（一句话）

**头顶方案能做，但要做成「只点中间一行」的 10 颗光棱 —— 不要 50 颗全亮。**

理由不是省电，是**50 颗点阵 = 散热片，10 颗一条线 = 光带**。二者在头顶这个位置差别是"廉价电子件"和"设计语言"的差别。

如果按这条走，`13` 的 P15 橙灯框**就不用建了**，前脸回到「橙顶盖 / 橙眼罩 / 奶油脸」三块——干净，喙（P4）可以按原样保留，**不用为灯让位**。这反过来补回了一个我们为了灯差点砍掉的东西。

---

## 8. 待确认

1. **灯板是 2 块还是 3 块？** 树里只有 `彩灯开发板<1>/<2>` 两个实例，但 10×5 = 两块、15×5 = 三块，请确认（影响盘长 80 vs 120，**120 在 62 深的方向绝对放不下**）。
2. 30+ 颗螺丝的归属（§6.1）。
3. 托盘侧壁过线槽开在哪面、是否已开（§6.2）。
4. 头顶若只点 1 行，是否接受"灯只有 10 颗"这个数量感。

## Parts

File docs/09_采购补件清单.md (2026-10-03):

# 09 · 采购补件清单（建模定型后暴露的缺口）

> 生成：2026-10-02　状态：**动态清单**——每建完一个零件，把新暴露的件加进「A 必买」。
> 原始采购清单见 `02-零件尺寸基准表.md`，本文只记**原始清单里没有、建模后才暴露**的件。
> 图例：✅ 已购　⬜ 待买　➕ 建议补　❓ 待定

## 0. 一句话：会卡住项目的三件

| # | 件 | 为什么非买不可 |
|---|---|---|
| 1 | **3D 打印耗材 PETG** | 原始清单里**完全没有**这一项，而外壳 13 件全靠它。这是最大的隐性支出 |
| 2 | **12V 电源适配器** | 功放板 12V 输入，原始清单没有。不买 = 整机点不亮 |
| 3 | **M2×8 沉头机丝** | 前脸固定喇叭法兰用的（你手上 M2×5 螺纹只有 3.8mm，锁不住） |

其余都是「影响完成度」或「影响手感」，不买不至于装不起来。

---

## A. 必买 —— 不买就装不起来

| # | 品类 | 规格 | 数量 | 用在哪 | 状态 |
|---|---|---|---|---|---|
| A1 | **PETG 3D 打印耗材** 1.75mm | 密度 1.27；**三色**：奶油 `#EFE3C8` / 橙 `#F26B21` / 黑 `#23262B` | 三色各约 0.6kg，共 **1.5–2kg** | 13 件打印件 + 试错重打 | ⬜ |
| A2 | **12V 电源适配器** | **12V / ≥2A**、DC 头**中心正极**、Plug Ø5.5×2.1 公头 | 1 | 功放板供电。20W 功放峰值约 1.7A，买 2A 才不压降 | ⬜ |
| A3 | **M2×8 沉头机丝**（铁黑） | 头径约 Ø4、总长 8 | 8 颗 | 前脸 4 凸台固定喇叭法兰（配 M2×3×3 热熔螺母） | ⬜ |
| A4 | **2mm 闭孔泡棉片** | 厚 2mm、宽 ≥10mm，**闭孔**（EVA/EPDM/Rubber） | 一片 A4 大小 | 喇叭法兰与壳面之间的气封环（法兰贴壳外，泡棉夹中间） | ⬜ |
| A5 | **M4 热熔铜螺母** | 常见 M4×4×6（外径 Ø6.0 / 长 4.0），**买前量一下手上的规格** | **2–4 个** | 颈部 P7 接口 2×M4（全头唯一主受力连接，这个规格原始清单没有） | ⬜ |
| A6 | **焊锡丝 + 助焊剂** | 63/37 含铅易焊；松香或助焊剂各一 | 小卷 | 清单里电烙铁有了但**没写焊锡**，没锡烙铁是摆设 | ⬜ |
| A7 | **导热硅胶垫** | 厚 1.0–1.5mm，自粘型 | 一片（裁 40×40） | 功放芯片 → 配重钢板散热。**不是导热硅脂**（模块要反复拆，硅脂会弄脏板） | ⬜ |
| A8 | **过线孔密封胶** | 电子硅酮密封胶（透明）或普通热熔胶棒 | 1 支 | Ø10 过线孔穿线后封死（声学腔唯一开口，不封就漏） | ⬜ |
| A9 | **配重钢板 / 铅配重片** | 见下方「配重订正」 | 一块 | 底壳 60×40 配重槽，降重心抗倾覆 | ⬜ |
| A10 | **M3 热熔铜螺母补货** | M3×5×4.5 | **+20 个**（凑 40） | 原有 20 个：合壳 8 + 腿 8 + 髋 4 = 20，**刚好用完无余量**，补 20 留调试损耗 | ➕ |

### A9 配重订正（重要，我前面给的数不现实）

之前写的「150g 钢板塞进 60×40 槽」按钢密度 7.8 反推需要 **8mm 厚**——底壳是薄壳结构，放不下这么厚的料。三种现实做法：

| 方案 | 用量 | 重量 | 评价 |
|---|---|---|---|
| 60×40×**3mm** 镀锌钢板 | 1 块 | ≈56g | 最省事，能买到的常规规格 |
| 3mm 钢板 + 随手塞 M3/M2 螺丝 | 20 颗 | ≈85g | **推荐**：钢板 + 螺丝凑 ≈90g，重心降到约 105mm，抗倾覆够用 |
| 铅配重片（密度 11.3） | 60×40×4mm | ≈107g | 最压得住，但铅料要专门买、切割难 |

**结论：买一块 60×40×3 镀锌钢板（≈56g），装配时往配重槽里再塞十来颗 M3/M2 沉头螺丝凑到 ~90g。** 抗倾覆角按 ~25–30° 评估，够。

---

## B. 完成度相关 —— 不买不扣分，买了明显上台阶

上一届完成度红线是「**看不出打印层纹、拼缝对齐**」。这一档的钱花得最值。

| # | 品类 | 规格 | 数量 | 用在哪 | 状态 |
|---|---|---|---|---|---|
| B1 | **砂纸** | 400 / 800 / 1500（干磨）+ 2000（可选） | 每号 10 片起 | 13 件全要过一遍打磨。**千目消耗最快**，多备 | ⬜ |
| B2 | **打磨海绵 / 橡胶磨块** | 40×40×5，粗细各 2 块 | 4 块 | 处理圆角和凹槽里的层纹，砂纸够不到的地方 | ⬜ |
| B3 | **底漆喷罐（白色/灰）** | 自喷罐，PETG 需先轻打磨 | 2 罐 | 填层纹、统一底色。**PETG 难粘漆，底漆前一定要把脱模剂擦掉** | ⬜ |
| B4 | **面漆喷罐** | 奶油 / 橙 / 黑 三色哑光 | 各 1 罐 | 最终色。三色件分开喷，喷前盖好报纸 | ⬜ |
| B5 | **塑料补土 / 原子灰** | 模型补土膏 | 1 支 | 补拼缝、气孔、层纹坑洼，干了再磨平 | ⬜ |
| B6 | **脚底硅胶防滑垫** | 40×32 一片，或 3M 防滑贴 | 4 片 | 脚掌底面，防滑 + 隔振 | ⬜ |
| B7 | **附着力促进剂 / 去脂剂** | 酒精或涂料附着力剂 | 1 小瓶 | 酒精就行（擦油去尘），涂料附着力促进剂是进阶选项 | ➕ |

> B 这一档合计约 ¥100–140。对你「怕工作量」的顾虑来说，**这钱比省时间更划算**：喷漆三件套做完，层纹全看不见，完成度一下子跨一档。

---

## C. 电子与装配耗材

| # | 品类 | 规格 | 数量 | 用在哪 | 状态 |
|---|---|---|---|---|---|
| C1 | **热熔胶枪 + 胶棒** | 20–30W 小枪，φ7 胶棒 | 1 套 | 固定线束、堵次要缝隙 | ⬜ |
| C2 | **热缩管** | φ2 / φ3 / φ5，黑色为主 | 各 1 卷 | 24AWG 跳线接头绝缘收口 | ⬜ |
| C3 | **尼龙扎带** | 2×100mm | 20 条 | 整机理线（「外面看不见一根线」这条靠它） | ⬜ |
| C4 | **金属小锉刀** | 5 把套装（含半圆锉） | 1 套 | **强烈推荐**：学生件孔位偏 0.3–0.5mm 是常态，全靠锉修 | ⬜ |
| C5 | **内六角扳手** | 2.5 / 3mm | 2 把 | 腿部锁紧若用内六角螺栓 | ➕ |
| C6 | **精密螺丝刀** | 清单里已有（小米/hoto） | — | 不用重复买 | ✅ |

---

## D. 可买可不买 / 别急

| # | 品类 | 说明 |
|---|---|---|
| D1 | **第 3 块 WS2812B 灯板** | 头内宽 91mm 只放得下 2 块（78mm）。**去向未定**（侧光 / 底光 / 闲置），先别买 |
| D2 | **光腔扩散板** | 可用白色 PETG 打印一片直接当散射，**不必专门买亚克力/扩散片** |
| D3 | **舵机** | 腿是 12 档静态定位齿盘（课程定位是建模课，不做强化学习）。想让腿动起来才需要，**现在别买** |
| D4 | **M3×12 沉头机丝** | 髋轴锁紧用 4 颗。可用已购 M3×10 先顶上，不够再补 |
| D5 | **杜邦线 / 排针** | 清单里的 140 条 24AWG 镀锡跳线够用，除非要走可插拔接插件 |

---

## E. 对照：原始清单里已有的（**别重复下单**）

| 件 | 状态 |
|---|---|
| 蓝牙功放板 12V / 10–20W | ✅ |
| 52mm 全频喇叭一对（4Ω 10W） | ✅ |
| 24AWG 镀锡跳线 140 条 | ✅ |
| 热熔铜螺母 M3×5×4.5（20 个） / M2×3×3（50 个） | ✅（M3 建议补 A10） |
| 沉头螺丝 M3×5（200 粒） / M2×5（500 粒） | ✅（这两批前脸/合壳都用不上，留作存货与配重） |
| 拨动开关 SS12F15V / 金属按钮 Ø10 / DC022 电源座 | ✅ |
| DC-DC 降压模块 固定 5V / WS2812B 5×5×3 / ESP32-C3-Zero | ✅ |
| **M3×10 沉头机丝（你已另购）** | ✅ 合壳专用，别动 |
| 电烙铁、精密螺丝刀、游标卡尺、万用表、焊接台 | ✅ |

---

## 预算速算（不含打印机与已购件）

| 档 | 金额 |
|---|---|
| A 必买（含 PETG 1.5–2kg） | ¥280 – ¥330 |
| B 完成度 | ¥100 – ¥140 |
| C 装配耗材 | ¥70 – ¥90 |
| **合计** | **¥450 – ¥560** |

> 大头是 **PETG（约 ¥150–200）** 和 **喷漆三件套（约 ¥100）**。

---

## 建议的下单顺序（三批，别一次囤完）

**第一批（建模一完成就下单，最晚别拖过本周）**
A1 耗材、A2 电源、A3 M2×8、A5 M4 热熔螺母、A10 M3 螺母补货
→ 理由：这五件决定"能不能进入装配验证"，晚到就卡在原地。

**第二批（开始打件/打磨时）**
A6 焊锡、A7 导热垫、A8 密封胶、A9 配重钢板、C1–C4、B1/B2 砂纸磨块
→ 理由：装电子和动手改件时才需要。

**第三批（件快打完、要上漆时）**
B3 底漆、B4 面漆、B5 补土、B6 防滑垫、B7 酒精
→ 理由：等三视图定稿、确认不再改尺寸再买漆，免得买了又要改色。

---

## ⚠️ 三条还没闭环的硬未知数（会影响上面部分数量）

1. **喇叭总高 52 vs 你手写实测 35** —— 影响后腔深度与光腔位置，量完可能要改 1–2 件Print 数量。
2. **第三块 LED 板去向** —— 定了才知道要不要买（D1）。
3. **老师是否要求提交实物照片/测试记录** —— 若要声学测试，A4 泡棉的规格（2mm 闭孔）更要买对，**别用普通海绵/eva 泡棉代替**（闭孔才不吸水、不压扁后回弹差）。

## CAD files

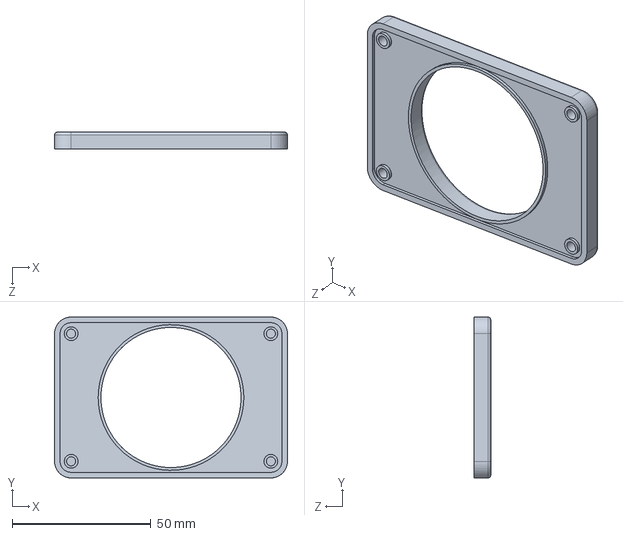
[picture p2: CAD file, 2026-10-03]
cad/遮罩.SLDPRT
84.0 x 58.0 x 6.00 mm

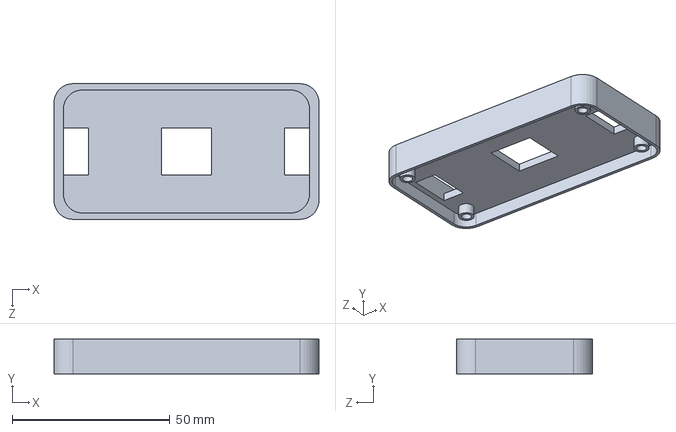
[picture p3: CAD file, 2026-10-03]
cad/头盖.SLDPRT
84.0 x 11.0 x 43.0 mm

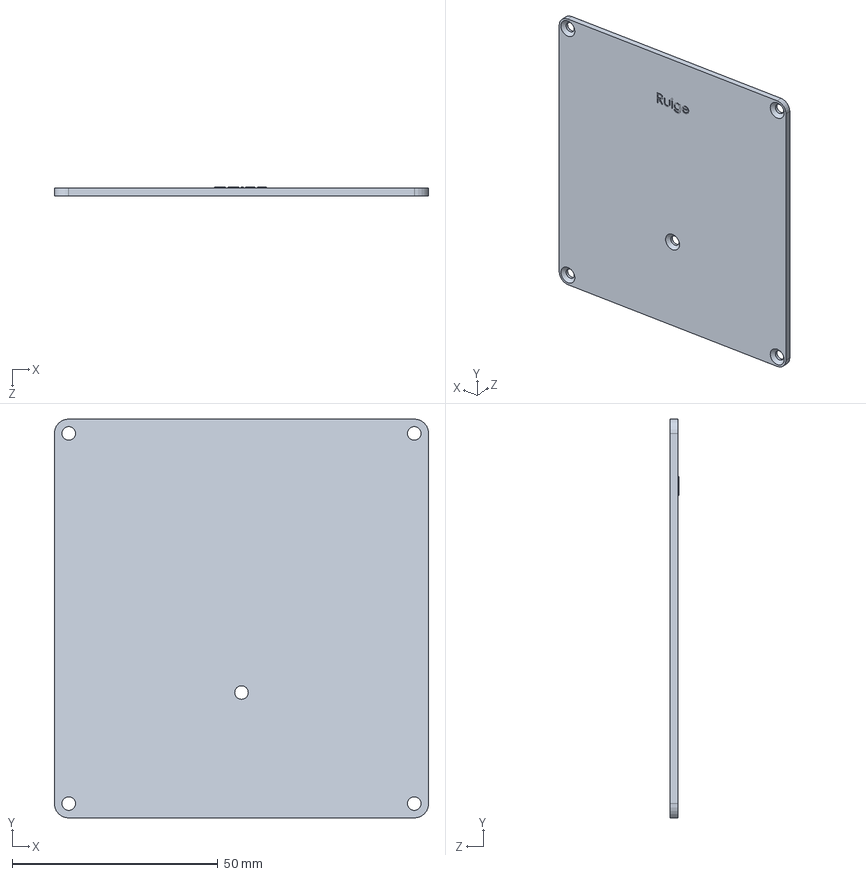
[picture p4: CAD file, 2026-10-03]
cad/后盖.SLDPRT
91.0 x 97.0 x 2.20 mm

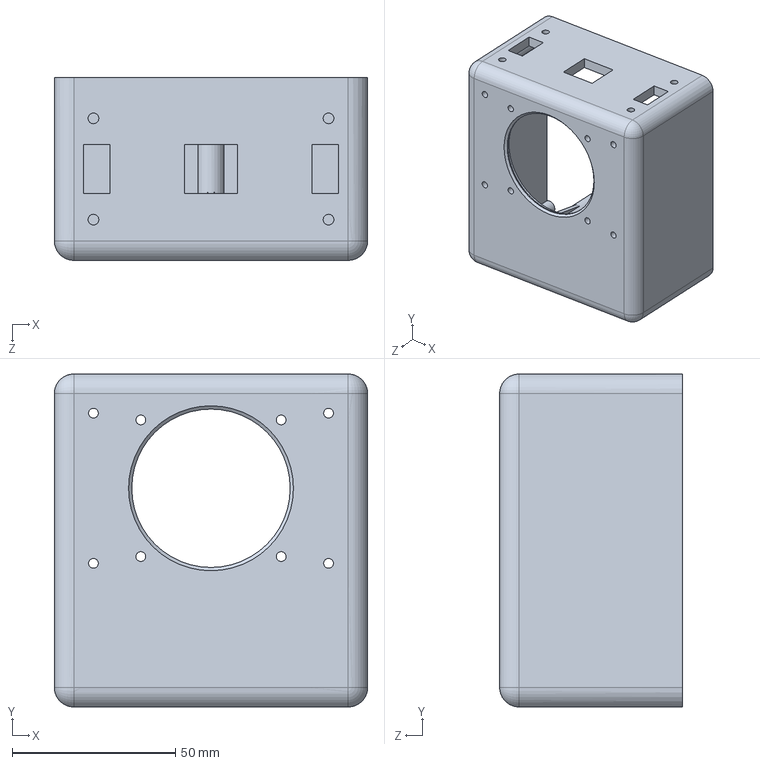
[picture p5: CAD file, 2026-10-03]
cad/前壳.SLDPRT
96.0 x 102.0 x 56.0 mm

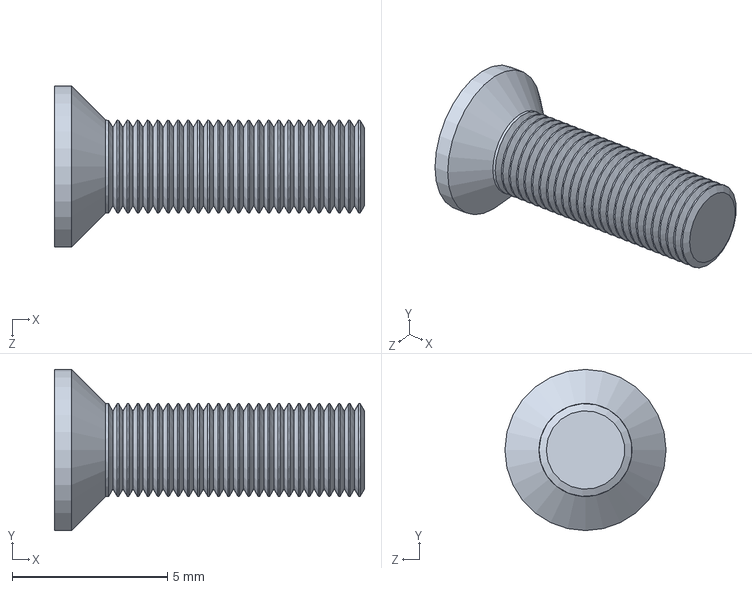
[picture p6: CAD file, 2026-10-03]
cad/螺丝M3x10.SLDPRT
10.0 x 5.20 x 5.20 mm

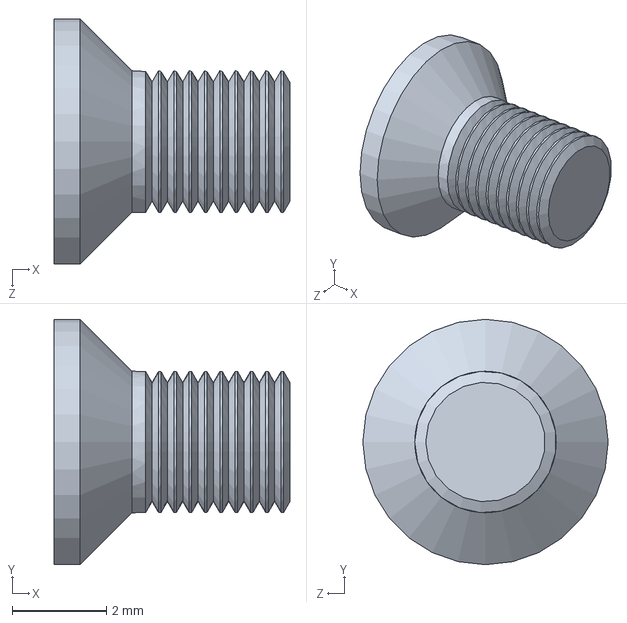
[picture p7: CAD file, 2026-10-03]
cad/螺丝M3x5.SLDPRT
5.00 x 5.20 x 5.20 mm

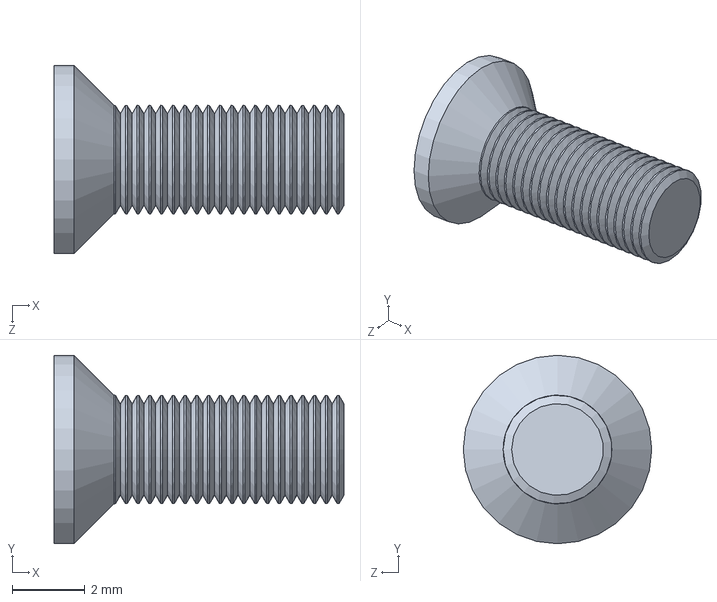
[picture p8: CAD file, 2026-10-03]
cad/螺丝M3x8.SLDPRT
8.00 x 5.20 x 5.20 mm

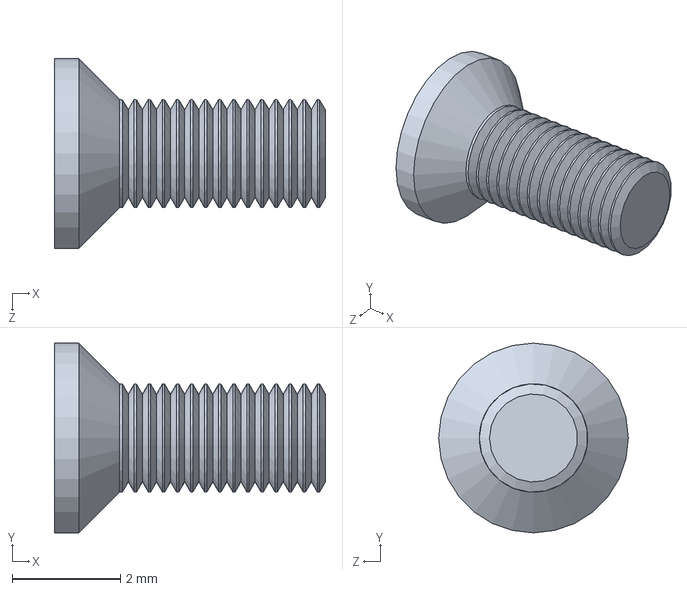
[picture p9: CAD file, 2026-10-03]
cad/螺丝M2x5.SLDPRT
5.00 x 3.50 x 3.50 mm

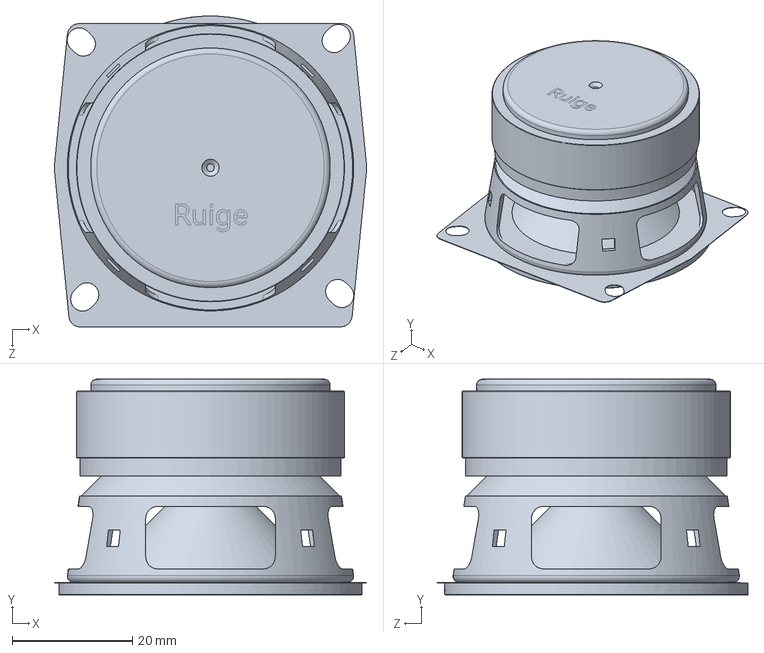
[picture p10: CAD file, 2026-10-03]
cad/喇叭.SLDPRT
52.0 x 35.9 x 51.8 mm

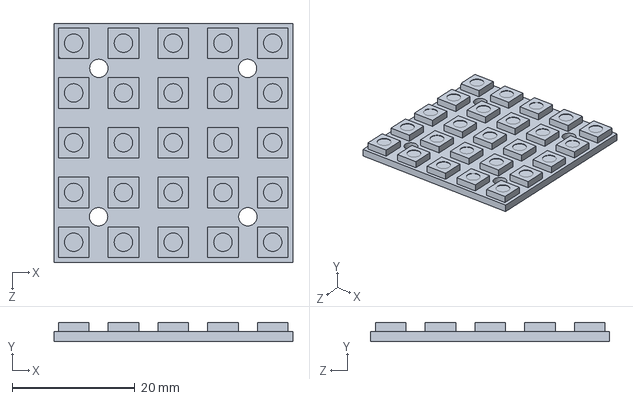
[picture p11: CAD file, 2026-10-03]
cad/彩灯开发板.SLDPRT
38.9 x 3.10 x 38.9 mm

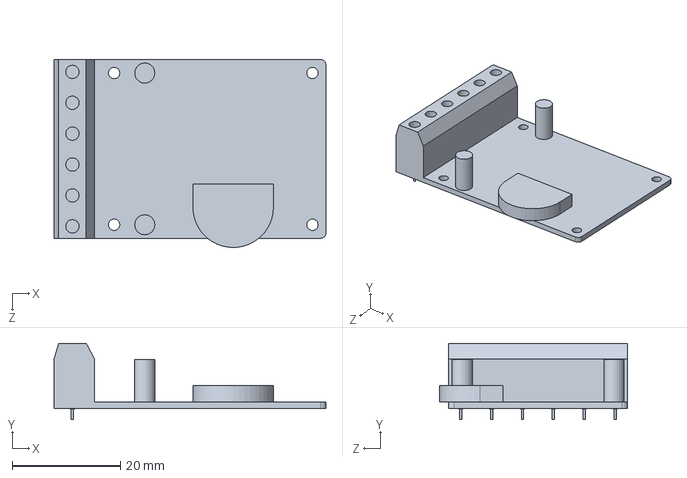
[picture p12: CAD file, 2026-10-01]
cad/功放板.SLDPRT
50.2 x 14.1 x 34.7 mm

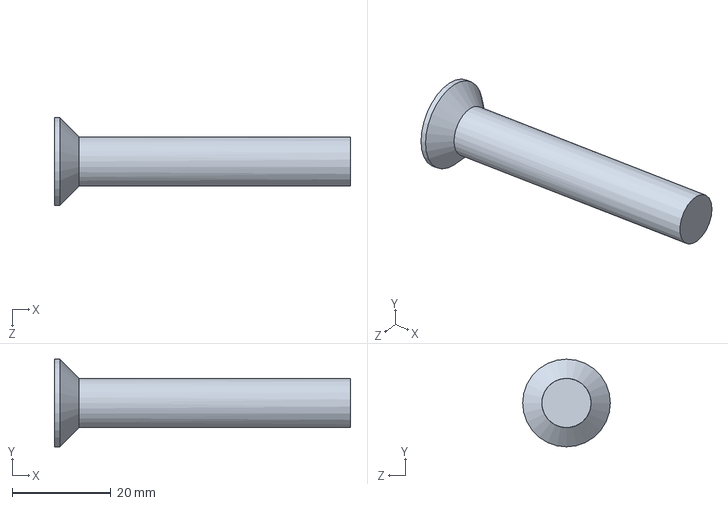
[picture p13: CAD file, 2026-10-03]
cad/cross recessed countersunk head screws gb1.SLDPRT
60.0 x 17.8 x 17.8 mm

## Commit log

2026-09-28 Init: Learned Duck —— 一台致敬 MicroDuck 的 3D 打印智能蓝牙音箱
    首个提交：项目文档与设计资料（CAD 模型与固件尚未完成）
    - README：项目定位、致敬说明与 7 处落点、BOM、四段式结构尺寸、
    电子架构、电流限制、打印与后处理、12 步装配、灯光系统与预留接口
    - docs/：零件测绘表、内部结构分析、喙尺寸图、内部堆叠与机构详图
    - LICENSE：硬件设计 CC BY-NC-SA 4.0 ＋ 固件代码 MIT（分开授权）
    - cad/ 与 firmware/：目录与导出约定占位，模型和代码待补
    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
2026-10-01 docs: 新增零件尺寸基准表（数据来源分级）
    - 从采购清单提取官方尺寸：降压模块 22.3x17、DC022 开孔 Ø12、按钮 Ø10、热熔螺母与沉头螺丝规格
    - 记录两条改变设计的发现：喇叭是方框法兰（正面沉台须改方）；降压模块持续电流仅 1.6A（亮度上限有了硬依据）
    - .gitignore 补入 SolidWorks 日志与自动恢复文件规则
2026-10-01 cad: 新增喇叭 SLDPRT 模型
    [喇叭.SLDPRT]
2026-10-01 docs: 闭合功放板尺寸 —— 实测最长边 50.2，身壳不变
2026-10-01 cad: 新增功放板 SLDPRT 模型
    [功放板.SLDPRT]
2026-10-03 cad: 头壳主体零件建模（前壳/后盖/橙遮罩/橙顶盖/彩灯板/喇叭）
    [前壳.SLDPRT, 后盖.SLDPRT, 喇叭.SLDPRT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]
2026-10-03 cad: 紧固件标准件模型（M2×5 / M3×5 / M3×8 / M3×10 / GB沉头）
    [cross recessed countersunk head screws gb1.SLDPRT, 螺丝M2x5.SLDPRT, 螺丝M3x10.SLDPRT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]
2026-10-03 chore: 忽略建模过程稿（装配体草稿与一次性脚本）
2026-10-03 docs: 闭合功放板尺寸并补采购盲区（12V/3A 适配器、20AWG 线、M2×10）
2026-10-03 docs: 外盖 P14 / 橙灯框 P15 / 灯板安装（浅入灯位与固定方案）
2026-10-03 docs: 灯光方案评估与顶盖灯箱（LED 上置）决策
2026-10-03 docs: 螺丝与热熔螺母配对体系 + 紧固件知识手册
2026-10-03 docs: 电路系统设计与接线（架构选型、电源树、颈内走线空间账）
2026-10-03 docs: README 对齐最终方案（顶盖灯箱、电路架构 A、电源树与 BOM）+ 里程碑表
2026-10-03 修改模型
    [前壳.SLDPRT, 后盖.SLDPRT, 头盖.SLDPRT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]
2026-10-03 docs: 电路接线表纠正为单声道单喇叭（只接 OUT L，OUT R 悬空）
2026-10-03 chore: 概念渲染过程稿移出仓库（22 张过程图约 20MB）
2026-10-03 docs: 新增台面接线手把手手册（5 阶段流程 + 停手点 + 故障速查 + 记录表）
2026-11-05 docs: 收缩为基础版（只做头单体，砍掉灯/ESP32/降压），电路重写为五根线
2026-11-08 cad: 零件整理进 1108 目录，补喇叭与装配体
2026-11-08 docs: 移除设计文档，README 收为标题与许可
2026-11-08 chore: 移除 firmware 目录（方案收缩后不再做固件）
